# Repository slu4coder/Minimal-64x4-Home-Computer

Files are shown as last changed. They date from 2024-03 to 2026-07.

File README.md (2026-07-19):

# Minimal 64x4 Redux Home Computer

Here is my latest take on 1980's home computer magic: The most computer from the least logic or the shortest way from TTL to Space Invaders.

This is a free and non-commercial project. I am in no way associated with any activies selling the Minimal 64x4 as a product.
Any such activity represents a license violation. Individual licenses apply for hardware and software parts. Please refer to the
applicable documentations for detailed licensing information.

grafik
Introductory video: https://www.youtube.com/watch?v=L1oECH6rPvs

Online emulator: https://editor.p5js.org/slu4coder/sketches/lRq1gyYR2

Reference manual: https://docs.google.com/document/d/1-nDv_8WEG1FrlO3kEK0icoYo-Z-jlhpCMiCstxGOCjQ/edit?usp=sharing

Visit my YouTube channel: https://www.youtube.com/channel/UCXYQcMpUBT3aaQKfmAVJNow

Take a look at these repositories of fellow Minimal 64x4 enthusiasts for more games and fascinating projects:

https://github.com/hans61/Minimal-64x4-Games

https://github.com/hans61/Minimal-64x4-Expansion

https://github.com/michaelkamprath/minimal-64x4-expansion-cards

https://github.com/michaelkamprath/extended-min

https://github.com/hellboy73

FEATURES

● Only 57 74HCxx logic ICs, 2x 6C1008 SRAM, 4x 39SF0x0 FLASH, NO MICROCONTROLLER!

● Textbook 'Von-Neumann' architecture, 8-bit data bus, 16-bit address bus, 24 control signals

● 64KB RAM, 512KB FLASH SSD with file system (format, load, save, dir, delete)

● Monochrome VGA output 400 x 240 pixels, PS/2, expansion port and serial UART interface

● 8MHz CPU clockrate, 1.8Mips - that's more than 4x the commonly quoted Mips value of a 6502 running at 1MHz like in a Commodore C64 or Apple II

● 256 instructions including conditional branching, subroutines, stack, word, long and zero-page operations

● 2 data registers A & B, ALU supporting ADD, SUBTRACT, AND, OR with 3 flags (negative, carry and zero)

● Full native tool-chain: MinOS, text editor, assembler, fast Python-like interpreter 'MIN'

● Cycle-exact emulator, cross-assembler (both for Windows and Linux) and classic games (TETRIS clone, Space Invaders clone, 3D Maze)

If you like this project and want to give something back, you can do so via PayPal. Thanks!

https://paypal.me/CarstenHerting
  
Have fun!

See "CHANGE LOG" for a brief summary of the recent updates.

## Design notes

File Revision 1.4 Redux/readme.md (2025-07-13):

# Revision 1.4 Redux

I have designed the Redux just for fun to make it even more minimalistic: It uses 4 ICs less than the original, which I consider quite an achievement ;-)
It is *not* fully software-compatible (although the differences are slight) to the original Minimal 64x4 since it features an improved and more orthogonal instruction set with some small microcode tweaks. The OS and API have seen improvements, too, resulting in an overall 5% performance gain and a slightly snappier feel.
The serial interface now runs on 7 data bits and the serial OUT command features hardware waiting, which was a fun thing to implement.

The folder 'KiCAD9' contains the schematics and PCB layout files.
For the bill of materials (BOM) please refer to chapter 'Hardware' of the 'Minimal 64x4 Reference Manual'. Follow the link in the root readme.md of this repo.

The folder 'Support' contains the cross-platform assembler und the emulator (Win).
The folder 'Programs' contains native Minimal 64x4 Redux code.

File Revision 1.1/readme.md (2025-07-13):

# Revision 1.1 (Original Release)

The folder 'KiCAD' contains KiCAD 6 schematics. The folder 'KiCAD8' contains the same schematics with minor cosmetic updates, converted to KiCAD8.
For the bill of materials (BOM) please refer to chapter 'Hardware' of the 'Minimal 64x4 Reference Manual'. Follow the link in the root readme.md of this repo.

The folder 'Support' contains the cross-platform assembler und the emulator (Win).
The folder 'Programs' contains native Minimal 64x4 code.

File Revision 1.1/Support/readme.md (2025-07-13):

# Supporting Tool-Chain

o Cross-platform assembler (Windows)

o Emulator (Windows, requires SSD image file 'flash.bin')

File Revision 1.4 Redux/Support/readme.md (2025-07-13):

# Supporting Tool-Chain

o Cross-platform assembler (Windows, Linux)

o Emulator (Windows, Linux, requires SSD image file 'flash.bin')

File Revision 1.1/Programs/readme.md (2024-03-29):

# Native Software of the 'Minimal 64x4 Home Computer'

o '.asm' denotes assembly source code.

o '.min' denotes 'Min' source code.

o 'manual.txt' is displayed by the 'Minimal 64x4' upon entering 'show manual'.

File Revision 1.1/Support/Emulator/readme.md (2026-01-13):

# Cycle-exact Minimal 64x4 Emulator (C++/OpenGL)

PLEASE NOTE: The FLASH image file 'flash.bin' (see section 'Revision .../FLASH Images') needs to reside in the same directory as the emulator.

On some graphic cards, 60Hz VSYNC is not detected correctly. In that case, set the frame rate manually to 60Hz from within your graphic card's control center.

Please note that the C++/OpenGL source code of this emulator (~6000 lines of code) is intentionally not available for download.

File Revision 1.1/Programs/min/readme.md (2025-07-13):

# 'Min' Programs

'Min' is a Python-like high-level programming language running natively on the 'Minimal 64x4'.
The interpreter [min.asm](../asm/min.asm) assembly source code is located in the '../asm' section.

See Min's EBNF language definition for more information.

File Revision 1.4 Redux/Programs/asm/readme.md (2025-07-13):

# Native Software of the 'Minimal 64x4 Redux'

o '.asm' denotes assembly source code.

o '.min' denotes 'Min' source code.

o 'manual.txt' is displayed by the 'Minimal 64x4 Redux' upon entering 'show manual'.

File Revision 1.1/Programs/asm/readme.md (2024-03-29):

# Assembly Programs

Assembly code (OS, native tool-chain, games, demos) written for the 'Minimal 64x4'.

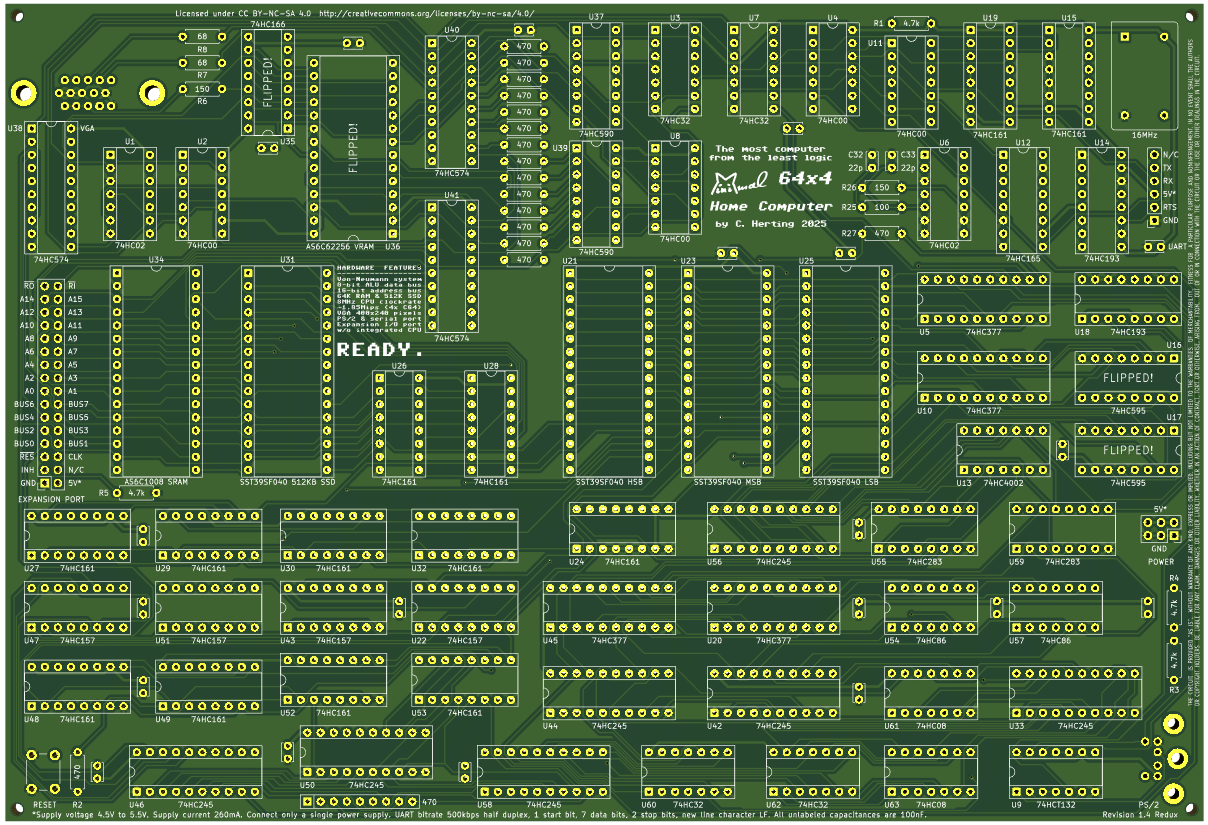
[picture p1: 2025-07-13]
Revision 1.4 Redux/Layout.png

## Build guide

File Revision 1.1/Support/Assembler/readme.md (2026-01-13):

Cross-platform assembler of the Minimal 64x4 written in C++.

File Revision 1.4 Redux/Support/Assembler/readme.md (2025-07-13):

# Cross-platform assembler

Build with: g++ asm.cpp -O2 -oasm.exe -s

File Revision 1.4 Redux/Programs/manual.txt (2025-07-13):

-------------------------------------------------
MINIMAL 64x4 1.4 Redux  COMPUTER  MANUAL  by slu4
-------------------------------------------------

Welcome to the 'MINIMAL 64x4'. This file provides
a brief introduction on how to use this computer.

1. OS COMMANDS (1/2)

The  'MinOS'  operating system loads and executes
any entered  filename as a  separate program.  So
any file can be considered an 'OS command'. MinOS
comes with the following built-in commands
(parameters in square [] brackets are optional):

'run' [<x>] starts execution at hex address <x>
            (default start address is 0x0100).

'dir'  displays the file directory of the SSD.

'del <file>'  deletes a file on the SSD.

'show <file>'  displays a text file page by page.

'format'  formats  SSD  user area (banks 3..127).

'defrag'  frees up unused  SSD storage fragments.

'memset <x> <y> <d>' fills RAM <x>..<y> with <d>.%
1. OS COMMANDS (2/2)

'mon [<x>]'  starts  a  memory  monitor [at <x>].
  ESC        exits the monitor to the  OS prompt.
  <x>        changes the  monitor address to <x>.
  k<x>       sets the bank register to <x>.
  [<x>].<y>  displays an address range.
  :<d>[ <d>] deposits  <d> at  current address++.
  #<x>       activates SSD bank <x>, 0x80 for RAM
  <x>, <y>, <d> can be a HEX value '0' to 'ffff'.

'memmove <x> <y> <z>'  moves memory area <x>..<y>
  to <z>. Source and destination may overlap.

'receive'  receives an 'Intel HEX File' you paste
  via UART terminal and writes the data into RAM.
  OS FLASH images generated by  'asm os.asm'  are
  automatically detected and written 'in situ' to
  the FLASH sectors 0..2.

'save <x> <y> <name>'  saves memory area <x>..<y>
  under the filename <name> onto the SSD.
  
After boot-up,  MinOS  searches for a  batch file
'autostart'. Any filename in 'autostart'  will be
executed as a subroutine.
To force booting without 'autostart', hold RESET,
press ESC on the PS/2 keyboard and release RESET.%
2. MEMORY MAP

0x0000..0x0fff  4KB FLASH/RAM  depending on bank:
                0x00:        OS kernel image
                0x01:        OS data
                0x02:        OS command files
                0x03..0x7f:  user SSD storage
                0x80..0xff:  RAM (FLASH disabled)

0x0000..  00ff ZERO PAGE (256 bytes):
  0080..  00ff OS variables
  00cd..  00fe OS line input buffer (50 bytes)
  00ff         system register

0x0000..0x3fff 16KB RAM:
  0100..  0fff text editor 'edit'
  1000..  1fff smart assembler 'asm'
  1000..  3fff high-level language 'min'

0x4000..0x7fff 16KB VIDEO RAM (64 x 256 bytes):
  430c         start of 400 x 240 pixels viewport

0x8000..0xefff 28KB RAM:
  f000..  fbff OS kernel & API functions
  fc00..  fdff OS commands
  fe00..  feff reserved for expansion cards

0xff00..0xffff CPU STACK (256 bytes):
  ffff         stack pointer LSB%
3. TEXT EDITOR 'edit [<file>]'

The text editor resides  in RAM at 0x0100..0x0fff
and also uses  0x3f00..0x3fff for temporary data.
Text data  is stored from address 0x8000 onwards.
Once  loaded,  the  editor  can  be  restarted by
typing 'run', preserving your text document.

CTRL q   or ESC quits the editor.
CTRL n   Starts a new document.

CTRL l   Dialog line to input a filename to load.
CTRL s   Dialog line to  save the text as a file.

CTRL a  Marks the start of a text block.
CTRL x  Marks the end of a  text blocks  and cuts
        out the  marked text block to  clipboard.
CTRL c  Marks the end of a text block  and copies
        the marked text block to clipboard.
CTRL v  Inserts  a text block  from  clipboard at
        the current cursor position.

CTRL r  Receives text via UART and  inserts it at
        the current position.  Press  ESC to end.
CTRL t  Transmits the current text file via UART.%
4. ASSEMBLER 'asm [<file>]' (1/2)

ASM  is MINIMAL's  native assembler.  To assemble
a sourcefile <file> from SSD, type  'asm <file>'.
In case  the source text  already resides  in RAM
you can simply assemble with 'asm'.  ASM uses the
RAM  area  0x1000..0x1fff.

ASM uses two pointers: a memory counter (MC)  and
a program counter (PC).  Data is  always  emitted
to MC. Labels  are  defined  with respect to  PC.
Default for MC and PC is address 0x2000.

#emit       starts data emission to MC
#mute       mutes data emission to MC, but
            keeps  updating  PC while  assembling
*           alias for  current  MC  address value
#org <addr> sets PC,  sets MC  only when emitting
#page       alligns PC (MC) to the next page

Mnemonics and HEX digits are not case-sensitive.
Separate  elements with  a space  and/or comma.%
4. ASSEMBLER 'asm [<file>]' (2/2)

label:      defines a label as the current PC
; comment   makes  the rest of the line a comment
<label      LSB operator  (at element start only)
>label      MSB operator  (at element start only)
0x0a,123    HEX and DEC byte values
0xff10      HEX word (little-endian) = 0x10, 0xff
'A'         character,  equivalent  to 65 or 0x41
'AAA',0     string,  equivalent to  65, 65, 65, 0
addr+off-1  handling of simple expressions
*           alias for the value of current MC

Example:
#org 0x2000             ; sets start address
            LDI 0xff    ; loads 0xff into A
            SDB 0x430c  ; deposits A=0xff in VRAM
            JPA 0xf003  ; jumps back to OS prompt%
5. HIGH-LEVEL LANGUAGE 'min [<file>]'

MIN is a fast high-level Python-like interpreted
programming language. 'min <file>' executes your
program from SSD. 'min' starts a program already
located at 0x1000.
MIN occupies the RAM area 0x1000..0x2dff and uses
0x2e00..0x3fff for runtime data storage.

The following list of features and commands will
get you started (for more information see the
exact language definition in EBNF):

o Python-style code block indentation (2 SPACES)
o control structure 'if-elif-else', 'while-break'
o variables with C-style static explicit typing
o data types 'char' (8-bit) and 'int' (16-bit)
o local and global variables, @ address operator
o 'def-return', C-style '&' variable references
o 'call ..' for assembly/API routine integration
o full expression handling including '+=', '-='
o bitwise/logical operators 'and/or/xor/not'
o [..|..] element access and '_' concatenation
o decimal and HEX '0xffff' numbers, ".." strings
o print(..) for text and decimal number output
o 'use "<library>"' for recursive file import
o 'std.min' library implements: pos, rnd, clear,
   line, rect, dot, str, len, strcmp, key, etc.%
6. HARDWARE SPECIFICATION

CPU system clock rate........................8MHz

Supply voltage range.................4.5V to 5.5V

Supply current.............typically 220mA @ 5.0V

UART bit rate.............................500Kbps

UART format 1 start bit, 7 data bits, 2 stop bits
            no parity bit, newline LF (0x0a)

UART transmit delay.....................10ms/line

Set the terminal emulation to 50 x 30 characters.

                    Have fun!%

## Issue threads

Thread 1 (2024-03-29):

Remove dot in opcodes

Kroc, 2024-03-29:
I observed that where a dot is included in an opcode to purely separate `A = A ? B` forms vs. `B = B ? A` forms (that is, accumulator as destination vs. accumulator as source) that these would read more naturally if the destination indicator was put first just as it is implied to be accumulator in non-dotted opcodes, e.g. `ANZ: A = A & Z` but `AN.Z` would be `ZAN: Z = Z & A`. Since the type comes first, I have observed only the following letters used currently in dotted-opcodes: B, L, R, T & Z. **Because there are no current opcodes beginning with B, T or Z, and the dotted-opcodes for L & R would not conflict when swapped in this manner, there would be no name conflicts and all 256 opcodes would fit into 3 letters!**

slu4coder, 2024-03-30:
Thanks for digging into this. Dot instructions are converted to non-dot instructions internally just as you have proposed, i. e. AN.Z is first translated into ZAN and only then assembled. You might as well (whatever you like more) use ZAN as an opcode in your sources. I personally prefer the dot notation since it exposes the general function of an instruction at the start of the mnemonic.

Closed 2024-03-30.

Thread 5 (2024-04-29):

Bootstrapping

friendlyanon, 2024-04-29:
I think this is an excellent project, however it relies on the user having a flash programmer available and some prebuilt binaries to get started. I think it would be even better if there was a way to start putting code on the device from basically nothing.

I haven't fully studied the design and timings of the hardware, but would it be possible to allow single-stepping the clock and putting bytes on the data bus using a DIP switch maybe? That would enable the user to start putting executable code on the machine manually. Think [stage0](https://github.com/oriansj/stage0).

friendlyanon, 2024-05-07:
Doesn't need to be done every time on boot, since there is flash storage to put bytes on. I have also realized in the meantime that a lot of this machine relies on said flash having the control ROM on it to be able to "push its own buttons" to quote you.

At least that gives me the motivation to design something of my own, even its sole purpose is to write the control ROM to flash storage for some other machine ;)

I find the simplicity and performance in spite of the low transistor count of M64x4 very compelling. The hypothetical scenario of being able help digital computing spring into life basically from nothing but pushing some buttons and toggling some switches is even more compelling to me.

Closed 2024-05-07.

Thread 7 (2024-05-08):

Resistor watts?

joelburton, 2024-05-08:
The BOM lists 0.6W resistors, but it's a lot easier to find 0.5W ones that fit well with the very tight spacing on the PCB. Would 0.5W work?

Thanks!

slu4coder, 2024-05-12:
That should not be a problem.

nateo87, 2024-05-24:
Follow-up question - is even 0.5w rated resistors strictly necessary? I'm using 1/4w resistors in mine (which I'm currently having keyboard issues with).

slu4coder, 2024-05-24:
Let's do the math. The resistors seeing the highest load are the 470 Ohm resistors in the VGA circuit, since they potentially have a voltage of 5V across them. Let's assume they see the full load 100% of the time (which they don't). Using Ohm's law I = U/R, it follows that the maximum current through these resistors is ~10mA. By using P = U*I we have P_max = 50mW. If you are using 1/4W rated resistors that mean your P_max is 250mW. There are smaller resistors present in the circuit but they do not see 5V. Please open a new discussion if you want to reach out for help concerning a potential keyboard issue.

Closed 2024-05-12.

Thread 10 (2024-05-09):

Assembler gives invalid expression error

bobbarnes1981, 2024-05-09:
I think there could be a bug in asm.exe

this code works

```
#org 0x2000
LDI 0x0b
```

but this code fails

```
#org 0x2000
LDI 0x0B
```
ERROR in line 2: Invalid expression.

slu4coder, 2024-05-12:
I've just confirmed this. As you point out correctly, this is only an issue in the cross-assembler asm.exe, not in the native Minimal 64x4 version. Will look into this.

slu4coder, 2024-05-12:
Thanks for pointing this out. I've found and fixed this bug and just re-uploaded asm.exe, asm.cpp and the emulator.
Cheers!

Closed 2024-05-12.

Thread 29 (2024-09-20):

Not quite understanding pixel variables

nateo87, 2024-09-20:
First off, I love this thing.

Second,  I'm just now learning assembly for myself and I'm having a lot of fun experimenting with code. Your assembler and editors make it so easy. But I'm having a bit of trouble with the subroutine _SetPixel.
It seems that setting variable 'xa' to 0 (in this case using "MIZ 00,xa") puts my dot two-thirds across the screen, while I would have expected it to go all the way to the left. Is there something I'm not understanding about how the screen gets plotted.
The variable 'ya' behaved exactly as I expected it to.
I've scoured the manual as well as os.asm to see if I could make sense of it for myself, but I'm stumped. Why is the x plot going so far up the screen?

nateo87, 2024-09-21:
Nevermind - I was storing 'xa' as a byte instead of a word *facepalm*

I suppose this is how we learn!

Closed 2024-09-21.

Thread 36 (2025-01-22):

separate

mix127, 2025-01-22:
Is possible to separate 'CPU' procesor from device motherboard?

You will be able to replace the interface in the future (a better screen , another keyboard, maybe a disk or memory) independently. Improving and optimizing the processor would not require changing external devices. Such a motherboard that includes different hardware could even be produced by others.

defdefred, 2025-01-28:
where is no CPU :-)

mix127, 2025-01-28:
ok, You are right.
I think about everything what is not interface. VGA, screen, keyboard etc. I think about separate interface, memory, keyboard to one part and other to other.

Very simple example. Many big computers have memory bank like a memory card or GPU card. Pluging directly to motherboard with interface. You project will be faster when You are put faster memory.

Manufacturing an entire computer is quite difficult. You will find many helpers and speed up the computer if you divide the computer into modules.

One module will deal with the screen and keyboard another with calculations. Then the entry threshold and improving the design, making it faster will become easier for others.

slu4coder, 2025-02-06:
Hmm, I see your point. However, IMHO this system does not lend itself very well for this kind of modularity. It is in its entirety *highly optimized* as a single piece of hardware just barely holding together what it can do. Modularity would require significant overhead. However, I will release a stripped down "UART only" version of the CPU in the future.

Closed 2025-02-06.

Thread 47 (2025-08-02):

Will the emulator be open-source?

tseemann, 2025-08-02:
```
Please note that the C++/OpenGL source code of this emulator (~6000 lines of code) is intentionally not available for download.
```

Was interested to understand your reason for this?

I am hesitant to run an unverified binary from the web.

slu4coder, 2025-08-02:
I understand your concerns. You might refrain to a virtual machine to mitigate the risk in your case.

I am about to release a new version of my Minimal UART Computer, which is a simplified version of the Minimal 64x4. The emulator for that project will be open source to show how such a system can be implemented efficiently to speeds up to 50MHz.

Closed 2025-08-02.

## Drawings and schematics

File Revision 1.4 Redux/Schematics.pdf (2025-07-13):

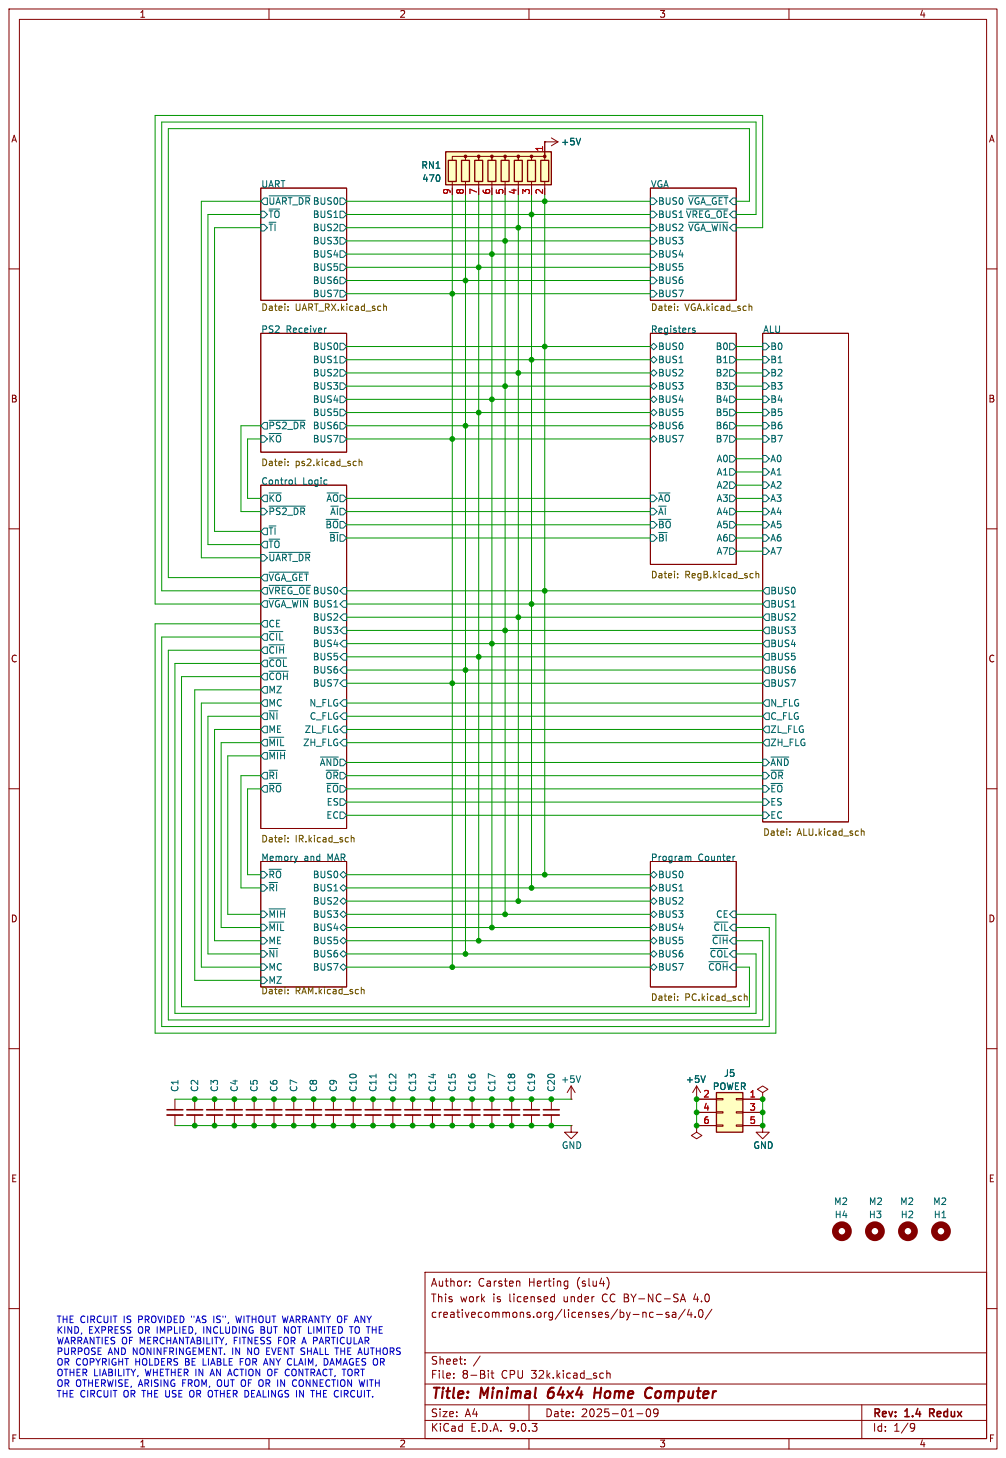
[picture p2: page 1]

~{TI} UART Datei: UART_RX.kicad_sch BUS0 BUS1 BUS2 BUS3 BUS4 BUS5 BUS6 BUS7 ~{RO} ME
~{UART_DR}

~{VGA_WIN} VGA Datei: VGA.kicad_sch BUS0 BUS1 BUS2 BUS3 BUS4 BUS5 BUS6 BUS7 ~{TO}

~{RI} MCMZ Memory and MAR

~{COL} BUS3 BUS1 BUS0 BUS2 BUS4 BUS6 BUS7 BUS5 Program Counter Datei: PC.kicad_sch

THE CIRCUIT IS PROVIDED "AS IS", WITHOUT WARRANTY OF ANY
KIND, EXPRESS OR IMPLIED, INCLUDING BUT NOT LIMITED TO THE WARRANTIES OF MERCHANTABILITY, FITNESS FOR A PARTICULAR

PURPOSE AND NONINFRINGEMENT. IN NO EVENT SHALL THE AUTHORS OR COPYRIGHT HOLDERS BE LIABLE FOR ANY CLAIM, DAMAGES OR OTHER LIABILITY, WHETHER IN AN ACTION OF CONTRACT, TORT OR OTHERWISE, ARISING FROM, OUT OF OR IN CONNECTION WITH

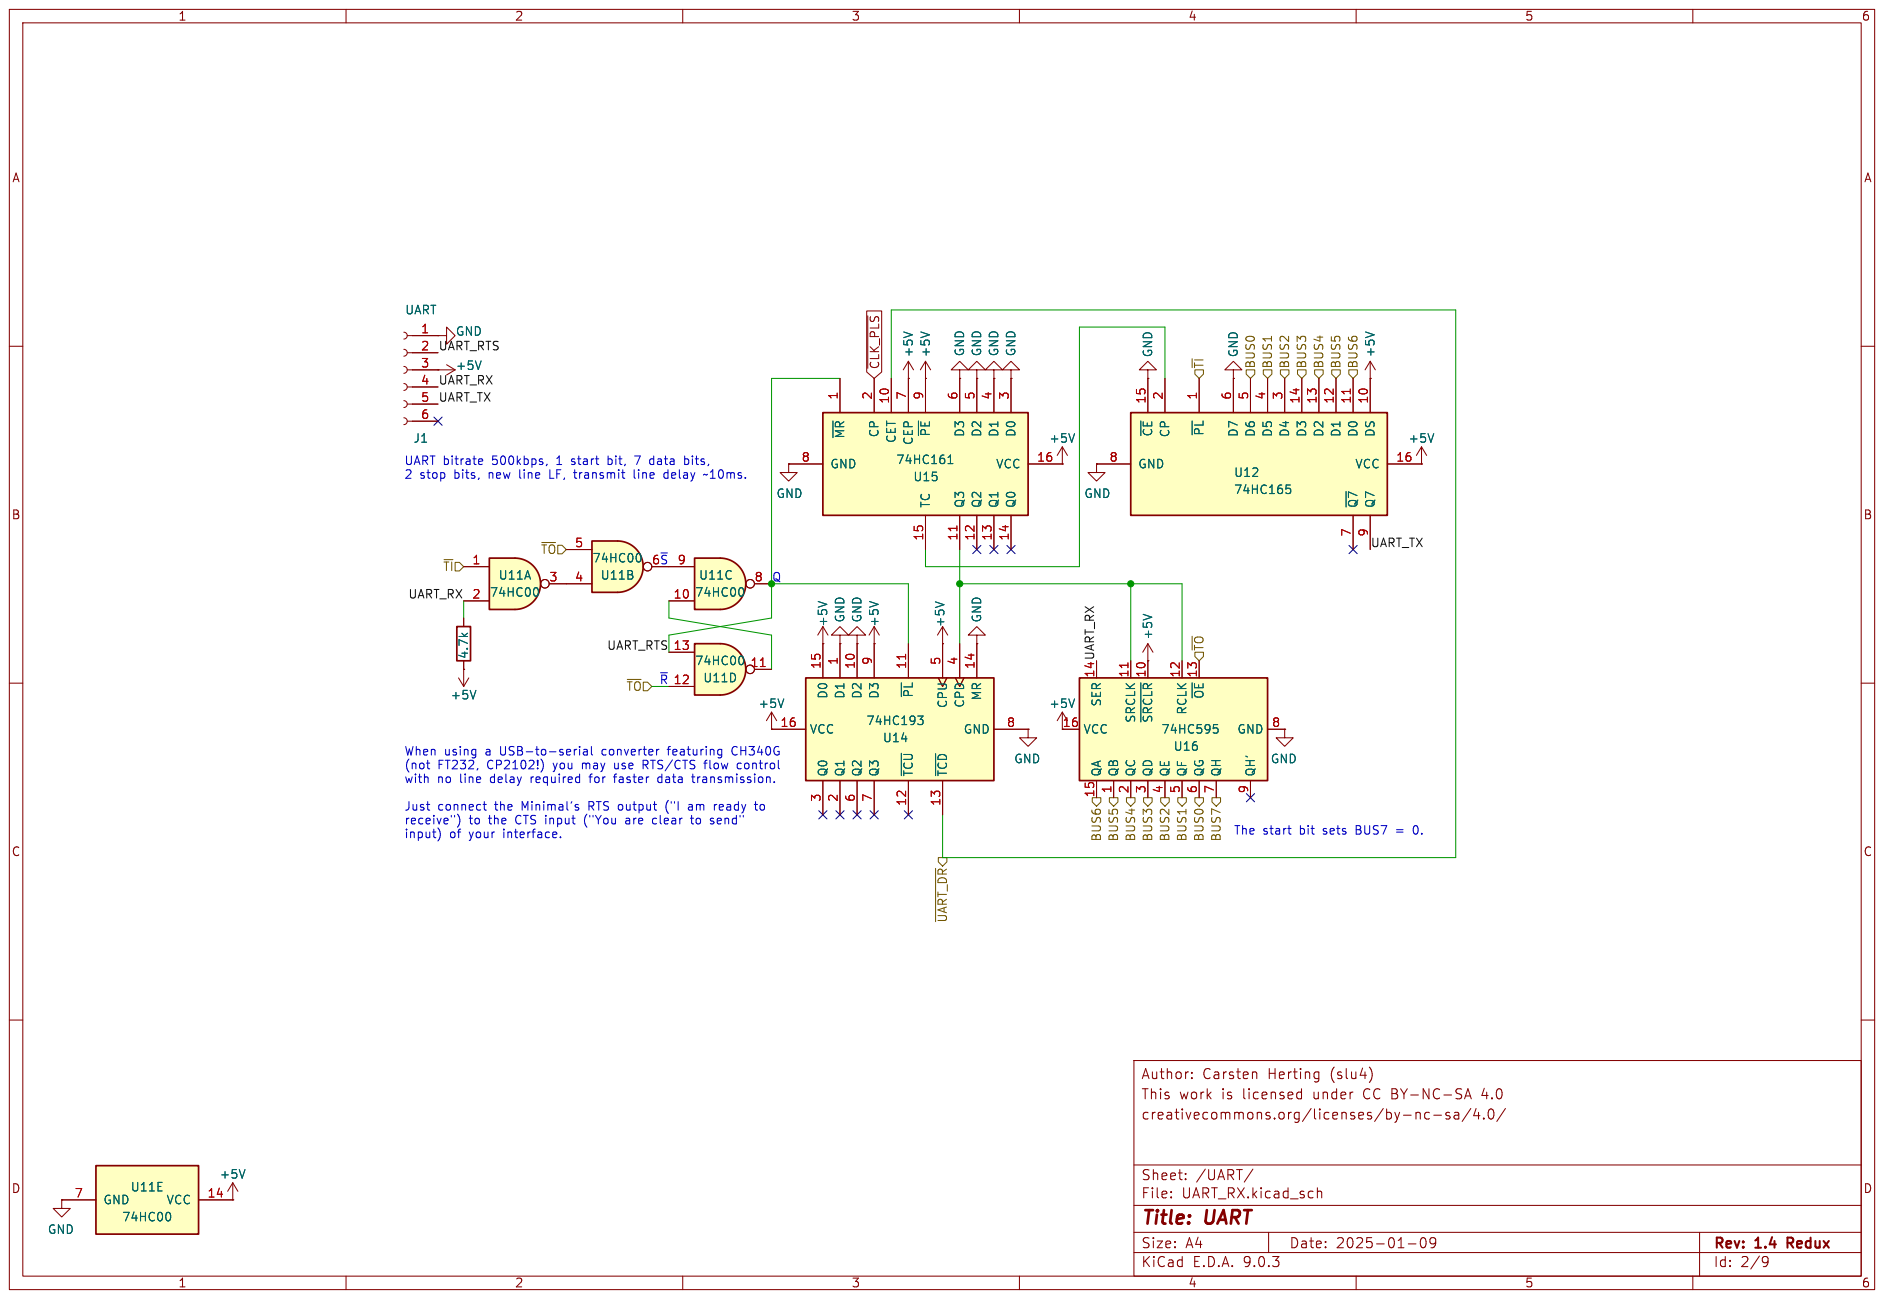
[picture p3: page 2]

2 ~{MR} 1 VCC 16 GND 8 Q0 14 Q1 13 Q2 12 Q3 11 TC 15 GND +5V +5V GND

7 QH' 9 +5V GND GND GND

2 ~{MR} 1 VCC 16 GND 8 Q0 14 Q1 13 Q2 12 Q3 11 TC 15 U15

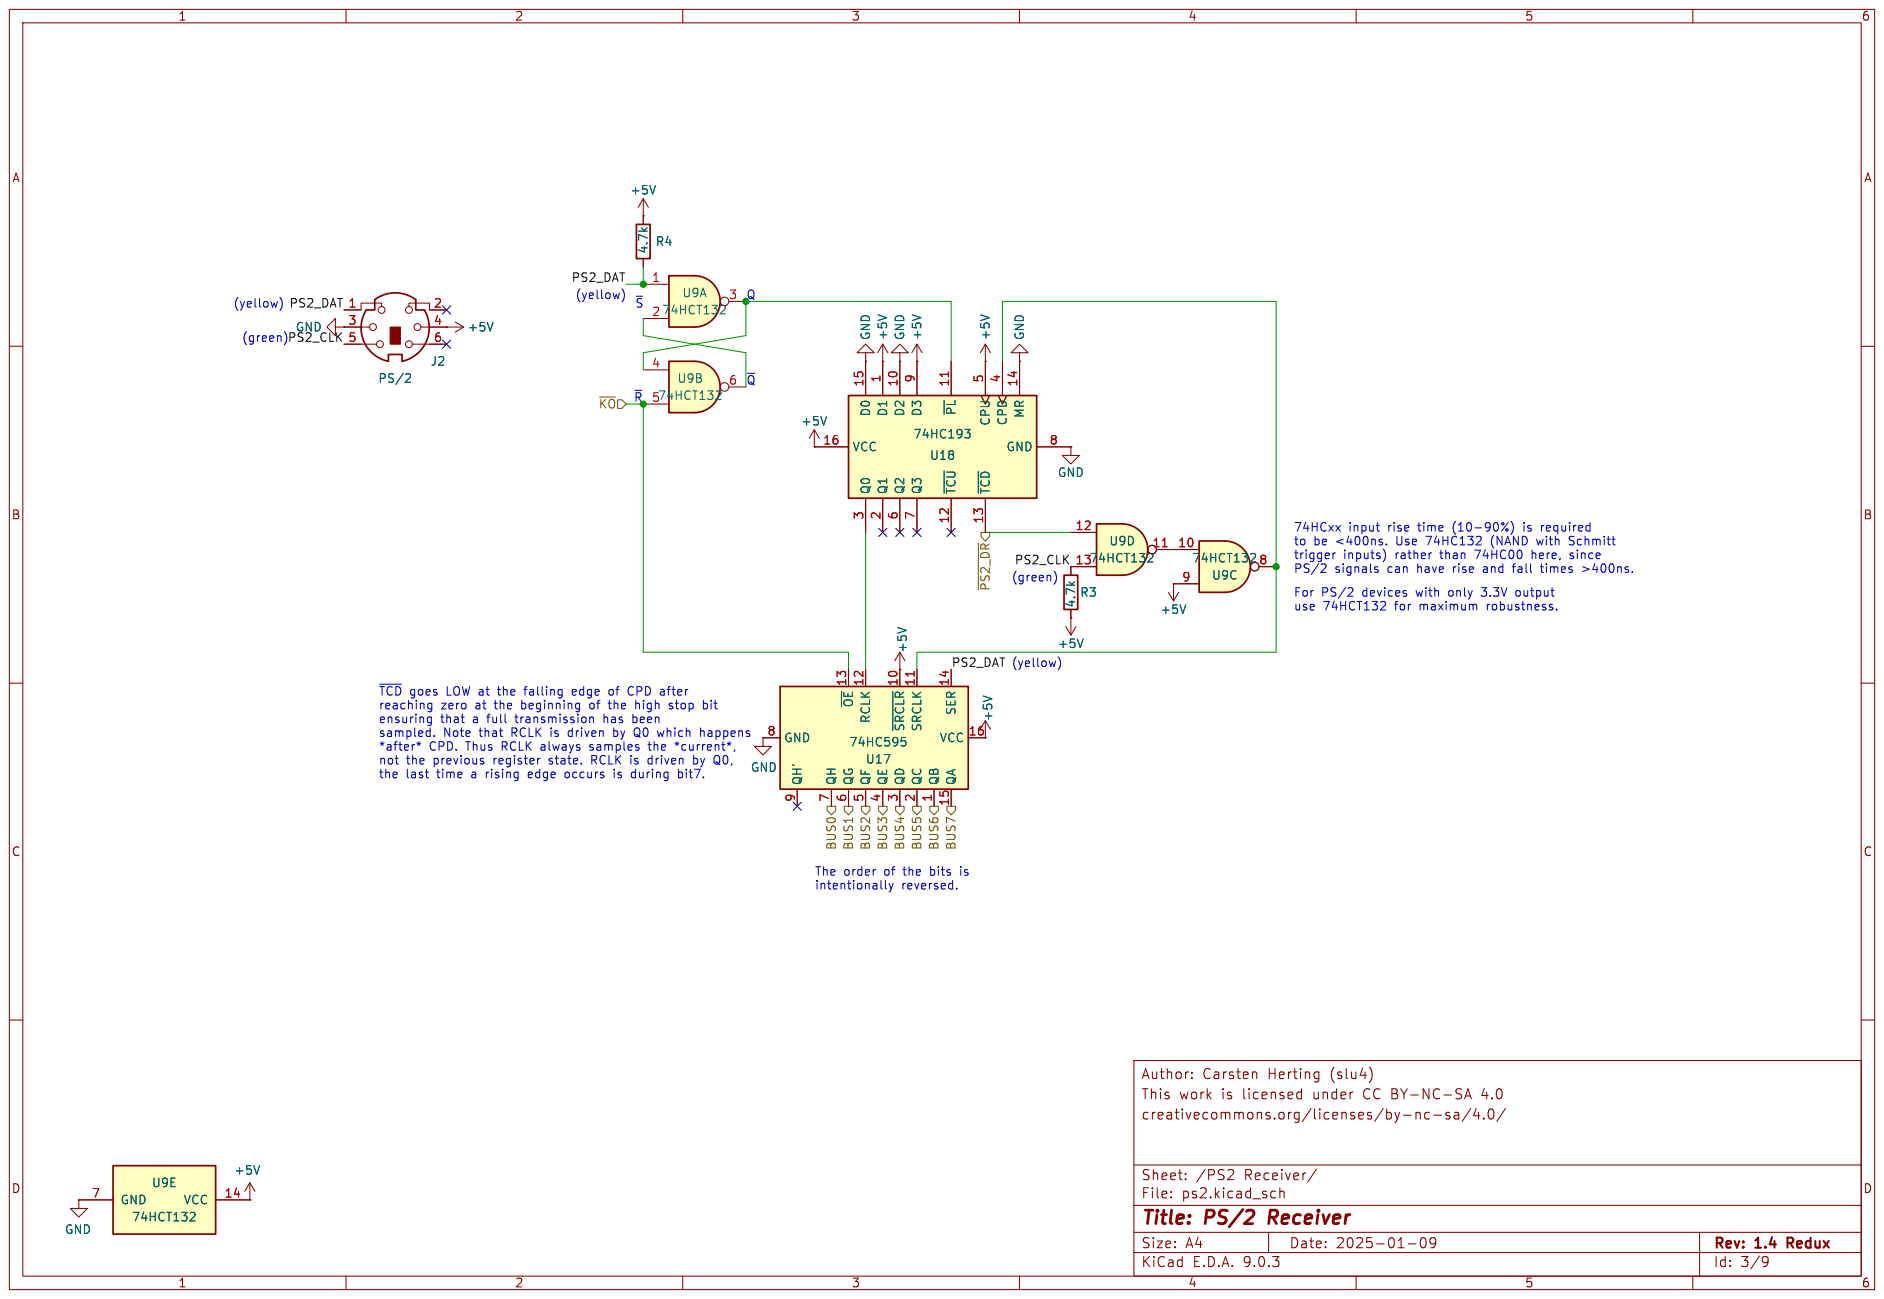
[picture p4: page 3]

7 ~{TCU} 12 ~{TCD} 13 GND +5V +5V GND

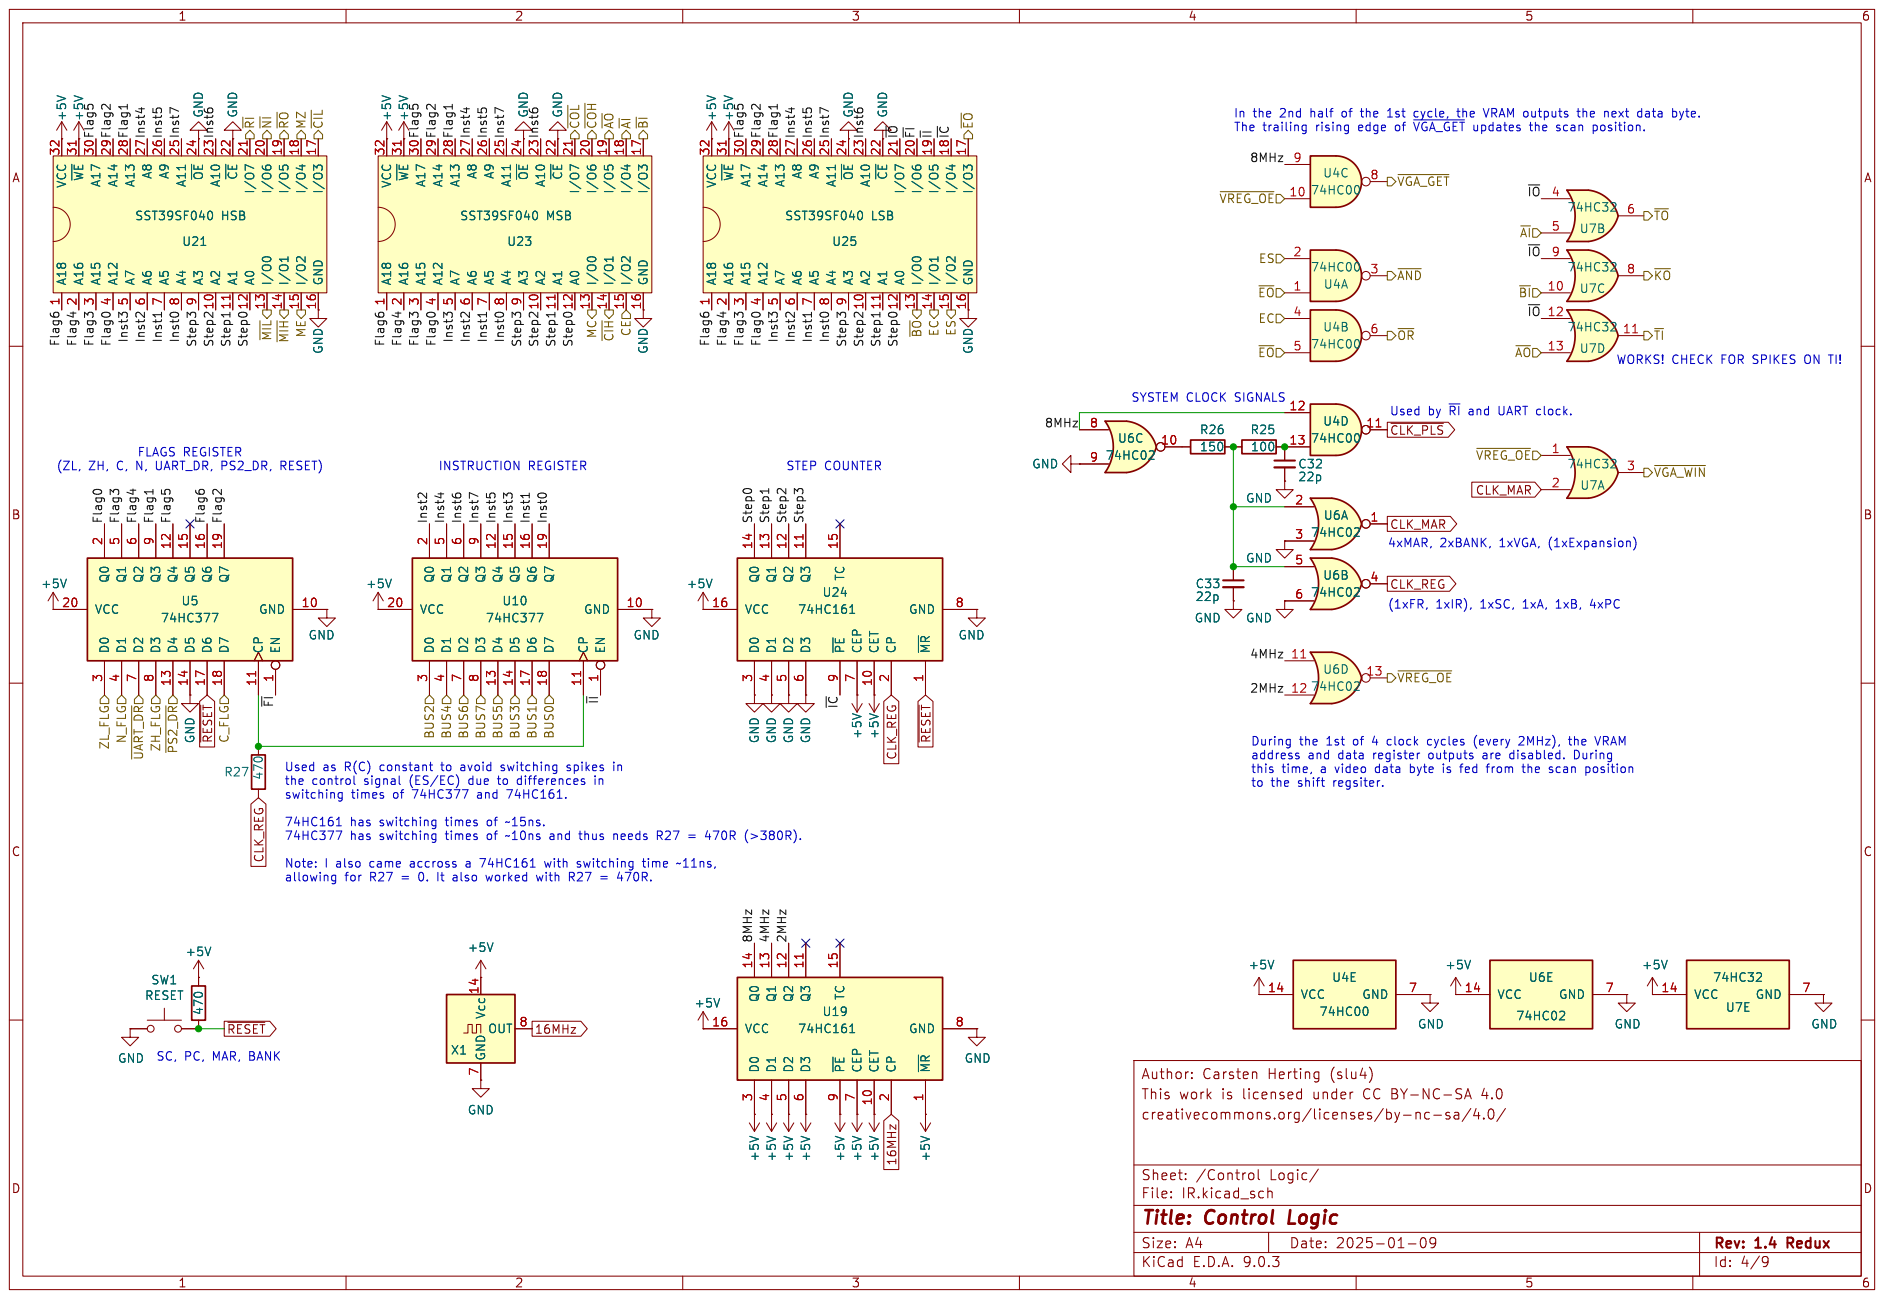
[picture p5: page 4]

9 A2 10 A1 11 A0 12 I/O0 13 I/O1 14 I/O2 15 GND 16 VCC 32 ~{WE}31 A17 30 A14 29 A13 28 A8 27 A9 26 A11 25 ~{OE}24 A10 23 ~{CE}22 I/O7 21 I/O6 20 I/O5 19 I/O4 18 I/O3 17 +5V +5V GND GND +5V +5V

9 A2 10 A1 11 A0 12 I/O0 13 I/O1 14 I/O2 15 GND 16 VCC 32 ~{WE}31 A17 30 A14 29 A13 28 A8 27 A9 26 A11 25 ~{OE}24 A10 23 ~{CE}22 I/O7 21 I/O6 20 I/O5 19 I/O4 18 I/O3 17 GND GND GND +5V U25 SST39SF040 LSB A18

9 A2 10 A1 11 A0 12 I/O0 13 I/O1 14 I/O2 15 GND 16 VCC 32 ~{WE}31 A17 30 A14 29 A13 28 A8 27 A9 26 A11 25 ~{OE}24 A10 23 ~{CE}22 I/O7 21 I/O6 20 I/O5 19 I/O4 18 I/O3 17 +5V GND GND

9 A2 10 A1 11 A0 12 I/O0 13 I/O1 14 I/O2 15 GND 16 VCC 32 ~{WE}31 A17 30 A14 29 A13 28 A8 27 A9 26 A11 25 ~{OE}24 A10 23 ~{CE}22 I/O7 21 I/O6 20 I/O5 19 I/O4 18 I/O3 17 U21 SST39SF040 HSB

9 A2 10 A1 11 A0 12 I/O0 13 I/O1 14 I/O2 15 GND 16 VCC 32 ~{WE}31 A17 30 A14 29 A13 28 A8 27 A9 26 A11 25 ~{OE}24 A10 23 ~{CE}22 I/O7 21 I/O6 20 I/O5 19 I/O4 18 I/O3 17 U23 SST39SF040 MSB GND

9 A2 10 A1 11 A0 12 I/O0 13 I/O1 14 I/O2 15 GND 16 VCC 32 ~{WE}31 A17 30 A14 29 A13 28 A8 27 A9 26 A11 25 ~{OE}24 A10 23 ~{CE}22 I/O7 21 I/O6 20 I/O5 19 I/O4 18 I/O3 17 U25 SST39SF040 LSB C33

9 Q4 12 Q5 15 Q6 16 Q7 19 GND GND GND GND

2 ~{MR} 1 VCC 16 GND 8 Q0 14 Q1 13 Q2 12 Q3 11 TC 15 U24

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

74HC02 GND GND GND GND

During the 1st of 4 clock cycles (every 2MHz), the VRAM
this time, a video data byte is fed from the scan position
to the shift regsiter.

2 ~{MR} 1 VCC 16 GND 8 Q0 14 Q1 13 Q2 12 Q3 11 TC 15 U19

2 ~{MR} 1 VCC 16 GND 8 Q0 14 Q1 13 Q2 12 Q3 11 TC 15 GND +5V +5V +5V +5V +5V +5V +5V +5V

SC, PC, MAR, BANK
GND

Id: 4/9 Title: Control Logic

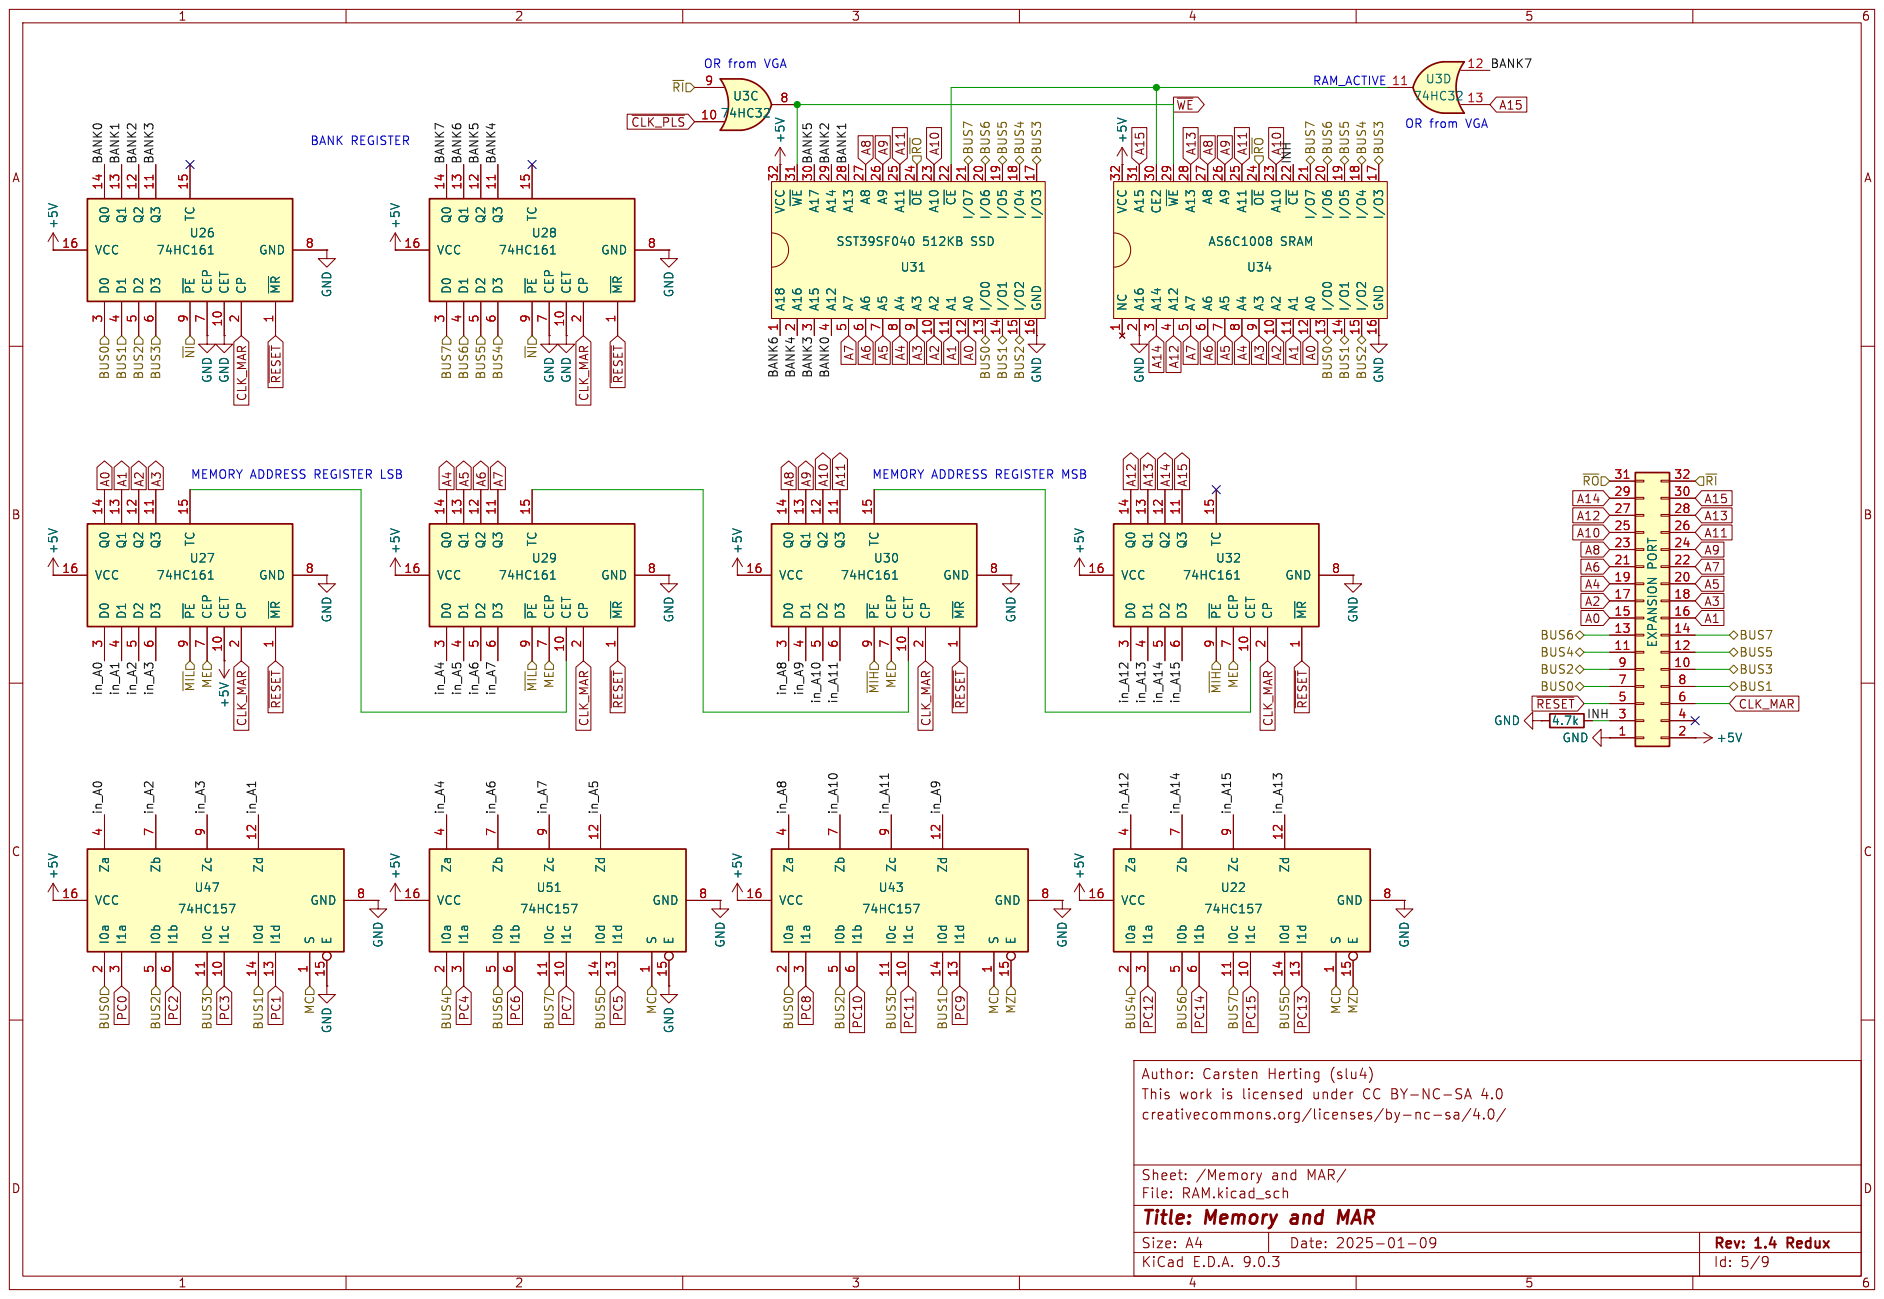
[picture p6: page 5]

2 ~{MR} 1 VCC 16 GND 8 Q0 14 Q1 13 Q2 12 Q3 11 TC 15 +5V U3C

2 ~{MR} 1 VCC 16 GND 8 Q0 14 Q1 13 Q2 12 Q3 11 TC 15 GND +5V GND GND

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

2 ~{MR} 1 VCC 16 GND 8 Q0 14 Q1 13 Q2 12 Q3 11 TC 15 +5V +5V GND +5V +5V U51

2 ~{MR} 1 VCC 16 GND 8 Q0 14 Q1 13 Q2 12 Q3 11 TC 15 U26

9 A2 10 A1 11 A0 12 I/O0 13 I/O1 14 I/O2 15 GND 16 VCC 32 ~{WE}31 A17 30 A14 29 A13 28 A8 27 A9 26 A11 25 ~{OE}24 A10 23 ~{CE}22 I/O7 21 I/O6 20 I/O5 19 I/O4 18 I/O3 17 U31 SST39SF040 512KB SSD D0

9 A2 10 A1 11 A0 12 I/O0 13 I/O1 14 I/O2 15 GND 16 VCC 32 A15 31 CE2 30 ~{WE}29 A13 28 A8 27 A9 26 A11 25 ~{OE}24 A10 23 ~{CE}22 I/O7 21 I/O6 20 I/O5 19 I/O4 18 I/O3 17 U34 AS6C1008 SRAM +5V I0a

2 ~{MR} 1 VCC 16 GND 8 Q0 14 Q1 13 Q2 12 Q3 11 TC 15 U28

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

2 ~{MR} 1 VCC 16 GND 8 Q0 14 Q1 13 Q2 12 Q3 11 TC 15 +5V GND +5V GND GND GND

2 ~{MR} 1 VCC 16 GND 8 Q0 14 Q1 13 Q2 12 Q3 11 TC 15 U27

2 ~{MR} 1 VCC 16 GND 8 Q0 14 Q1 13 Q2 12 Q3 11 TC 15 U47

2 ~{MR} 1 VCC 16 GND 8 Q0 14 Q1 13 Q2 12 Q3 11 TC 15 U29

2 ~{MR} 1 VCC 16 GND 8 Q0 14 Q1 13 Q2 12 Q3 11 TC 15 U30

2 ~{MR} 1 VCC 16 GND 8 Q0 14 Q1 13 Q2 12 Q3 11 TC 15 GND GND GND

2 ~{MR} 1 VCC 16 GND 8 Q0 14 Q1 13 Q2 12 Q3 11 TC 15 U32

7 Zc 9 Zd 12 +5V GND GND +5V U27

7 Zc 9 Zd 12 GND +5V EXPANSION PORT

7 Zc 9 Zd 12 GND +5V GND

Id: 5/9 Title: Memory and MAR

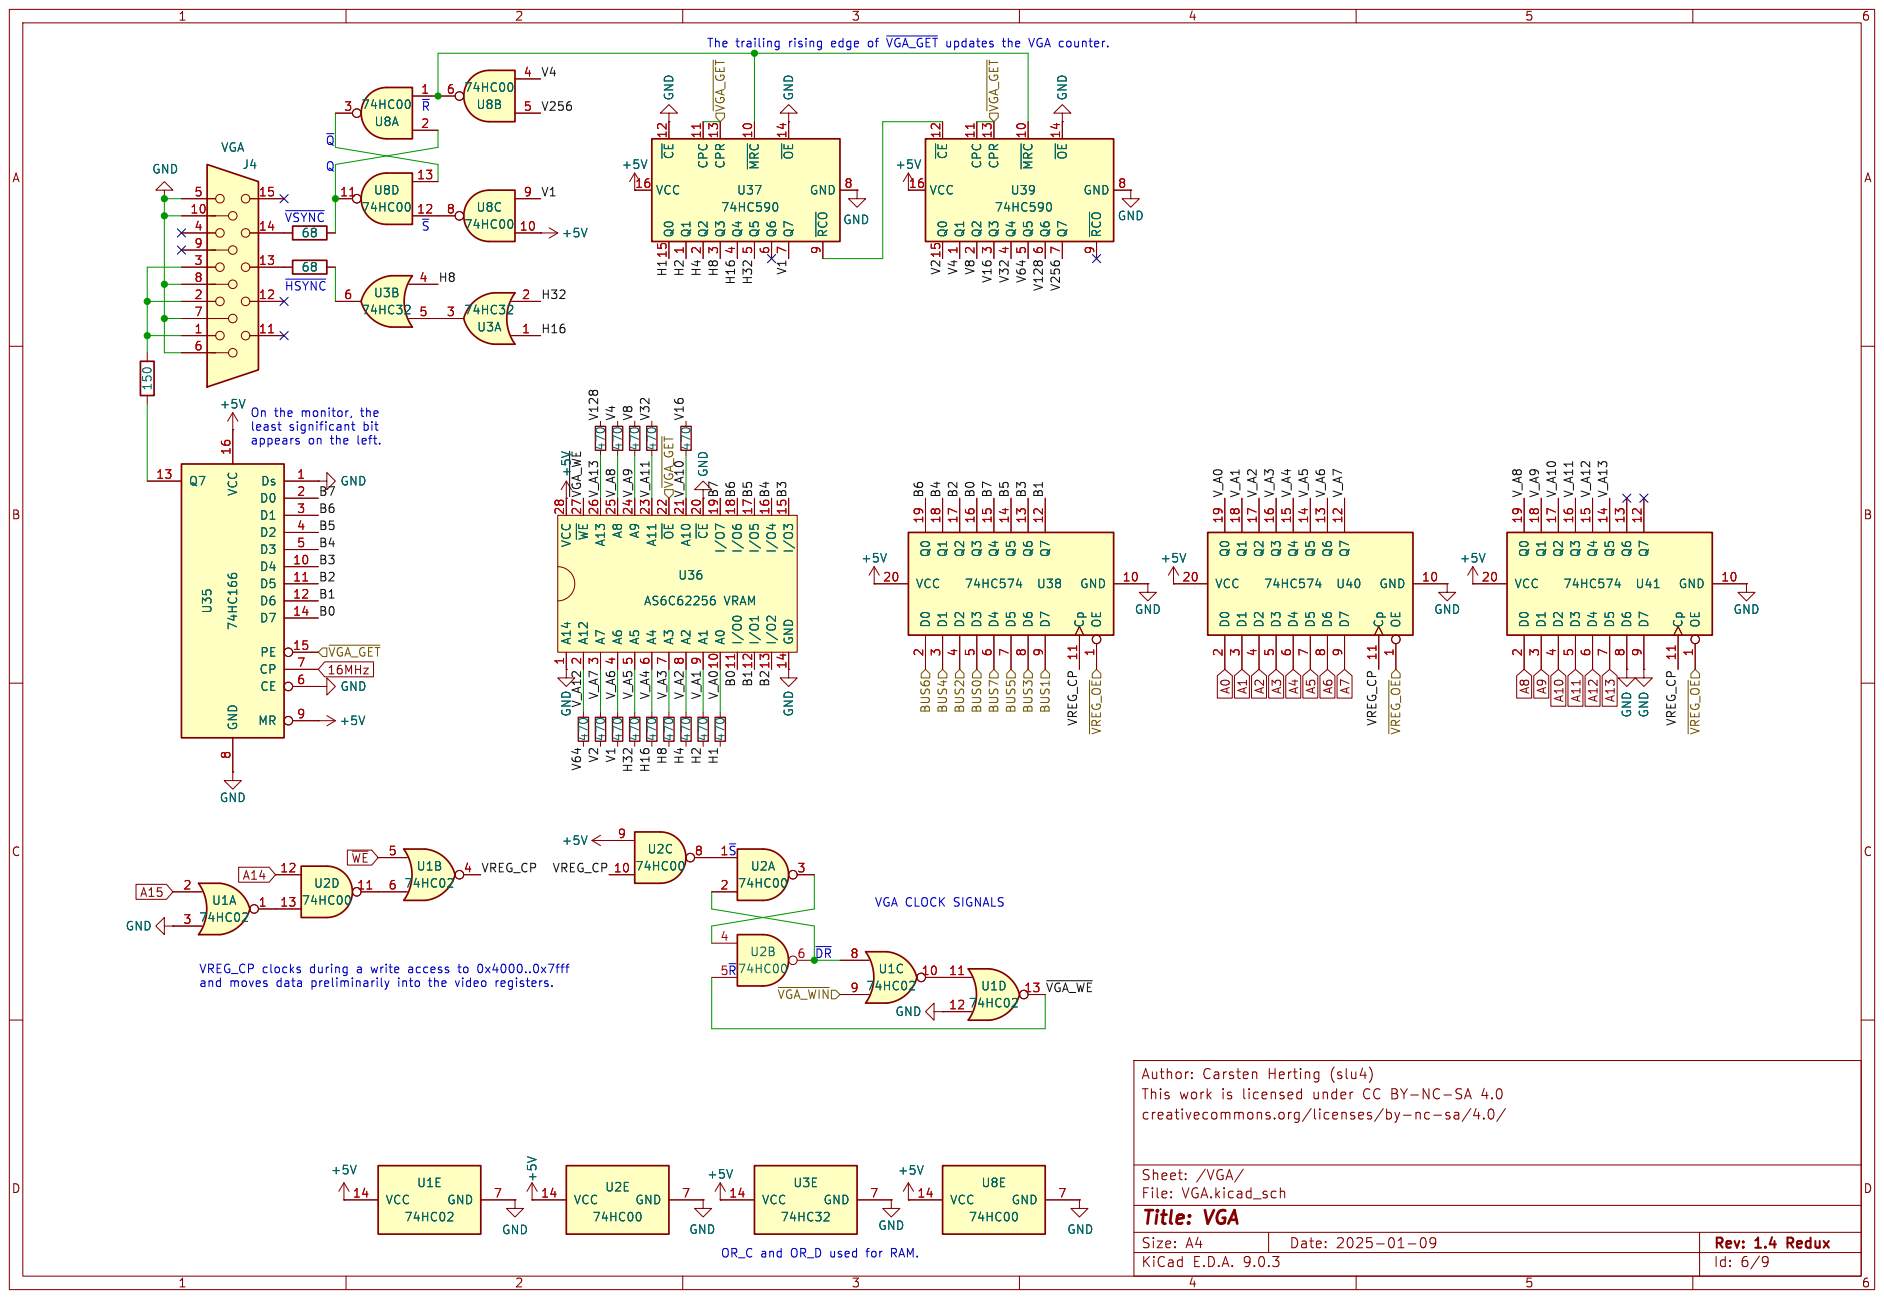
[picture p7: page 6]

1 VCC 20 GND 10 Q0 19 Q1 18 Q2 17 Q3 16 Q4 15 Q5 14 Q6 13 Q7 12 GND GND GND
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

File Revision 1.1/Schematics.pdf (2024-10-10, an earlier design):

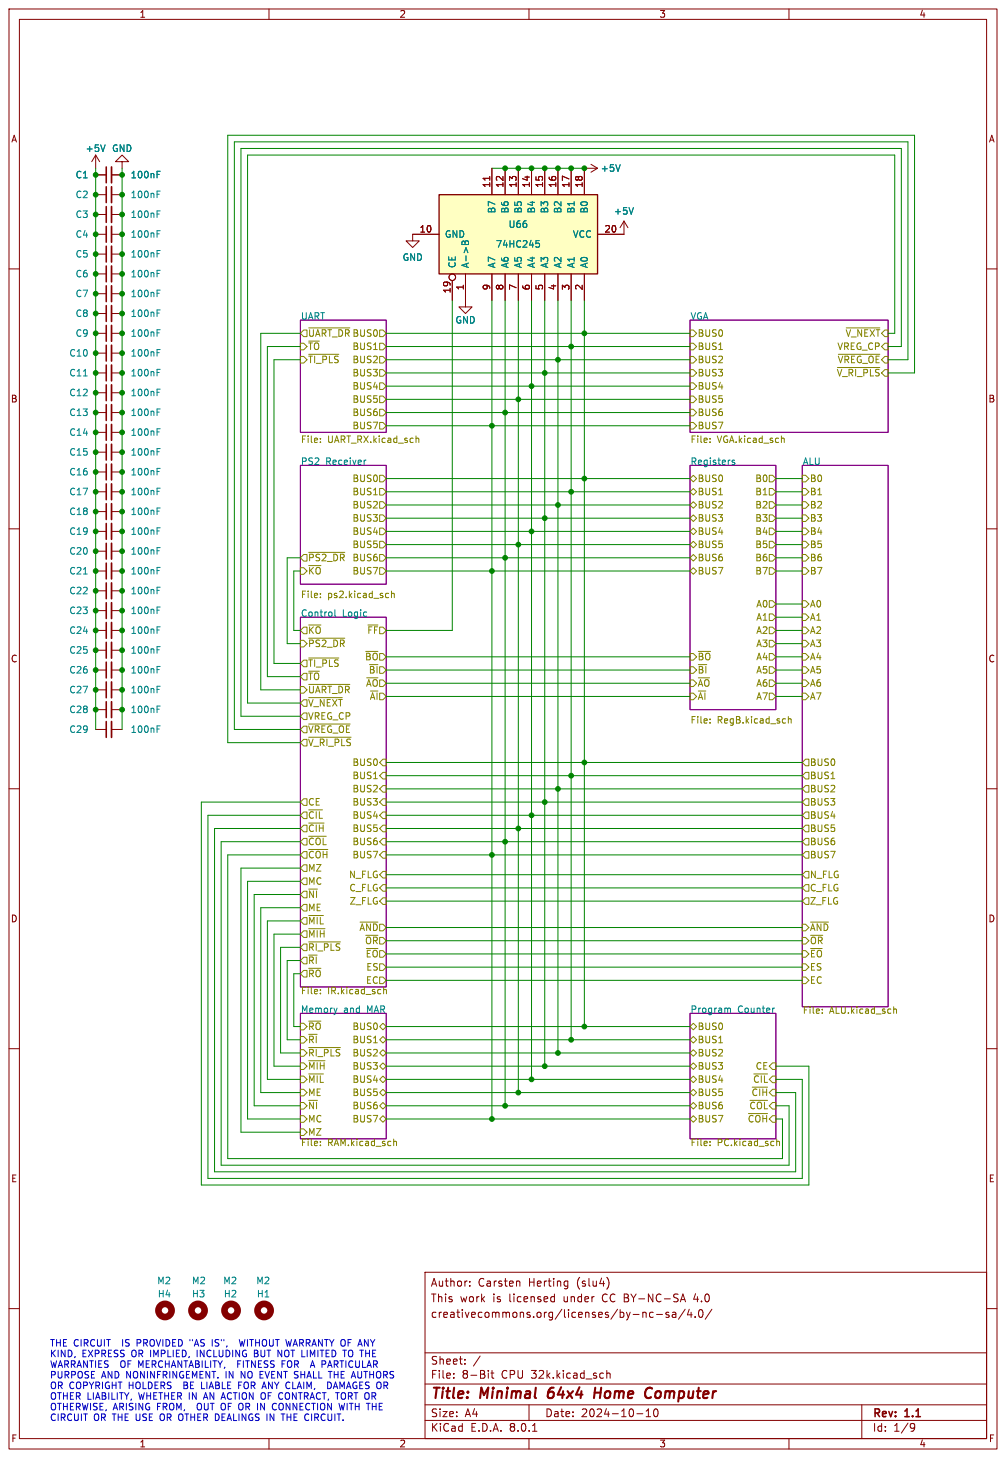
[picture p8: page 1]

~{RI} MCMZ Memory and MAR

~{COL} BUS3 BUS1 BUS0 BUS2 BUS4 BUS6 BUS7 BUS5 Program Counter File: PC.kicad_sch BUS0 BUS1 BUS2 BUS3 BUS4 BUS5 BUS6 BUS7 ~{RO} ME

KIND, EXPRESS OR IMPLIED, INCLUDING BUT NOT LIMITED TO THE WARRANTIES OF MERCHANTABILITY, FITNESS FOR A PARTICULAR

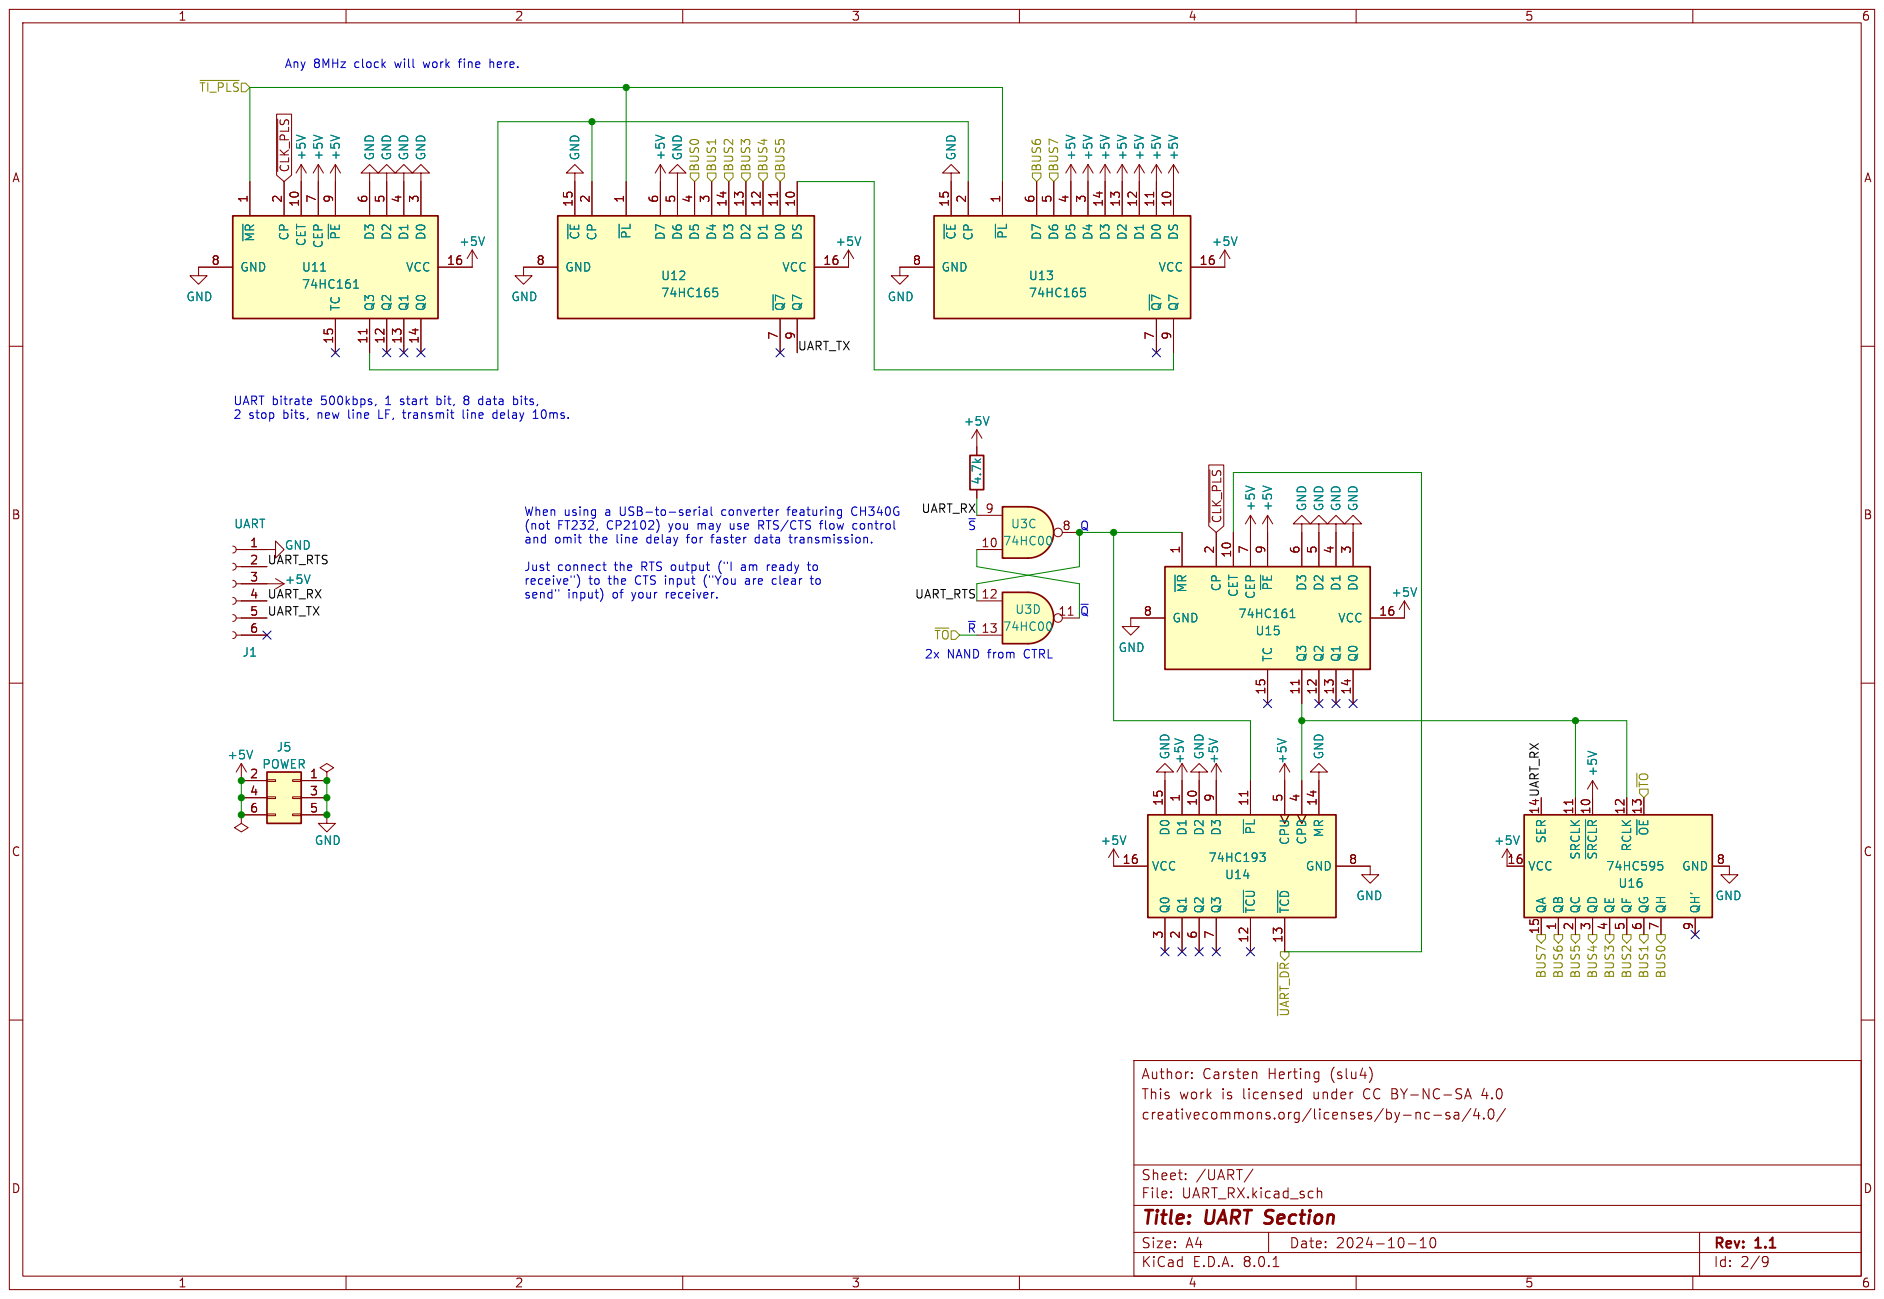
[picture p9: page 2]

7 GND 8 ~{PE} 9 +5V GND +5V GND

(not FT232, CP2102) you may use RTS/CTS flow control and omit the line delay for faster data transmission. Just connect the RTS output ("I am ready to

1 D2 10 ~{PL}11 ~{TCU} 12 ~{TCD} 13 MR 14 D0 15 VCC 16 Q1

1 ~{SRCLR} 10 SRCLK 11 RCLK 12 ~{OE} 13 SER 14 QA 15 VCC 16 QC

Id: 2/9 Title: UART Section

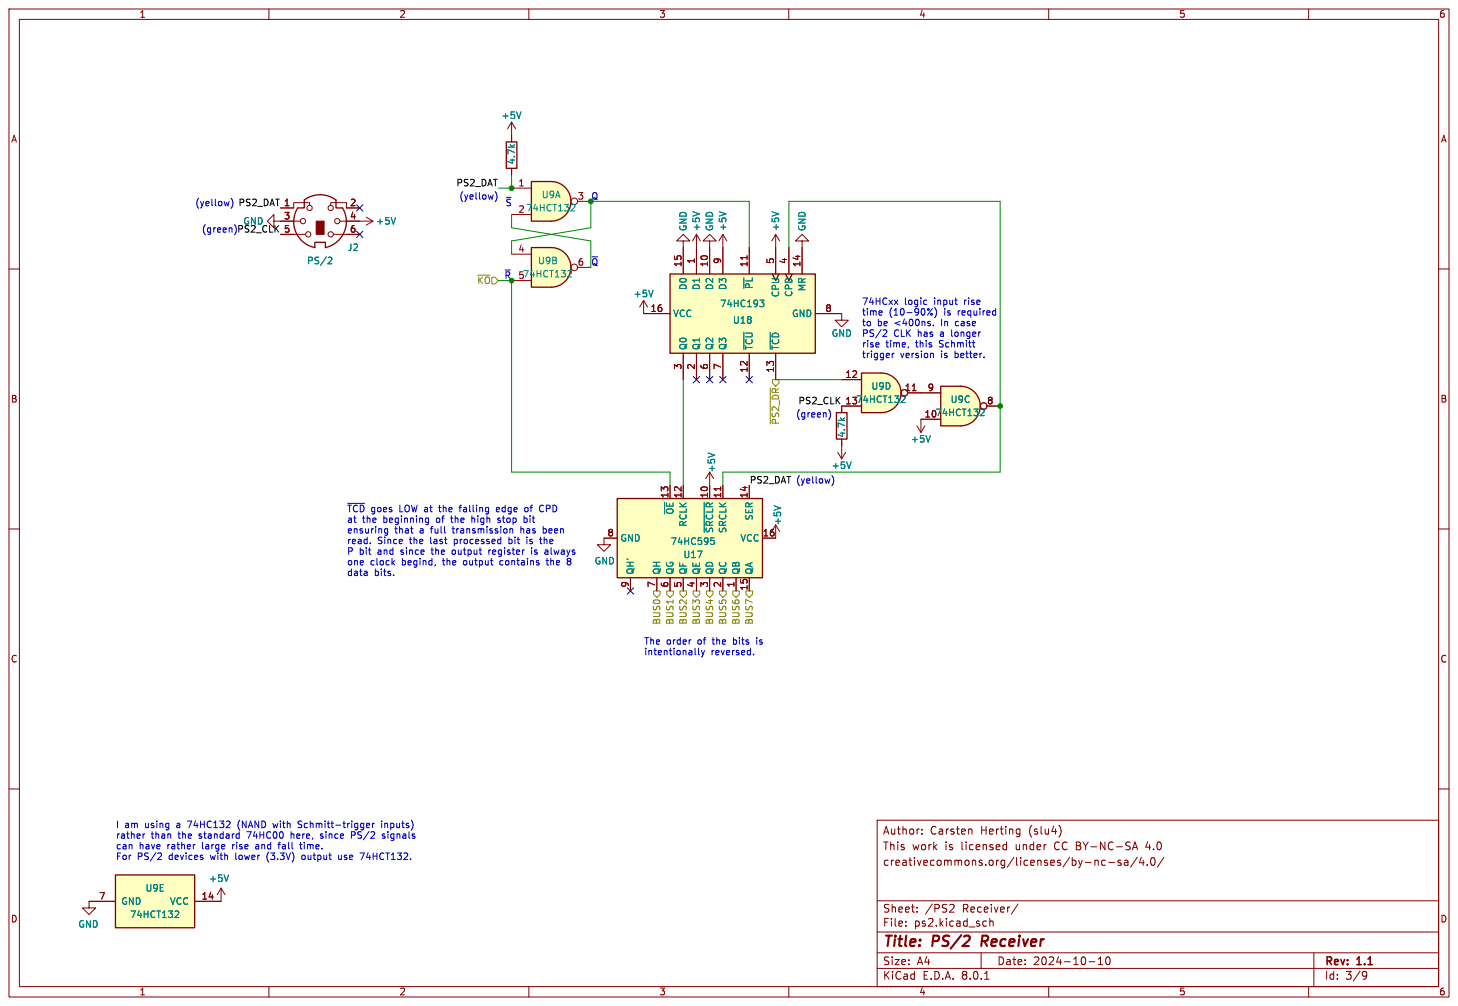
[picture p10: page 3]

1 D2 10 ~{PL}11 ~{TCU} 12 ~{TCD} 13 MR 14 D0 15 VCC 16 Q1

rise time, this Schmitt

trigger version is better. (green)

1 ~{SRCLR} 10 SRCLK 11 RCLK 12 ~{OE} 13 SER 14 QA 15 VCC 16 QC

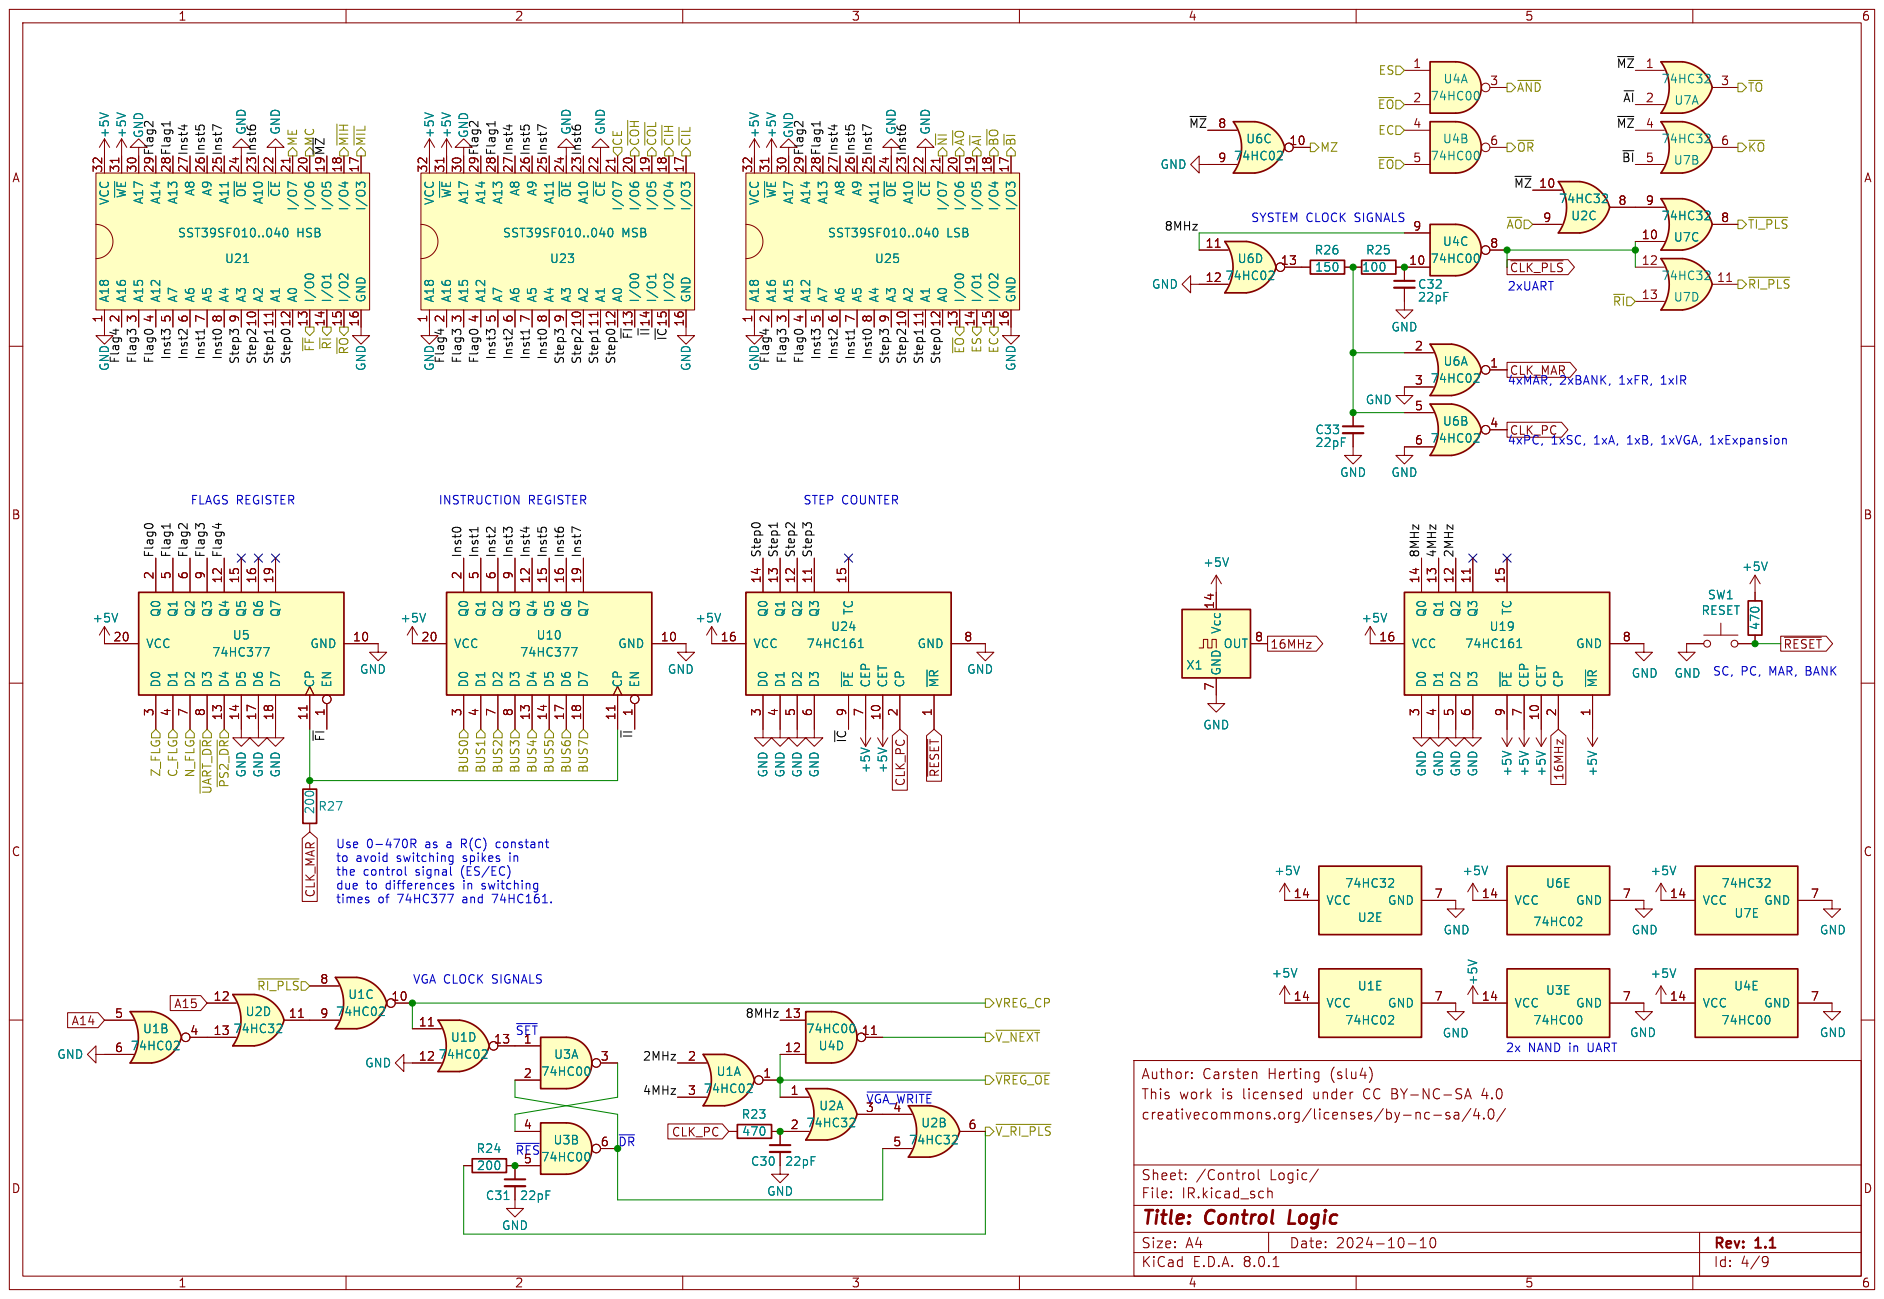
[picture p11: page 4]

9 U23 SST39SF010..040 MSB GND GND GND GND GND +5V +5V GND A18

9 GND GND GND GND GND +5V +5V GND

7 GND 8 ~{PE} 9 +5V +5V GND GND GND +5V +5V U25 SST39SF010..040 LSB A18

7 OUT 8 +5V GND GND GND

times of 74HC377 and 74HC161. ~{SET}

Id: 4/9 Title: Control Logic

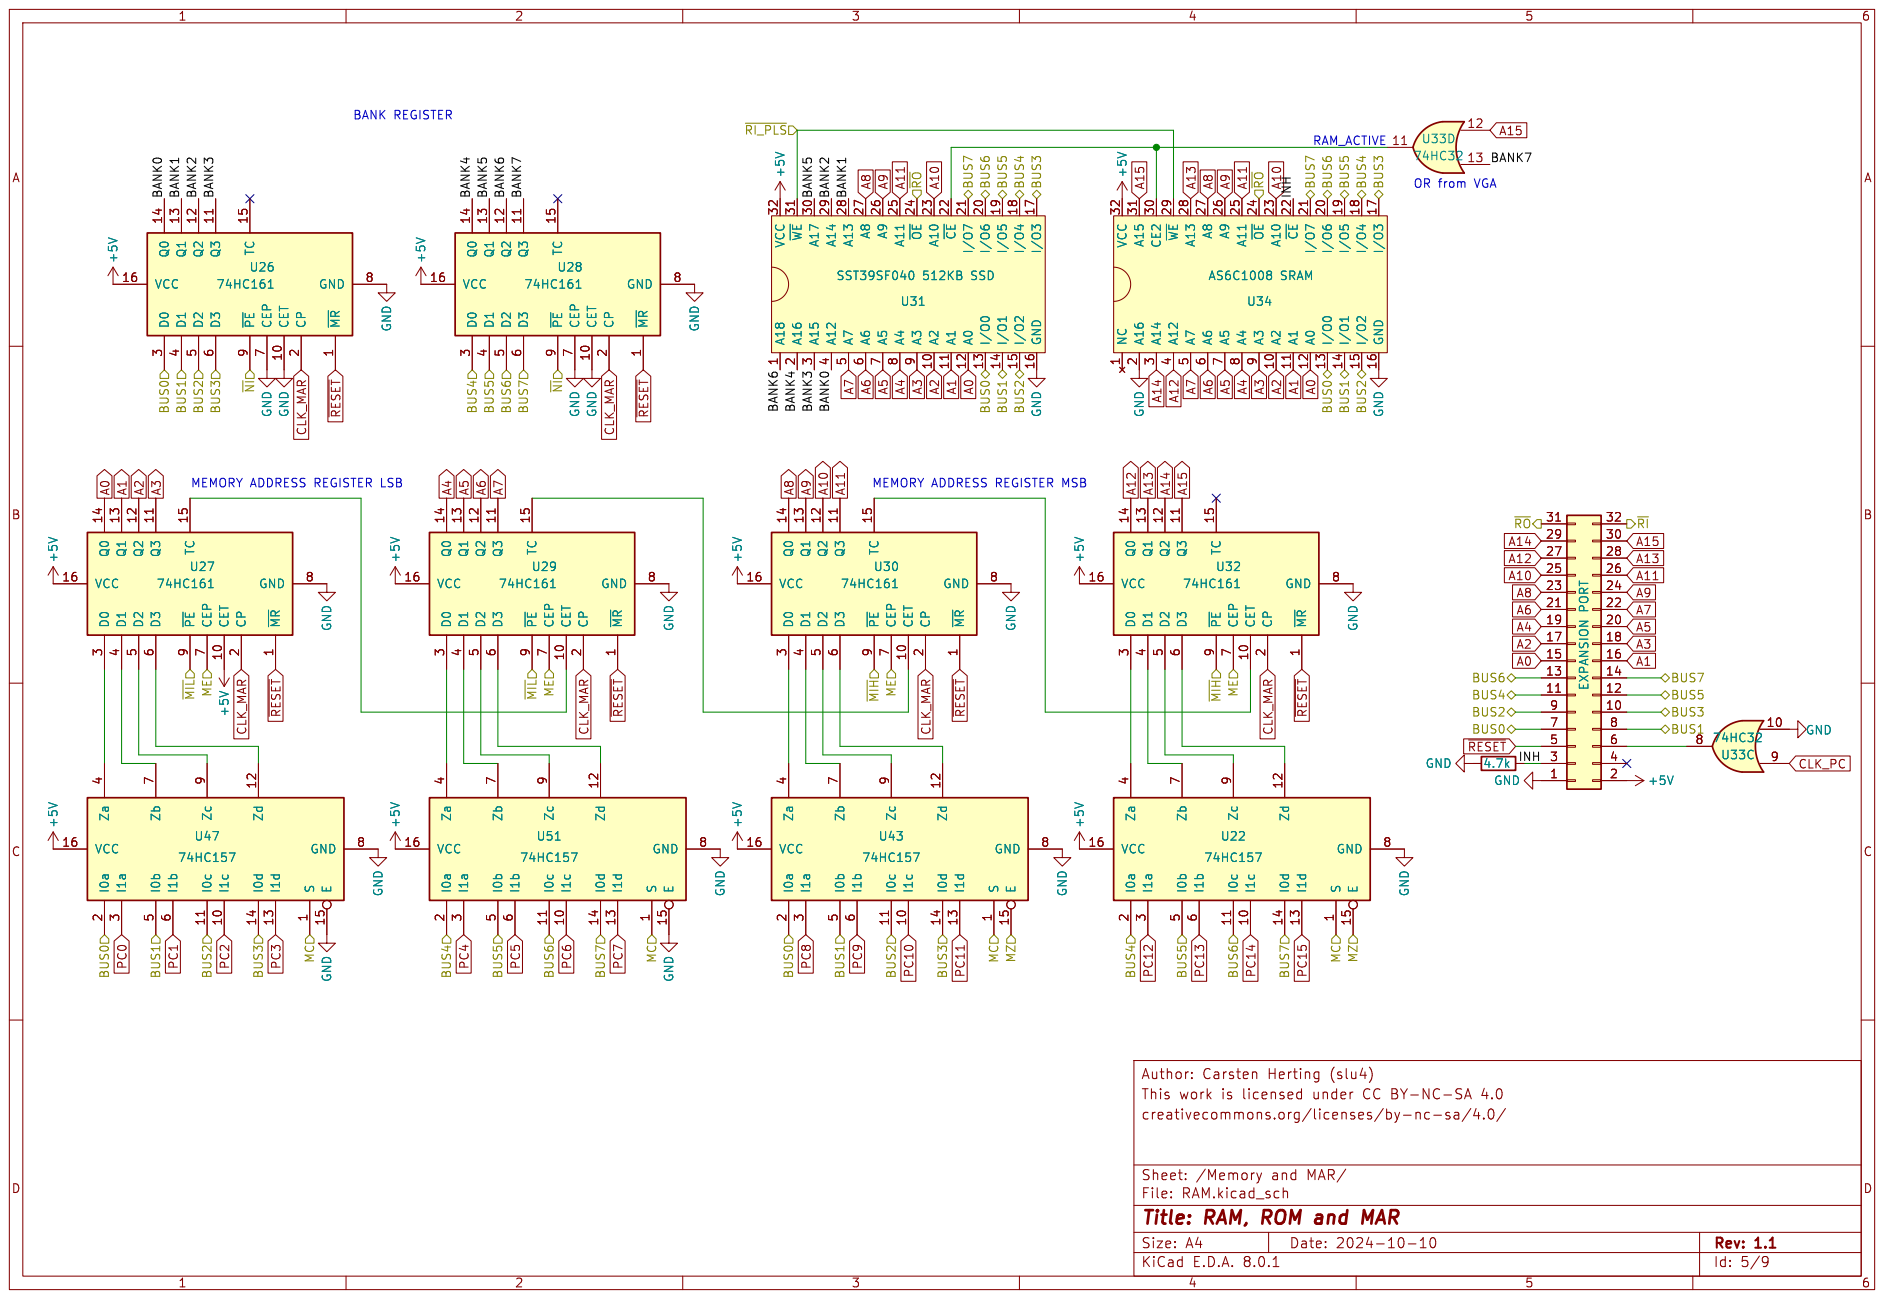
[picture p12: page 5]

7 GND 8 ~{PE} 9 +5V GND GND GND

7 GND 8 ~{PE} 9 GND GND GND

7 GND 8 Zc 9 GND GND +5V

7 GND 8 ~{PE} 9 GND +5V GND +5V U43

7 GND 8 ~{PE} 9 GND +5V GND

Id: 5/9 Title: RAM, ROM and MAR

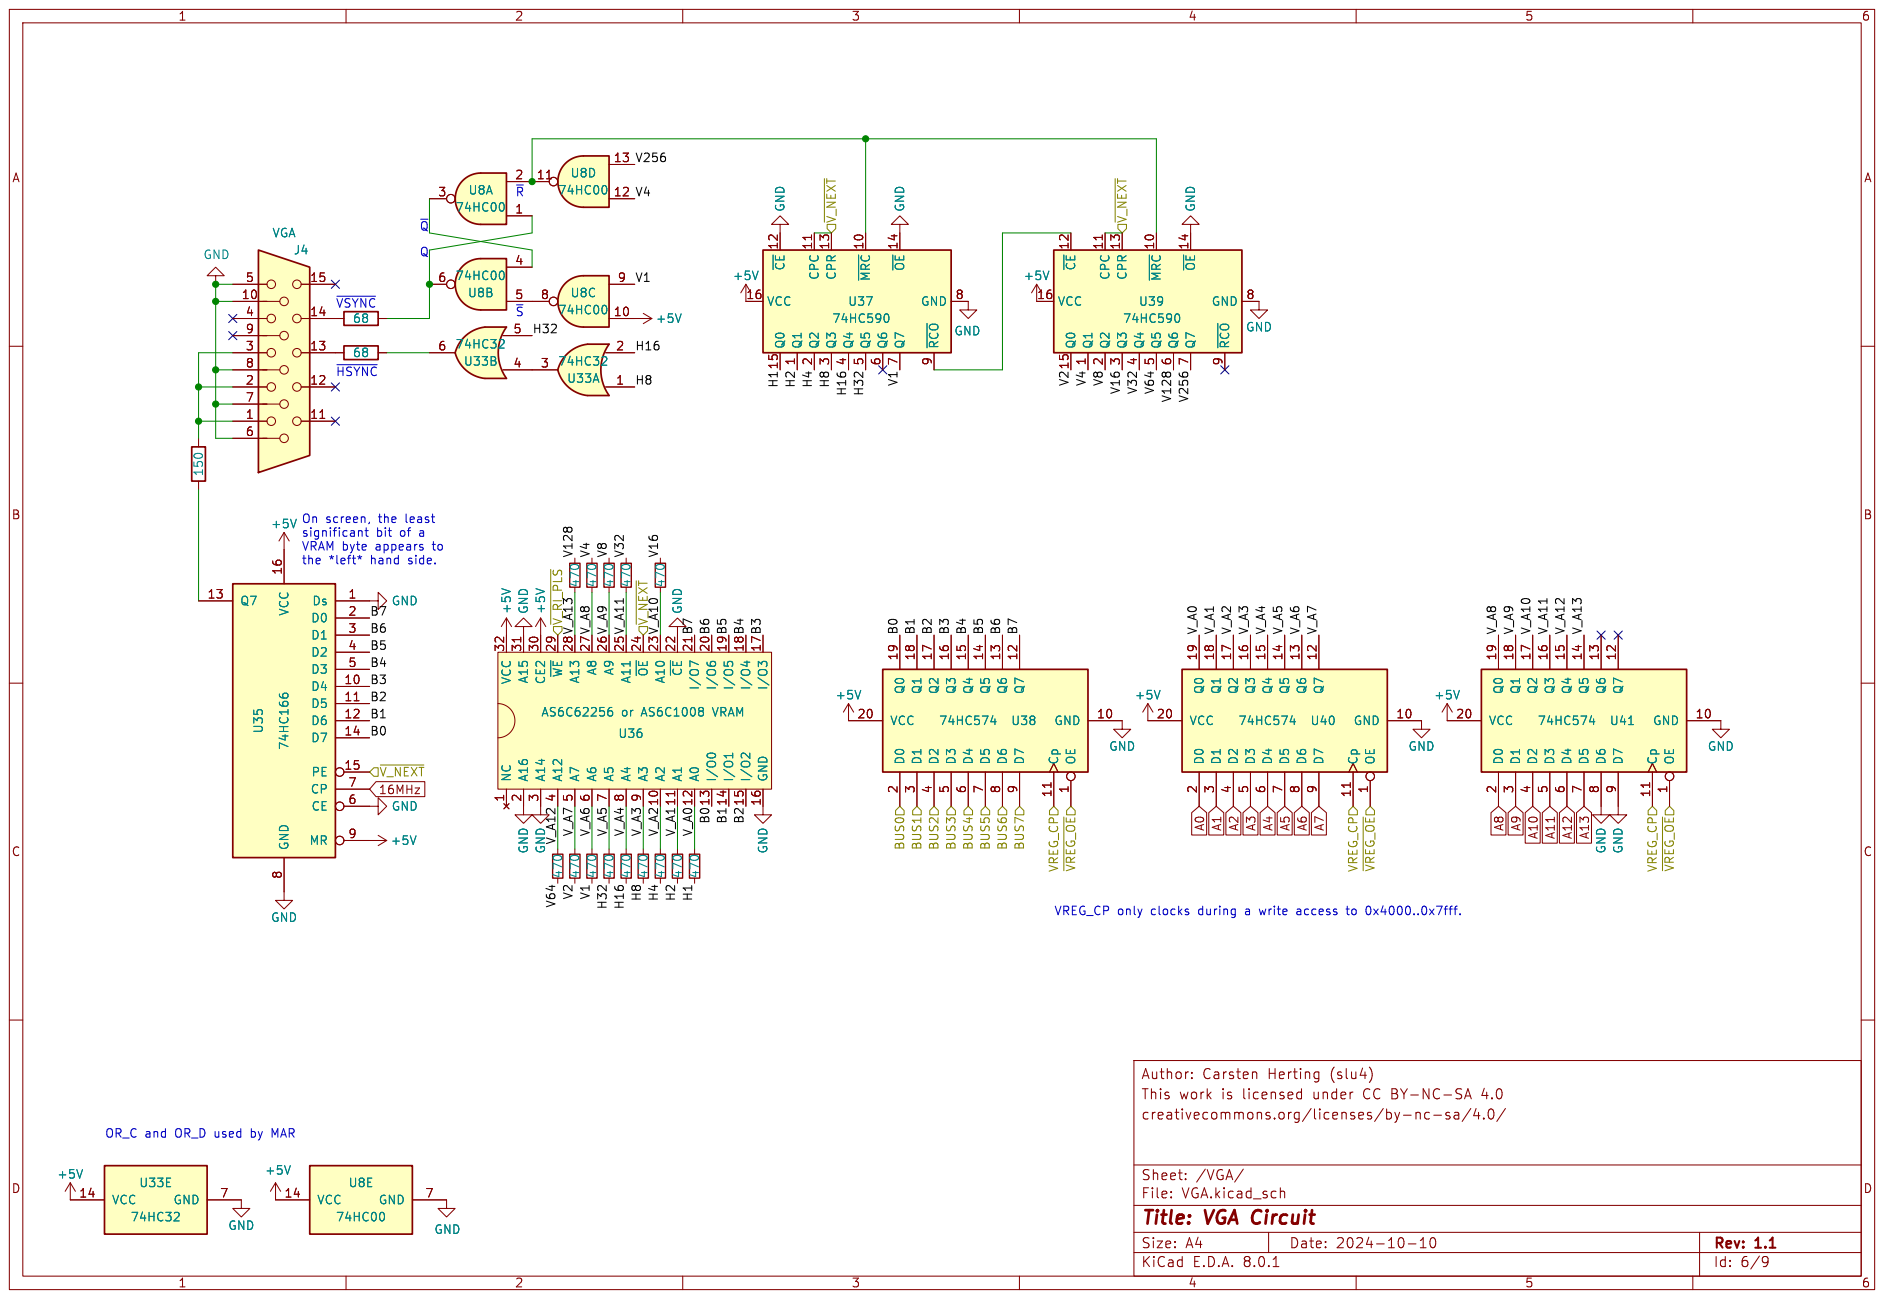
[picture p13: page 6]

7 GND 8 ~{RCO} 9 GND GND

1 ~{MRC} 10 CPC 11 ~{CE} 12 CPR 13 ~{OE} 14 Q0 15 VCC 16 Q2

9 GND GND +5V GND +5V GND GND GND


File: RegB.kicad_sch Sheet: /Registers/
Id: 7/9 Title: Registers A & B



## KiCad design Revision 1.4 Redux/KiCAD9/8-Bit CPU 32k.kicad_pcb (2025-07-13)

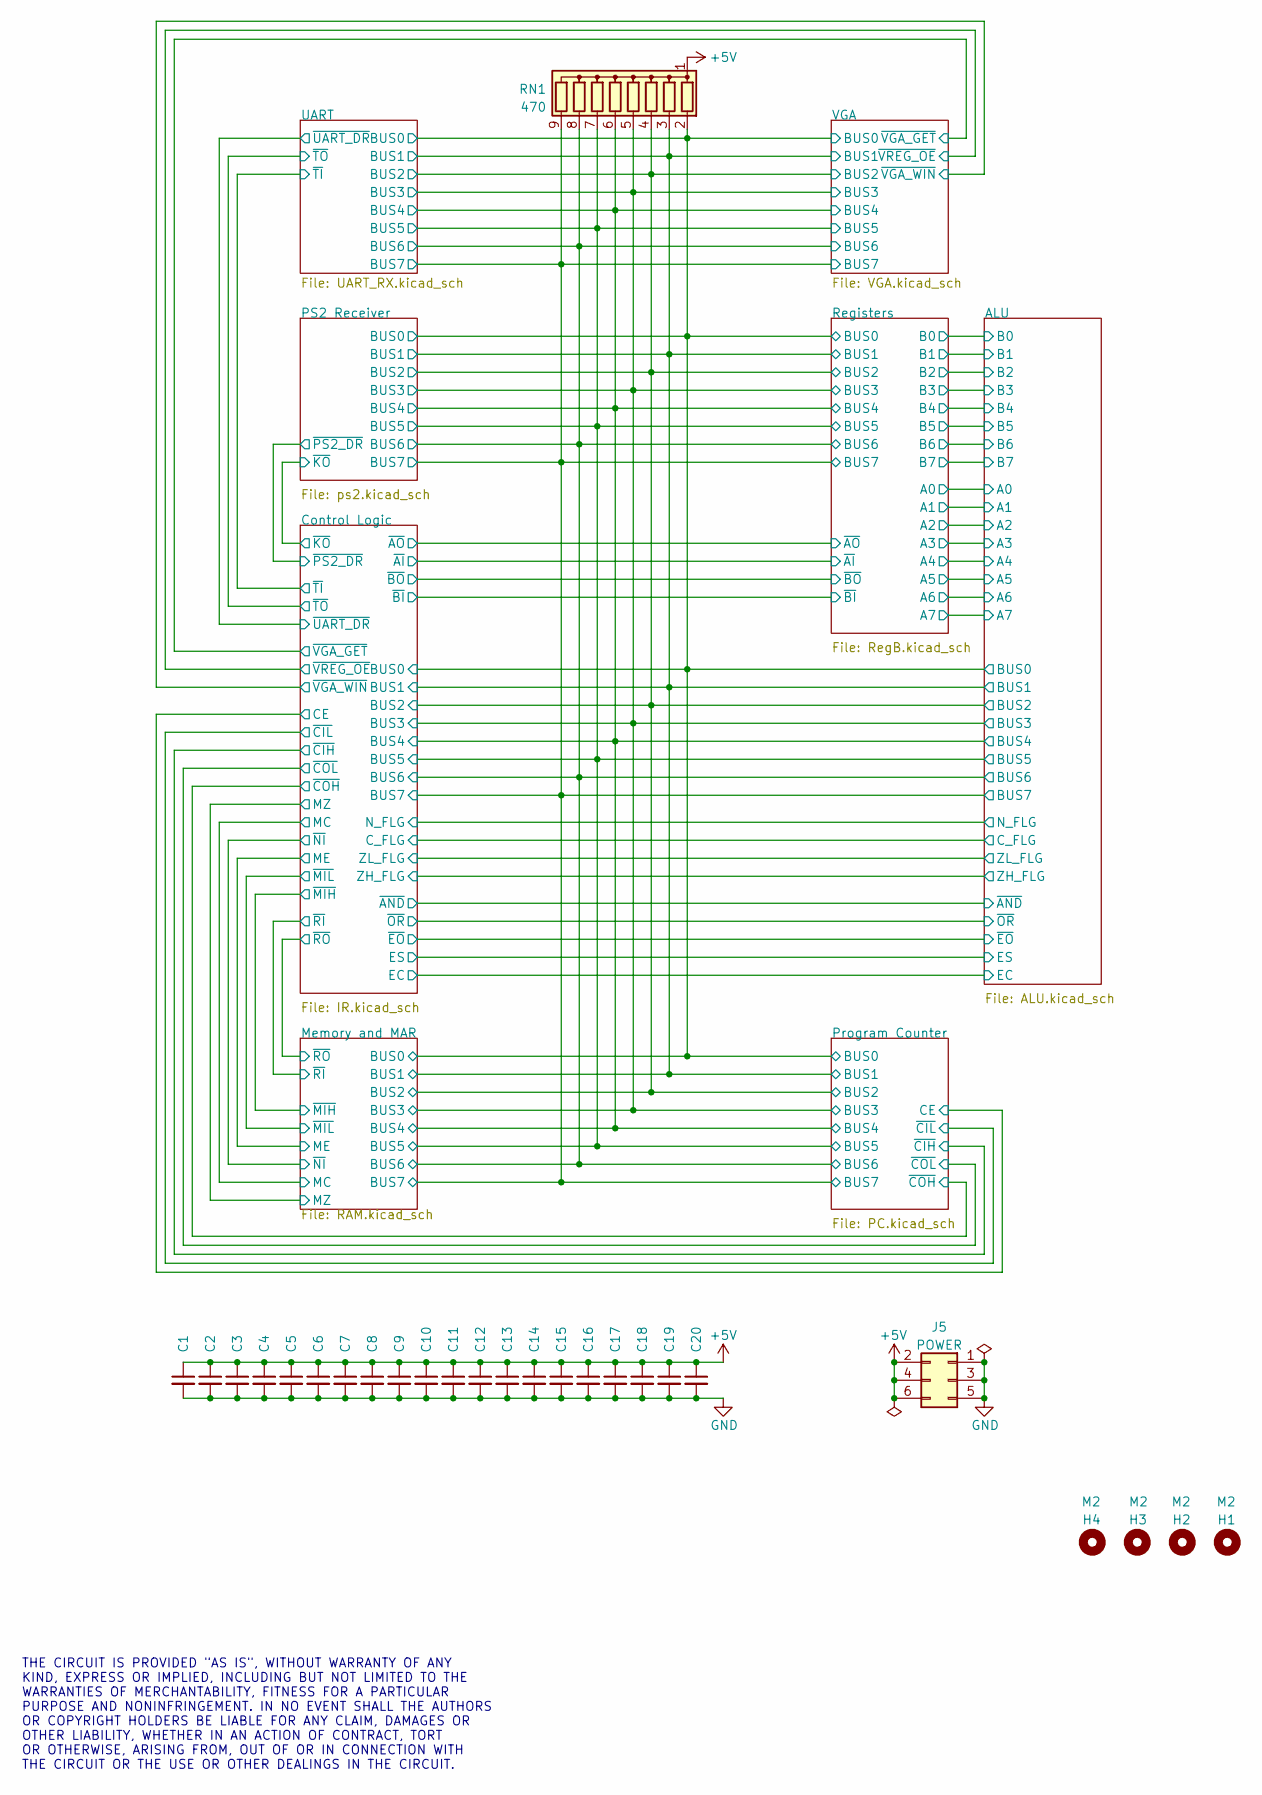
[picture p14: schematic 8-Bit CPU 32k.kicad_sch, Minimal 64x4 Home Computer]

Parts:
C1, C2, C3, C4, C5, C6, C7, C8, C9, C10, C11, C12, C13, C14, C15, C16, C17, C18, C19, C20: 100nF; C_Disc_D3.4mm_W2.1mm_P2.50mm
H1, H2, H3, H4: M2; MountingHole_2.2mm_M2
J5: POWER; PinSocket_2x03_P2.54mm_Vertical
RN1: 470; R_Array_SIP9

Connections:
+5V: C1.1, C2.1, C3.1, C4.1, C5.1, C6.1, C7.1, C8.1, C9.1, C10.1, C11.1, C12.1, C13.1, C14.1, C15.1, C16.1, C17.1, C18.1, C19.1, C20.1, J5.2, J5.4, J5.6, RN1.1 (common); also elsewhere on the board
/ALU/BUS0: RN1.2 (R1); also elsewhere on the board
/ALU/BUS1: RN1.3 (R2); also elsewhere on the board
/ALU/BUS2: RN1.4 (R3); also elsewhere on the board
/ALU/BUS3: RN1.5 (R4); also elsewhere on the board
/ALU/BUS4: RN1.6 (R5); also elsewhere on the board
/ALU/BUS5: RN1.7 (R6); also elsewhere on the board
/ALU/BUS6: RN1.8 (R7); also elsewhere on the board
/ALU/BUS7: RN1.9 (R8); also elsewhere on the board
GND: C1.2, C2.2, C3.2, C4.2, C5.2, C6.2, C7.2, C8.2, C9.2, C10.2, C11.2, C12.2, C13.2, C14.2, C15.2, C16.2, C17.2, C18.2, C19.2, C20.2, J5.1, J5.3, J5.5; also elsewhere on the board

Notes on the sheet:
THE CIRCUIT IS PROVIDED "AS IS", WITHOUT WARRANTY OF ANY KIND, EXPRESS OR IMPLIED, INCLUDING BUT NOT LIMITED TO THE WARRANTIES OF MERCHANTABILITY, FITNESS FOR A PARTICULAR PURPOSE AND NONINFRINGEMENT. IN NO EVENT SHALL THE AUTHORS OR COPYRIGHT HOLDERS BE LIABLE FOR ANY CLAIM, DAMAGES OR OTHER LIABI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

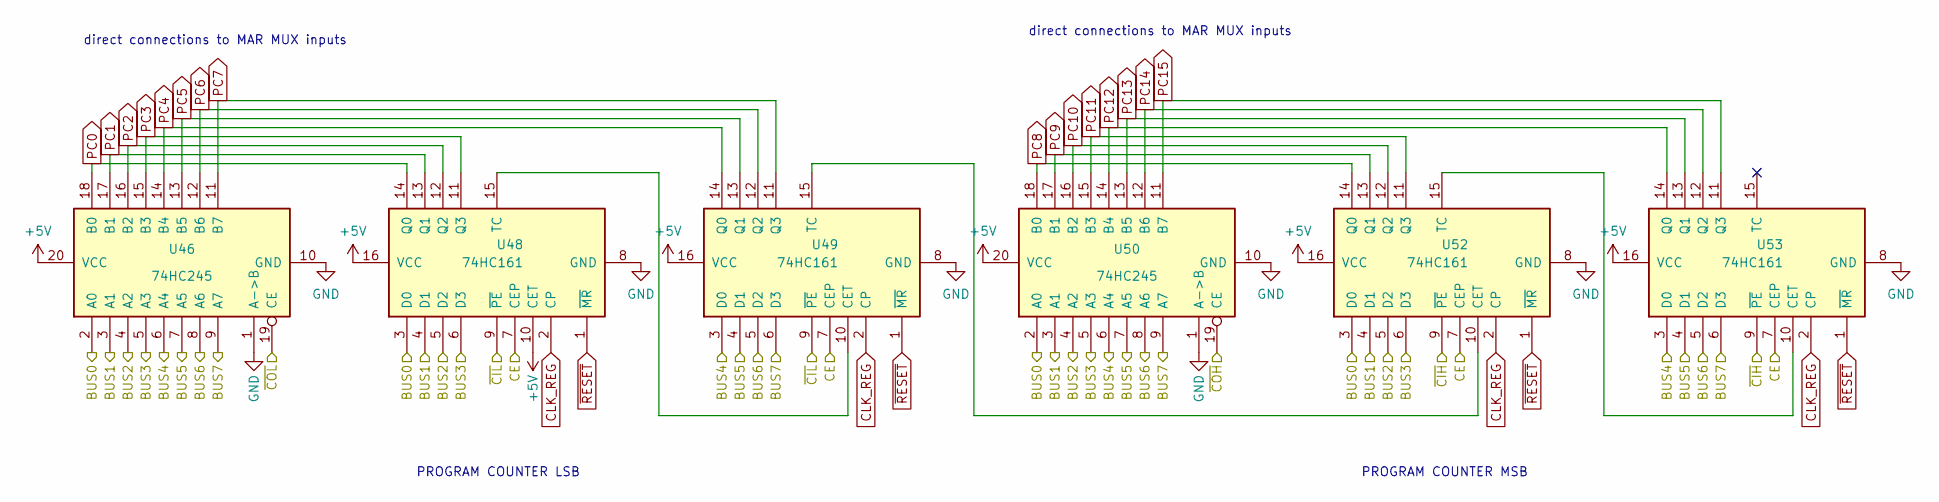
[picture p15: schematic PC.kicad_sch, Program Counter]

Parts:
U46, U50: 74HC245; DIP-20_W7.62mm_Socket
U48, U49, U52, U53: 74HC161; DIP-16_W7.62mm_Socket

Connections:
+5V: U46.20 (VCC), U48.10 (CET), U48.16 (VCC), U49.16 (VCC), U50.20 (VCC), U52.16 (VCC), U53.16 (VCC); also elsewhere on the board
/ALU/BUS0: U46.2 (A0), U48.3 (D0), U50.2 (A0), U52.3 (D0); also elsewhere on the board
/ALU/BUS1: U46.3 (A1), U48.4 (D1), U50.3 (A1), U52.4 (D1); also elsewhere on the board
/ALU/BUS2: U46.4 (A2), U48.5 (D2), U50.4 (A2), U52.5 (D2); also elsewhere on the board
/ALU/BUS3: U46.5 (A3), U48.6 (D3), U50.5 (A3), U52.6 (D3); also elsewhere on the board
/ALU/BUS4: U46.6 (A4), U49.3 (D0), U50.6 (A4), U53.3 (D0); also elsewhere on the board
/ALU/BUS5: U46.7 (A5), U49.4 (D1), U50.7 (A5), U53.4 (D1); also elsewhere on the board
/ALU/BUS6: U46.8 (A6), U49.5 (D2), U50.8 (A6), U53.5 (D2); also elsewhere on the board
/ALU/BUS7: U46.9 (A7), U49.6 (D3), U50.9 (A7), U53.6 (D3); also elsewhere on the board
/Control Logic/CE: U48.7 (CEP), U49.7 (CEP), U52.7 (CEP), U53.7 (CEP); also elsewhere on the board
/Control Logic/~CIH: U52.9 (~PE), U53.9 (~PE); also elsewhere on the board
/Control Logic/~CIL: U48.9 (~PE), U49.9 (~PE); also elsewhere on the board
/Control Logic/~COH: U50.19 (CE); also elsewhere on the board
/Control Logic/~COL: U46.19 (CE); also elsewhere on the board
CLK_REG: U48.2 (CP), U49.2 (CP), U52.2 (CP), U53.2 (CP); also elsewhere on the board
GND: U46.1 (A->B), U46.10 (GND), U48.8 (GND), U49.8 (GND), U50.1 (A->B), U50.10 (GND), U52.8 (GND), U53.8 (GND); also elsewhere on the board
unnamed: U48.15 (TC), U49.10 (CET)
unnamed: U49.15 (TC), U52.10 (CET)
unnamed: U52.15 (TC), U53.10 (CET)
PC0: U46.18 (B0), U48.14 (Q0); also elsewhere on the board
PC1: U46.17 (B1), U48.13 (Q1); also elsewhere on the board
PC2: U46.16 (B2), U48.12 (Q2); also elsewhere on the board
PC3: U46.15 (B3), U48.11 (Q3); also elsewhere on the board
PC4: U46.14 (B4), U49.14 (Q0); also elsewhere on the board
PC5: U46.13 (B5), U49.13 (Q1); also elsewhere on the board
PC6: U46.12 (B6), U49.12 (Q2); also elsewhere on the board
PC7: U46.11 (B7), U49.11 (Q3); also elsewhere on the board
PC8: U50.18 (B0), U52.14 (Q0); also elsewhere on the board
PC9: U50.17 (B1), U52.13 (Q1); also elsewhere on the board
PC10: U50.16 (B2), U52.12 (Q2); also elsewhere on the board
PC11: U50.15 (B3), U52.11 (Q3); also elsewhere on the board
PC12: U50.14 (B4), U53.14 (Q0); also elsewhere on the board
PC13: U50.13 (B5), U53.13 (Q1); also elsewhere on the board
PC14: U50.12 (B6), U53.12 (Q2); also elsewhere on the board
PC15: U50.11 (B7), U53.11 (Q3); also elsewhere on the board
~RESET: U48.1 (~MR), U49.1 (~MR), U52.1 (~MR), U53.1 (~MR); also elsewhere on the board

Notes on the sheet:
PROGRAM COUNTER MSB
PROGRAM COUNTER LSB
direct connections to MAR MUX inputs

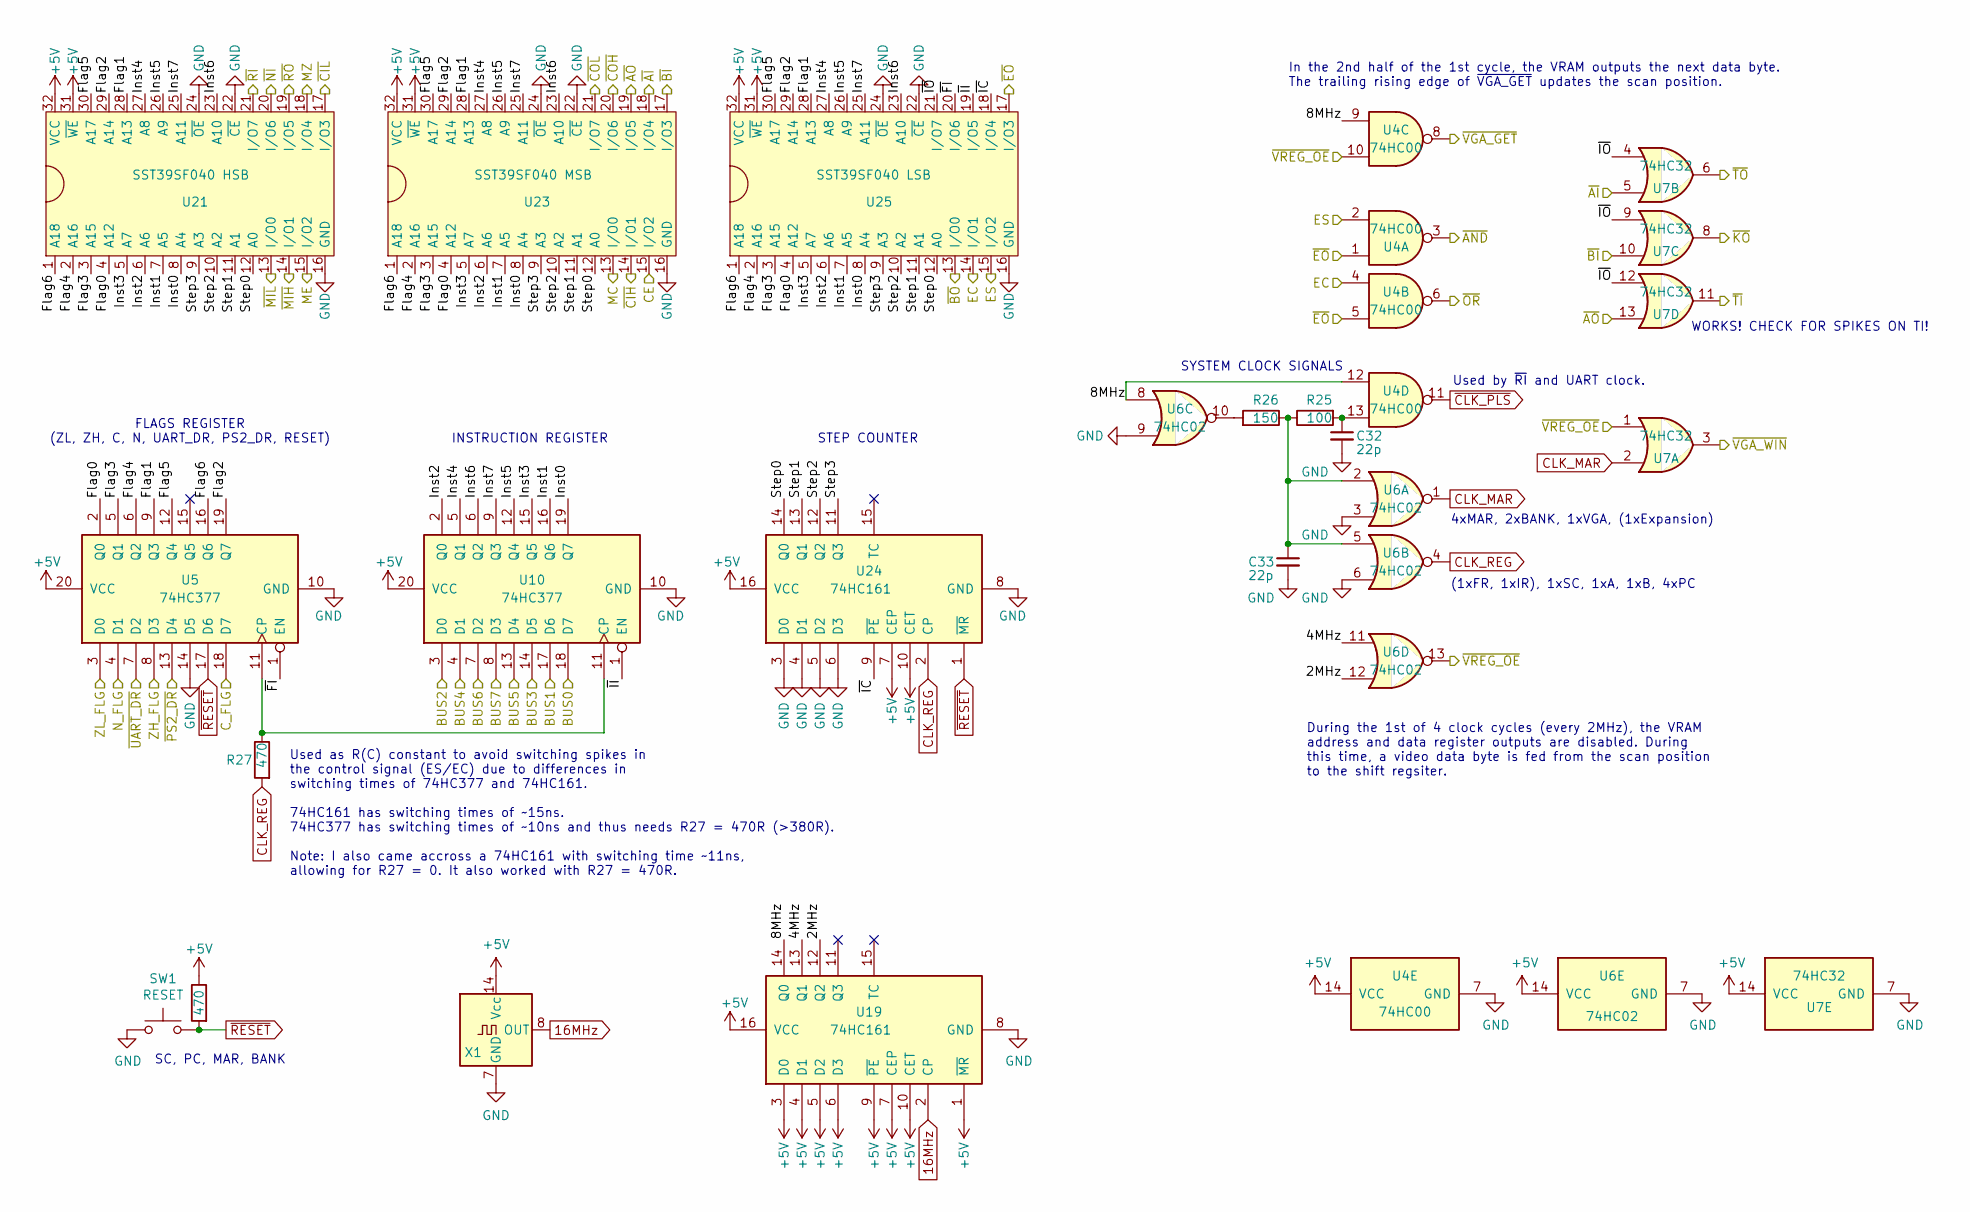
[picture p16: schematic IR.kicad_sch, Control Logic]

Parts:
C32, C33: 22p; C_Disc_D3.4mm_W2.1mm_P2.50mm
R2, R27: 470; R_Axial_DIN0207_L6.3mm_D2.5mm_P7.62mm_Horizontal
R25: 100; R_Axial_DIN0207_L6.3mm_D2.5mm_P7.62mm_Horizontal
R26: 150; R_Axial_DIN0207_L6.3mm_D2.5mm_P7.62mm_Horizontal
SW1: RESET; SW_PUSH_6mm
U4: 74HC00; DIP-14_W7.62mm_Socket
U5, U10: 74HC377; DIP-20_W7.62mm_Socket
U6: 74HC02; DIP-14_W7.62mm_Socket
U7: 74HC32; DIP-14_W7.62mm_Socket
U19, U24: 74HC161; DIP-16_W7.62mm_Socket
U21: SST39SF040 HSB; DIP-32_W15.24mm_Socket
U23: SST39SF040 MSB; DIP-32_W15.24mm_Socket
U25: SST39SF040 LSB; DIP-32_W15.24mm_Socket
X1: 16MHz; Oscillator_DIP-14

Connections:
16MHz: U19.2 (CP), X1.8 (OUT); also elsewhere on the board
+5V: R2.1, U4.14 (VCC), U5.20 (VCC), U6.14 (VCC), U7.14 (VCC), U10.20 (VCC), U19.1 (~MR), U19.3 (D0), U19.4 (D1), U19.5 (D2), U19.6 (D3), U19.7 (CEP), U19.9 (~PE), U19.10 (CET), U19.16 (VCC), U21.31 (~WE), U21.32 (VCC), U23.31 (~WE), U23.32 (VCC), U24.7 (CEP), U24.10 (CET), U24.16 (VCC), U25.31 (~WE), U25.32 (VCC), X1.14 (Vcc); also elsewhere on the board
/ALU/BUS0: U10.18 (D7); also elsewhere on the board
/ALU/BUS1: U10.17 (D6); also elsewhere on the board
/ALU/BUS2: U10.3 (D0); also elsewhere on the board
/ALU/BUS3: U10.14 (D5); also elsewhere on the board
/ALU/BUS4: U10.4 (D1); also elsewhere on the board
/ALU/BUS5: U10.13 (D4); also elsewhere on the board
/ALU/BUS6: U10.7 (D2); also elsewhere on the board
/ALU/BUS7: U10.8 (D3); also elsewhere on the board
/ALU/C_FLG: U5.18 (D7); also elsewhere on the board
/ALU/EC: U4.4, U25.14 (I/O1); also elsewhere on the board
/ALU/ES: U4.2, U25.15 (I/O2); also elsewhere on the board
/ALU/N_FLG: U5.4 (D1); also elsewhere on the board
/ALU/ZH_FLG: U5.8 (D3); also elsewhere on the board
/ALU/ZL_FLG: U5.3 (D0); also elsewhere on the board
/ALU/~AND: U4.3; also elsewhere on the board
/ALU/~EO: U4.1, U4.5, U25.17 (I/O3); also elsewhere on the board
/ALU/~OR: U4.6; also elsewhere on the board
/Control Logic/2MHz: U6.12, U19.12 (Q2)
/Control Logic/4MHz: U6.11, U19.13 (Q1)
/Control Logic/8MHz: U4.9, U4.12, U6.8, U19.14 (Q0)
/Control Logic/CE: U23.15 (I/O2); also elsewhere on the board
/Control Logic/Flag0: U5.2 (Q0), U21.4 (A12), U23.4 (A12), U25.4 (A12)
/Control Logic/Flag1: U5.9 (Q3), U21.28 (A13), U23.28 (A13), U25.28 (A13)
/Control Logic/Flag2: U5.19 (Q7), U21.29 (A14), U23.29 (A14), U25.29 (A14)
/Control Logic/Flag3: U5.5 (Q1), U21.3 (A15), U23.3 (A15), U25.3 (A15)
/Control Logic/Flag4: U5.6 (Q2), U21.2 (A16), U23.2 (A16), U25.2 (A16)
/Control Logic/Flag5: U5.12 (Q4), U21.30 (A17), U23.30 (A17), U25.30 (A17)
/Control Logic/Flag6: U5.16 (Q6), U21.1 (A18), U23.1 (A18), U25.1 (A18)
/Control Logic/Inst0: U10.19 (Q7), U21.8 (A4), U23.8 (A4), U25.8 (A4)
/Control Logic/Inst1: U10.16 (Q6), U21.7 (A5), U23.7 (A5), U25.7 (A5)
/Control Logic/Inst2: U10.2 (Q0), U21.6 (A6), U23.6 (A6), U25.6 (A6)
/Control Logic/Inst3: U10.15 (Q5), U21.5 (A7), U23.5 (A7), U25.5 (A7)
/Control Logic/Inst4: U10.5 (Q1), U21.27 (A8), U23.27 (A8), U25.27 (A8)
/Control Logic/Inst5: U10.12 (Q4), U21.26 (A9), U23.26 (A9), U25.26 (A9)
/Control Logic/Inst6: U10.6 (Q2), U21.23 (A10), U23.23 (A10), U25.23 (A10)
/Control Logic/Inst7: U10.9 (Q3), U21.25 (A11), U23.25 (A11), U25.25 (A11)
/Control Logic/MC: U23.13 (I/O0); also elsewhere on the board
/Control Logic/ME: U21.15 (I/O2); also elsewhere on the board
/Control Logic/MZ: U21.18 (I/O4); also elsewhere on the board
/Control Logic/Step0: U21.12 (A0), U23.12 (A0), U24.14 (Q0), U25.12 (A0)
/Control Logic/Step1: U21.11 (A1), U23.11 (A1), U24.13 (Q1), U25.11 (A1)
/Control Logic/Step2: U21.10 (A2), U23.10 (A2), U24.12 (Q2), U25.10 (A2)
/Control Logic/Step3: U21.9 (A3), U23.9 (A3), U24.11 (Q3), U25.9 (A3)
/Control Logic/~AI: U7.5, U23.18 (I/O4); also elsewhere on the board
/Control Logic/~AO: U7.13, U23.19 (I/O5); also elsewhere on the board
/Control Logic/~BI: U7.10, U23.17 (I/O3); also elsewhere on the board
/Control Logic/~BO: U25.13 (I/O0); also elsewhere on the board
/Control Logic/~CIH: U23.14 (I/O1); also elsewhere on the board
/Control Logic/~CIL: U21.17 (I/O3); also elsewhere on the board
/Control Logic/~COH: U23.20 (I/O6); also elsewhere on the board
/Control Logic/~COL: U23.21 (I/O7); also elsewhere on the board
/Control Logic/~FI: U5.1 (EN), U25.20 (I/O6)
/Control Logic/~IC: U24.9 (~PE), U25.18 (I/O4)
/Control Logic/~II: U10.1 (EN), U25.19 (I/O5)
/Control Logic/~IO: U7.4, U7.9, U7.12, U25.21 (I/O7)
/Control Logic/~KO: U7.8; also elsewhere on the board
/Control Logic/~MIH: U21.14 (I/O1); also elsewhere on the board
/Control Logic/~MIL: U21.13 (I/O0); also elsewhere on the board
/Control Logic/~NI: U21.20 (I/O6); also elsewhere on the board
/Control Logic/~PS2_DR: U5.13 (D4); also elsewhere on the board
/Control Logic/~RI: U21.21 (I/O7); also elsewhere on the board
/Control Logic/~RO: U21.19 (I/O5); also elsewhere on the board
/Control Logic/~TI: U7.11; also elsewhere on the board
/Control Logic/~TO: U7.6; also elsewhere on the board
/Control Logic/~UART_DR: U5.7 (D2); also elsewhere on the board
/Control Logic/~VGA_GET: U4.8; also elsewhere on the board
/Control Logic/~VGA_TRY: U7.3; also elsewhere on the board
/Control Logic/~VREG_OE: U4.10, U6.13, U7.1; also elsewhere on the board
CLK_MAR: U6.1, U7.2; also elsewhere on the board
CLK_REG: R27.2, U6.4, U24.2 (CP); also elsewhere on the board
GND: C32.2, C33.2, SW1.2, U4.7 (GND), U5.10 (GND), U5.14 (D5), U6.3, U6.6, U6.7 (GND), U6.9, U7.7 (GND), U10.10 (GND), U19.8 (GND), U21.16 (GND), U21.22 (~CE), U21.24 (~OE), U23.16 (GND), U23.22 (~CE), U23.24 (~OE), U24.3 (D0), U24.4 (D1), U24.5 (D2), U24.6 (D3), U24.8 (GND), U25.16 (GND), U25.22 (~CE), U25.24 (~OE), X1.7 (GND); also elsewhere on the board
unnamed: C32.1, R25.2, U4.13
unnamed: C33.1, R25.1, R26.1, U6.2, U6.5
unnamed: R26.2, U6.10
unnamed: R27.1, U5.11 (CP), U10.11 (CP)
~CLK_PLS: U4.11; also elsewhere on the board
~RESET: R2.2, SW1.1, U5.17 (D6), U24.1 (~MR); also elsewhere on the board

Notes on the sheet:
SYSTEM CLOCK SIGNALS
During the 1st of 4 clock cycles (every 2MHz), the VRAM address and data register outputs are disabled. During this time, a video data byte is fed from the scan position to the shift regsiter.
In the 2nd half of the 1st cycle, the VRAM outputs the next data byte. The trailing rising edge of ~{VGA_GET} updates the scan position.
SC, PC, MAR, BANK
Used by ~{RI} and UART clock.
INSTRUCTION REGISTER
4xMAR, 2xBANK, 1xVGA, (1xExpansion)
(1xFR, 1xIR), 1xSC, 1xA, 1xB, 4xPC
STEP COUNTER
Used as R(C) constant to avoid switching spikes in the control signal (ES/EC) due to differences in switching times of 74HC377 and 74HC161. 74HC161 has switching times of ~15ns. 74HC377 has switching times of ~10ns and thus needs R27 = 470R (>380R). Note: I also came accross a 74HC161 with switchin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
FLAGS REGISTER (ZL, ZH, C, N, UART_DR, PS2_DR, RESET)
WORKS! CHECK FOR SPIKES ON TI!

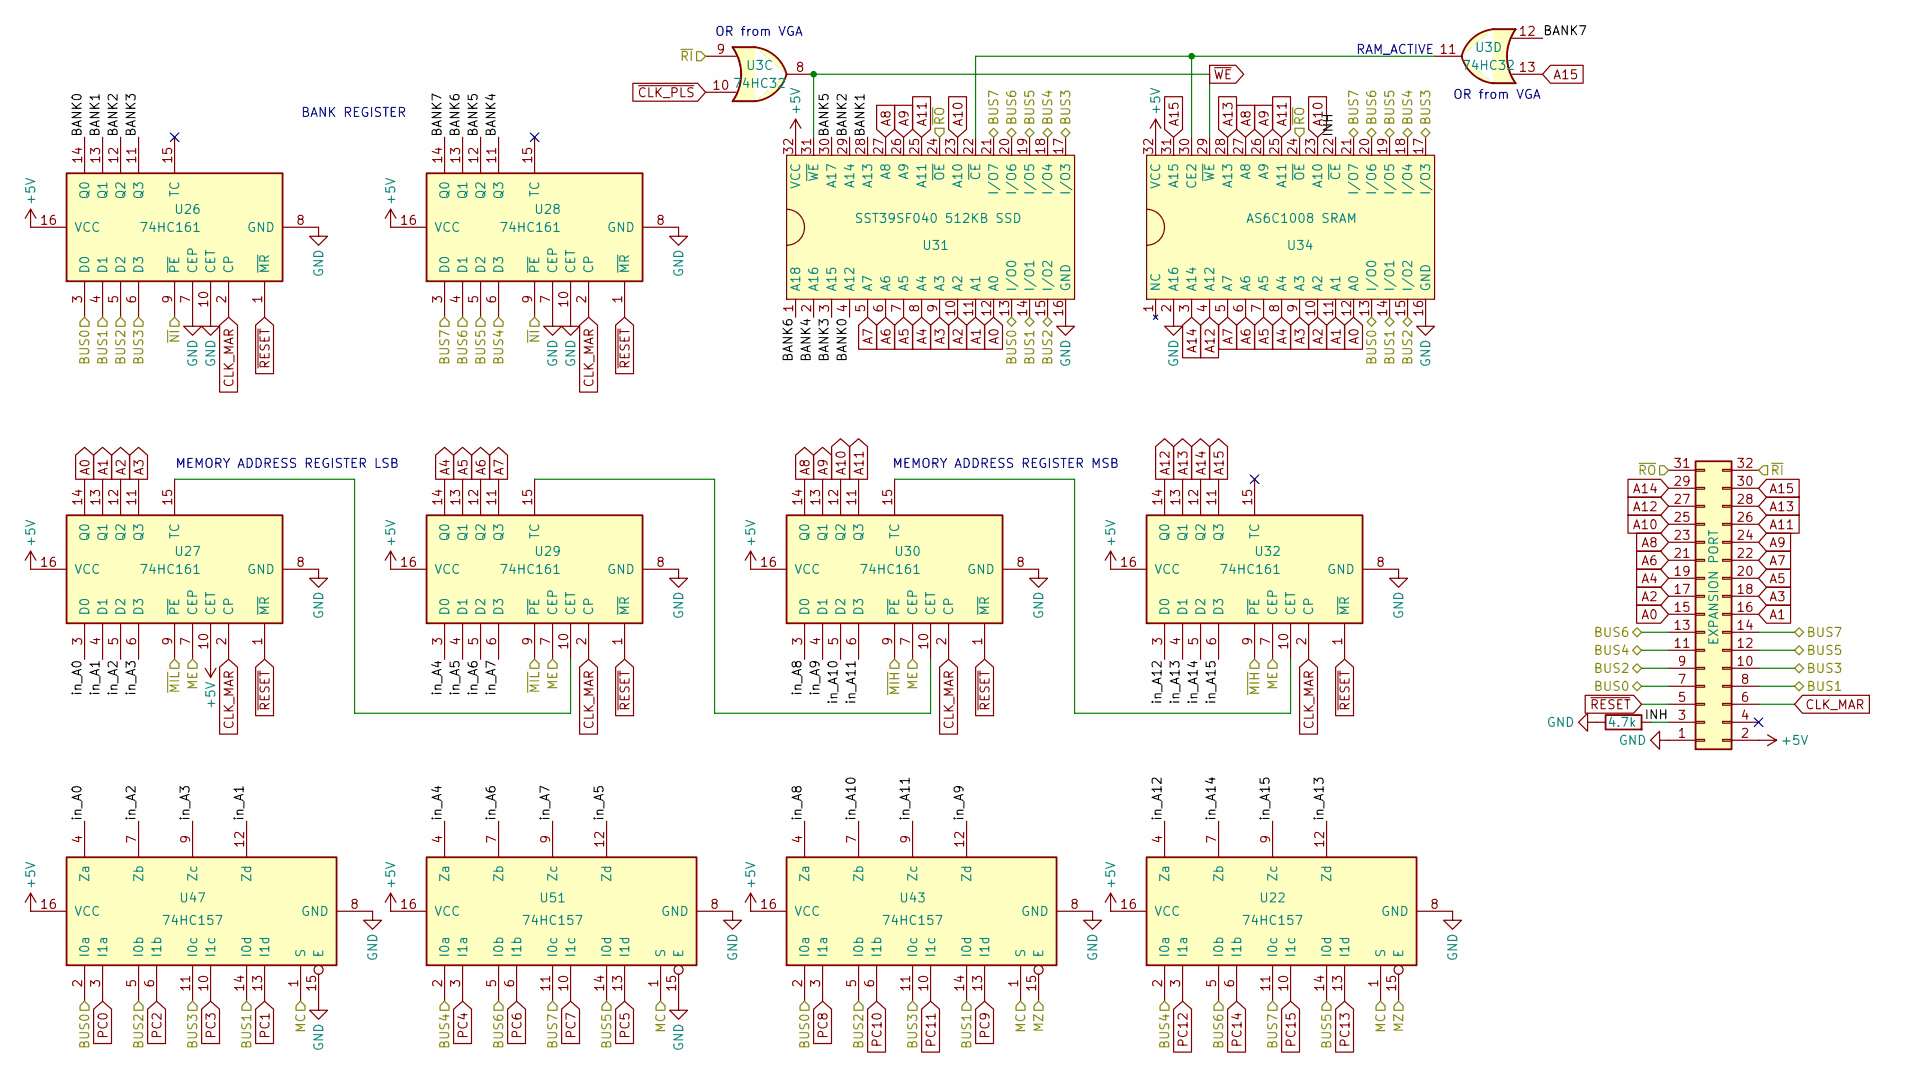
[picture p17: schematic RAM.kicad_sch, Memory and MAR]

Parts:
J3: EXPANSION PORT; PinSocket_2x16_P2.54mm_Vertical
R5: 4.7k; R_Axial_DIN0207_L6.3mm_D2.5mm_P7.62mm_Horizontal
U3: 74HC32; DIP-14_W7.62mm_Socket
U22, U43, U47, U51: 74HC157; DIP-16_W7.62mm_Socket
U26, U27, U28, U29, U30, U32: 74HC161; DIP-16_W7.62mm_Socket
U31: SST39SF040 512KB SSD; DIP-32_W15.24mm_Socket
U34: AS6C1008 SRAM; DIP-32_W15.24mm_Socket

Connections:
+5V: J3.2, U22.16 (VCC), U26.16 (VCC), U27.10 (CET), U27.16 (VCC), U28.16 (VCC), U29.16 (VCC), U30.16 (VCC), U31.32 (VCC), U32.16 (VCC), U34.32 (VCC), U43.16 (VCC), U47.16 (VCC), U51.16 (VCC); also elsewhere on the board
/ALU/BUS0: J3.7, U26.3 (D0), U31.13 (I/O0), U34.13 (I/O0), U43.2 (I0a), U47.2 (I0a); also elsewhere on the board
/ALU/BUS1: J3.8, U26.4 (D1), U31.14 (I/O1), U34.14 (I/O1), U43.14 (I0d), U47.14 (I0d); also elsewhere on the board
/ALU/BUS2: J3.9, U26.5 (D2), U31.15 (I/O2), U34.15 (I/O2), U43.5 (I0b), U47.5 (I0b); also elsewhere on the board
/ALU/BUS3: J3.10, U26.6 (D3), U31.17 (I/O3), U34.17 (I/O3), U43.11 (I0c), U47.11 (I0c); also elsewhere on the board
/ALU/BUS4: J3.11, U22.2 (I0a), U28.6 (D3), U31.18 (I/O4), U34.18 (I/O4), U51.2 (I0a); also elsewhere on the board
/ALU/BUS5: J3.12, U22.14 (I0d), U28.5 (D2), U31.19 (I/O5), U34.19 (I/O5), U51.14 (I0d); also elsewhere on the board
/ALU/BUS6: J3.13, U22.5 (I0b), U28.4 (D1), U31.20 (I/O6), U34.20 (I/O6), U51.5 (I0b); also elsewhere on the board
/ALU/BUS7: J3.14, U22.11 (I0c), U28.3 (D0), U31.21 (I/O7), U34.21 (I/O7), U51.11 (I0c); also elsewhere on the board
/Control Logic/MC: U22.1 (S), U43.1 (S), U47.1 (S), U51.1 (S); also elsewhere on the board
/Control Logic/ME: U27.7 (CEP), U29.7 (CEP), U30.7 (CEP), U32.7 (CEP); also elsewhere on the board
/Control Logic/MZ: U22.15 (E), U43.15 (E); also elsewhere on the board
/Control Logic/~MIH: U30.9 (~PE), U32.9 (~PE); also elsewhere on the board
/Control Logic/~MIL: U27.9 (~PE), U29.9 (~PE); also elsewhere on the board
/Control Logic/~NI: U26.9 (~PE), U28.9 (~PE); also elsewhere on the board
/Control Logic/~RI: J3.32, U3.9; also elsewhere on the board
/Control Logic/~RO: J3.31, U31.24 (~OE), U34.24 (~OE); also elsewhere on the board
/Memory and MAR/BANK0: U26.14 (Q0), U31.4 (A12)
/Memory and MAR/BANK1: U26.13 (Q1), U31.28 (A13)
/Memory and MAR/BANK2: U26.12 (Q2), U31.29 (A14)
/Memory and MAR/BANK3: U26.11 (Q3), U31.3 (A15)
/Memory and MAR/BANK4: U28.11 (Q3), U31.2 (A16)
/Memory and MAR/BANK5: U28.12 (Q2), U31.30 (A17)
/Memory and MAR/BANK6: U28.13 (Q1), U31.1 (A18)
/Memory and MAR/BANK7: U3.12, U28.14 (Q0)
/Memory and MAR/INH: J3.3, R5.2, U34.22 (~CE)
/Memory and MAR/in_A0: U27.3 (D0), U47.4 (Za)
/Memory and MAR/in_A1: U27.4 (D1), U47.12 (Zd)
/Memory and MAR/in_A2: U27.5 (D2), U47.7 (Zb)
/Memory and MAR/in_A3: U27.6 (D3), U47.9 (Zc)
/Memory and MAR/in_A4: U29.3 (D0), U51.4 (Za)
/Memory and MAR/in_A5: U29.4 (D1), U51.12 (Zd)
/Memory and MAR/in_A6: U29.5 (D2), U51.7 (Zb)
/Memory and MAR/in_A7: U29.6 (D3), U51.9 (Zc)
/Memory and MAR/in_A8: U30.3 (D0), U43.4 (Za)
/Memory and MAR/in_A9: U30.4 (D1), U43.12 (Zd)
/Memory and MAR/in_A10: U30.5 (D2), U43.7 (Zb)
/Memory and MAR/in_A11: U30.6 (D3), U43.9 (Zc)
/Memory and MAR/in_A12: U22.4 (Za), U32.3 (D0)
/Memory and MAR/in_A13: U22.12 (Zd), U32.4 (D1)
/Memory and MAR/in_A14: U22.7 (Zb), U32.5 (D2)
/Memory and MAR/in_A15: U22.9 (Zc), U32.6 (D3)
A0: J3.15, U27.14 (Q0), U31.12 (A0), U34.12 (A0); also elsewhere on the board
A1: J3.16, U27.13 (Q1), U31.11 (A1), U34.11 (A1); also elsewhere on the board
A2: J3.17, U27.12 (Q2), U31.10 (A2), U34.10 (A2); also elsewhere on the board
A3: J3.18, U27.11 (Q3), U31.9 (A3), U34.9 (A3); also elsewhere on the board
A4: J3.19, U29.14 (Q0), U31.8 (A4), U34.8 (A4); also elsewhere on the board
A5: J3.20, U29.13 (Q1), U31.7 (A5), U34.7 (A5); also elsewhere on the board
A6: J3.21, U29.12 (Q2), U31.6 (A6), U34.6 (A6); also elsewhere on the board
A7: J3.22, U29.11 (Q3), U31.5 (A7), U34.5 (A7); also elsewhere on the board
A8: J3.23, U30.14 (Q0), U31.27 (A8), U34.27 (A8); also elsewhere on the board
A9: J3.24, U30.13 (Q1), U31.26 (A9), U34.26 (A9); also elsewhere on the board
A10: J3.25, U30.12 (Q2), U31.23 (A10), U34.23 (A10); also elsewhere on the board
A11: J3.26, U30.11 (Q3), U31.25 (A11), U34.25 (A11); also elsewhere on the board
A12: J3.27, U32.14 (Q0), U34.4 (A12); also elsewhere on the board
A13: J3.28, U32.13 (Q1), U34.28 (A13); also elsewhere on the board
A14: J3.29, U32.12 (Q2), U34.3 (A14); also elsewhere on the board
A15: J3.30, U3.13, U32.11 (Q3), U34.31 (A15); also elsewhere on the board
CLK_MAR: J3.6, U26.2 (CP), U27.2 (CP), U28.2 (CP), U29.2 (CP), U30.2 (CP), U32.2 (CP); also elsewhere on the board
GND: J3.1, R5.1, U22.8 (GND), U26.7 (CEP), U26.8 (GND), U26.10 (CET), U27.8 (GND), U28.7 (CEP), U28.8 (GND), U28.10 (CET), U29.8 (GND), U30.8 (GND), U31.16 (GND), U32.8 (GND), U34.2 (A16), U34.16 (GND), U43.8 (GND), U47.8 (GND), U47.15 (E), U51.8 (GND), U51.15 (E); also elsewhere on the board
unnamed: U27.15 (TC), U29.10 (CET)
unnamed: U29.15 (TC), U30.10 (CET)
unnamed: U30.15 (TC), U32.10 (CET)
unnamed: U3.11, U31.22 (~CE), U34.30 (CE2)
PC0: U47.3 (I1a); also elsewhere on the board
PC1: U47.13 (I1d); also elsewhere on the board
PC2: U47.6 (I1b); also elsewhere on the board
PC3: U47.10 (I1c); also elsewhere on the board
PC4: U51.3 (I1a); also elsewhere on the board
PC5: U51.13 (I1d); also elsewhere on the board
PC6: U51.6 (I1b); also elsewhere on the board
PC7: U51.10 (I1c); also elsewhere on the board
PC8: U43.3 (I1a); also elsewhere on the board
PC9: U43.13 (I1d); also elsewhere on the board
PC10: U43.6 (I1b); also elsewhere on the board
PC11: U43.10 (I1c); also elsewhere on the board
PC12: U22.3 (I1a); also elsewhere on the board
PC13: U22.13 (I1d); also elsewhere on the board
PC14: U22.6 (I1b); also elsewhere on the board
PC15: U22.10 (I1c); also elsewhere on the board
~CLK_PLS: U3.10; also elsewhere on the board
~RESET: J3.5, U26.1 (~MR), U27.1 (~MR), U28.1 (~MR), U29.1 (~MR), U30.1 (~MR), U32.1 (~MR); also elsewhere on the board
~WE: U3.8, U31.31 (~WE), U34.29 (~WE); also elsewhere on the board

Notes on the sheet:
MEMORY ADDRESS REGISTER MSB
OR from VGA
MEMORY ADDRESS REGISTER LSB
RAM_ACTIVE
BANK REGISTER

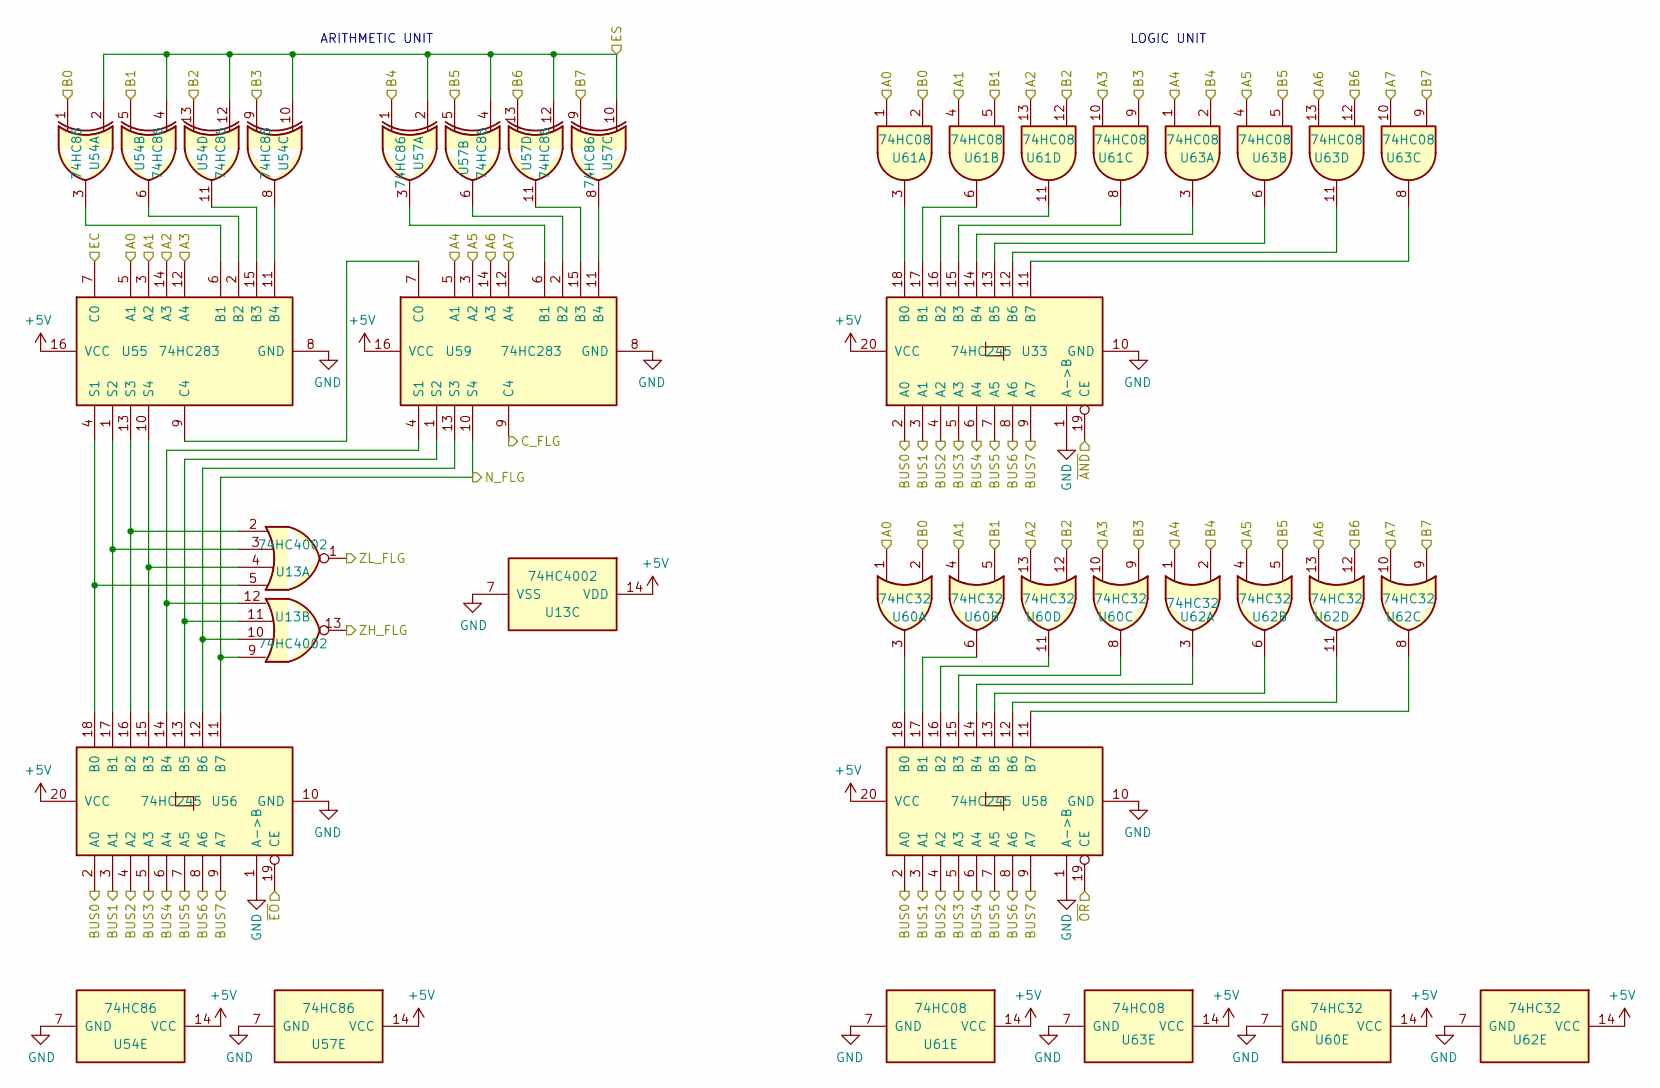
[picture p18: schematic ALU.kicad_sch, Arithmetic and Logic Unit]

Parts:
U13: 74HC4002; DIP-14_W7.62mm_Socket
U33, U56, U58: 74HC245; DIP-20_W7.62mm_Socket
U54, U57: 74HC86; DIP-14_W7.62mm_Socket
U55, U59: 74HC283; DIP-16_W7.62mm_Socket
U60, U62: 74HC32; DIP-14_W7.62mm_Socket
U61, U63: 74HC08; DIP-14_W7.62mm_Socket

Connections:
+5V: U13.14 (VDD), U33.20 (VCC), U54.14 (VCC), U55.16 (VCC), U56.20 (VCC), U57.14 (VCC), U58.20 (VCC), U59.16 (VCC), U60.14 (VCC), U61.14 (VCC), U62.14 (VCC), U63.14 (VCC); also elsewhere on the board
/ALU/A0: U55.5 (A1), U60.1, U61.1; also elsewhere on the board
/ALU/A1: U55.3 (A2), U60.4, U61.4; also elsewhere on the board
/ALU/A2: U55.14 (A3), U60.13, U61.13; also elsewhere on the board
/ALU/A3: U55.12 (A4), U60.10, U61.10; also elsewhere on the board
/ALU/A4: U59.5 (A1), U62.1, U63.1; also elsewhere on the board
/ALU/A5: U59.3 (A2), U62.4, U63.4; also elsewhere on the board
/ALU/A6: U59.14 (A3), U62.13, U63.13; also elsewhere on the board
/ALU/A7: U59.12 (A4), U62.10, U63.10; also elsewhere on the board
/ALU/B0: U54.1, U60.2, U61.2; also elsewhere on the board
/ALU/B1: U54.5, U60.5, U61.5; also elsewhere on the board
/ALU/B2: U54.13, U60.12, U61.12; also elsewhere on the board
/ALU/B3: U54.9, U60.9, U61.9; also elsewhere on the board
/ALU/B4: U57.1, U62.2, U63.2; also elsewhere on the board
/ALU/B5: U57.5, U62.5, U63.5; also elsewhere on the board
/ALU/B6: U57.13, U62.12, U63.12; also elsewhere on the board
/ALU/B7: U57.9, U62.9, U63.9; also elsewhere on the board
/ALU/BUS0: U33.2 (A0), U56.2 (A0), U58.2 (A0); also elsewhere on the board
/ALU/BUS1: U33.3 (A1), U56.3 (A1), U58.3 (A1); also elsewhere on the board
/ALU/BUS2: U33.4 (A2), U56.4 (A2), U58.4 (A2); also elsewhere on the board
/ALU/BUS3: U33.5 (A3), U56.5 (A3), U58.5 (A3); also elsewhere on the board
/ALU/BUS4: U33.6 (A4), U56.6 (A4), U58.6 (A4); also elsewhere on the board
/ALU/BUS5: U33.7 (A5), U56.7 (A5), U58.7 (A5); also elsewhere on the board
/ALU/BUS6: U33.8 (A6), U56.8 (A6), U58.8 (A6); also elsewhere on the board
/ALU/BUS7: U33.9 (A7), U56.9 (A7), U58.9 (A7); also elsewhere on the board
/ALU/C_FLG: U59.9 (C4); also elsewhere on the board
/ALU/EC: U55.7 (C0); also elsewhere on the board
/ALU/ES: U54.2, U54.4, U54.10, U54.12, U57.2, U57.4, U57.10, U57.12; also elsewhere on the board
/ALU/N_FLG: U13.9, U56.11 (B7), U59.10 (S4); also elsewhere on the board
/ALU/ZH_FLG: U13.13; also elsewhere on the board
/ALU/ZL_FLG: U13.1; also elsewhere on the board
/ALU/~AND: U33.19 (CE); also elsewhere on the board
/ALU/~EO: U56.19 (CE); also elsewhere on the board
/ALU/~OR: U58.19 (CE); also elsewhere on the board
GND: U13.7 (VSS), U33.1 (A->B), U33.10 (GND), U54.7 (GND), U55.8 (GND), U56.1 (A->B), U56.10 (GND), U57.7 (GND), U58.1 (A->B), U58.10 (GND), U59.8 (GND), U60.7 (GND), U61.7 (GND), U62.7 (GND), U63.7 (GND); also elsewhere on the board
unnamed: U33.18 (B0), U61.3
unnamed: U33.17 (B1), U61.6
unnamed: U33.16 (B2), U61.11
unnamed: U33.15 (B3), U61.8
unnamed: U33.14 (B4), U63.3
unnamed: U33.13 (B5), U63.6
unnamed: U33.12 (B6), U63.11
unnamed: U33.11 (B7), U63.8
unnamed: U54.3, U55.6 (B1)
unnamed: U54.6, U55.2 (B2)
unnamed: U54.11, U55.15 (B3)
unnamed: U54.8, U55.11 (B4)
unnamed: U55.9 (C4), U59.7 (C0)
unnamed: U13.5, U55.4 (S1), U56.18 (B0)
unnamed: U13.3, U55.1 (S2), U56.17 (B1)
unnamed: U13.2, U55.13 (S3), U56.16 (B2)
unnamed: U13.4, U55.10 (S4), U56.15 (B3)
unnamed: U13.12, U56.14 (B4), U59.4 (S1)
unnamed: U13.11, U56.13 (B5), U59.1 (S2)
unnamed: U13.10, U56.12 (B6), U59.13 (S3)
unnamed: U58.18 (B0), U60.3
unnamed: U58.17 (B1), U60.6
unnamed: U58.16 (B2), U60.11
unnamed: U58.15 (B3), U60.8
unnamed: U58.14 (B4), U62.3
unnamed: U58.13 (B5), U62.6
unnamed: U58.12 (B6), U62.11
unnamed: U58.11 (B7), U62.8
unnamed: U57.3, U59.6 (B1)
unnamed: U57.6, U59.2 (B2)
unnamed: U57.11, U59.15 (B3)
unnamed: U57.8, U59.11 (B4)

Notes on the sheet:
ARITHMETIC UNIT
LOGIC UNIT

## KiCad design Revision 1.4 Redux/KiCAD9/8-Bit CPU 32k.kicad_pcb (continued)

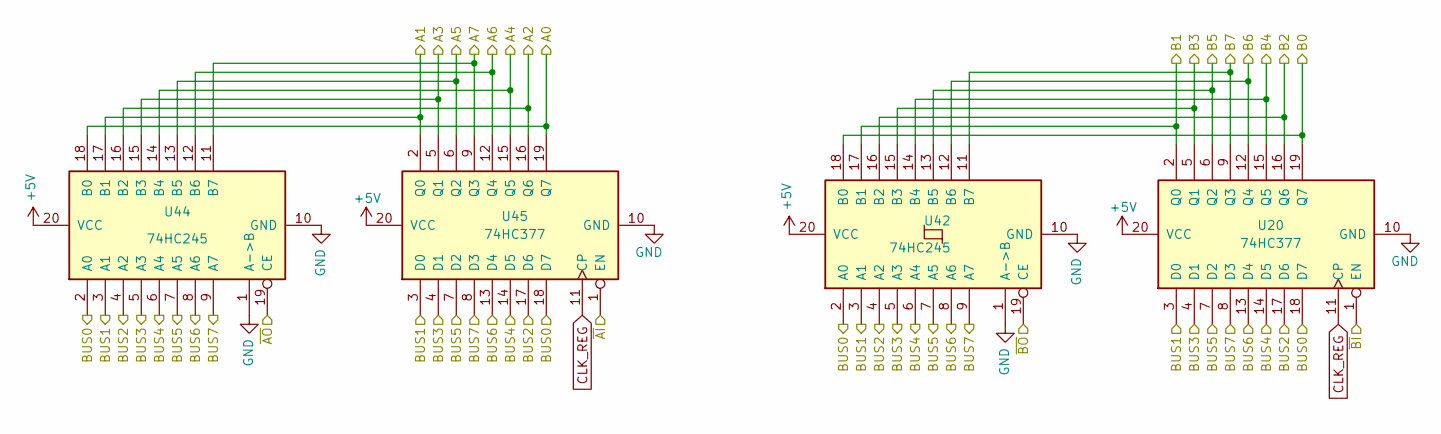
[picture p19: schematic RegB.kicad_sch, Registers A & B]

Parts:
U20, U45: 74HC377; DIP-20_W7.62mm_Socket
U42, U44: 74HC245; DIP-20_W7.62mm_Socket

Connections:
+5V: U20.20 (VCC), U42.20 (VCC), U44.20 (VCC), U45.20 (VCC); also elsewhere on the board
/ALU/A0: U44.18 (B0), U45.19 (Q7); also elsewhere on the board
/ALU/A1: U44.17 (B1), U45.2 (Q0); also elsewhere on the board
/ALU/A2: U44.16 (B2), U45.16 (Q6); also elsewhere on the board
/ALU/A3: U44.15 (B3), U45.5 (Q1); also elsewhere on the board
/ALU/A4: U44.14 (B4), U45.15 (Q5); also elsewhere on the board
/ALU/A5: U44.13 (B5), U45.6 (Q2); also elsewhere on the board
/ALU/A6: U44.12 (B6), U45.12 (Q4); also elsewhere on the board
/ALU/A7: U44.11 (B7), U45.9 (Q3); also elsewhere on the board
/ALU/B0: U20.19 (Q7), U42.18 (B0); also elsewhere on the board
/ALU/B1: U20.2 (Q0), U42.17 (B1); also elsewhere on the board
/ALU/B2: U20.16 (Q6), U42.16 (B2); also elsewhere on the board
/ALU/B3: U20.5 (Q1), U42.15 (B3); also elsewhere on the board
/ALU/B4: U20.15 (Q5), U42.14 (B4); also elsewhere on the board
/ALU/B5: U20.6 (Q2), U42.13 (B5); also elsewhere on the board
/ALU/B6: U20.12 (Q4), U42.12 (B6); also elsewhere on the board
/ALU/B7: U20.9 (Q3), U42.11 (B7); also elsewhere on the board
/ALU/BUS0: U20.18 (D7), U42.2 (A0), U44.2 (A0), U45.18 (D7); also elsewhere on the board
/ALU/BUS1: U20.3 (D0), U42.3 (A1), U44.3 (A1), U45.3 (D0); also elsewhere on the board
/ALU/BUS2: U20.17 (D6), U42.4 (A2), U44.4 (A2), U45.17 (D6); also elsewhere on the board
/ALU/BUS3: U20.4 (D1), U42.5 (A3), U44.5 (A3), U45.4 (D1); also elsewhere on the board
/ALU/BUS4: U20.14 (D5), U42.6 (A4), U44.6 (A4), U45.14 (D5); also elsewhere on the board
/ALU/BUS5: U20.7 (D2), U42.7 (A5), U44.7 (A5), U45.7 (D2); also elsewhere on the board
/ALU/BUS6: U20.13 (D4), U42.8 (A6), U44.8 (A6), U45.13 (D4); also elsewhere on the board
/ALU/BUS7: U20.8 (D3), U42.9 (A7), U44.9 (A7), U45.8 (D3); also elsewhere on the board
/Control Logic/~AI: U45.1 (EN); also elsewhere on the board
/Control Logic/~AO: U44.19 (CE); also elsewhere on the board
/Control Logic/~BI: U20.1 (EN); also elsewhere on the board
/Control Logic/~BO: U42.19 (CE); also elsewhere on the board
CLK_REG: U20.11 (CP), U45.11 (CP); also elsewhere on the board
GND: U20.10 (GND), U42.1 (A->B), U42.10 (GND), U44.1 (A->B), U44.10 (GND), U45.10 (GND); also elsewhere on the board

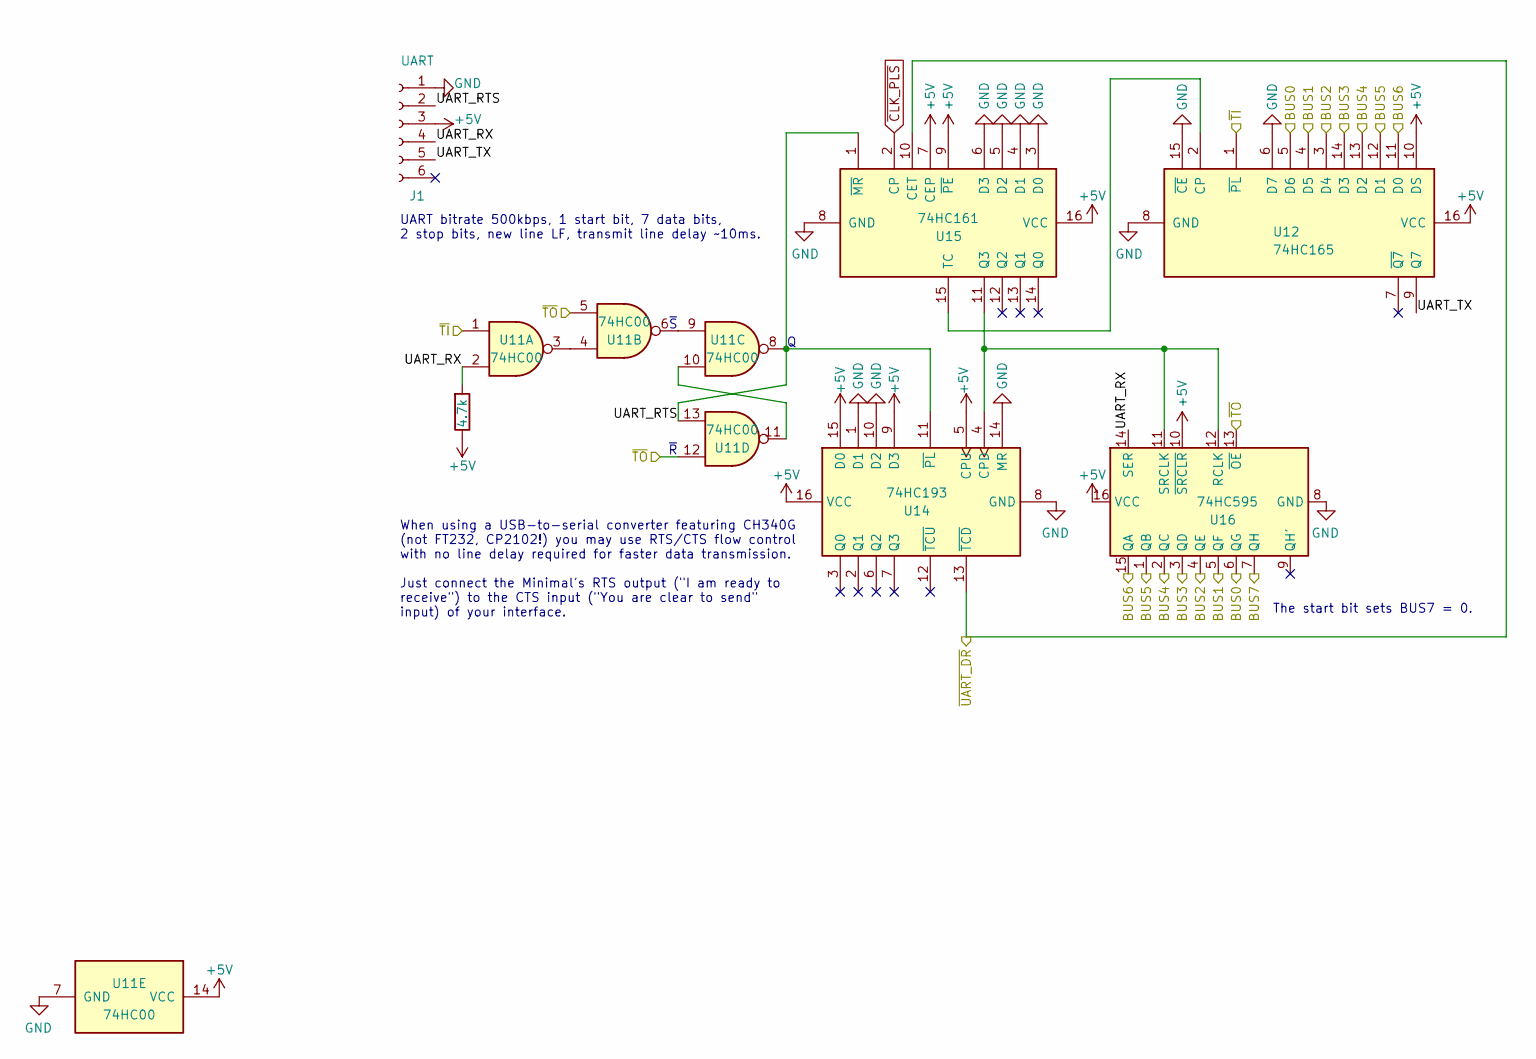
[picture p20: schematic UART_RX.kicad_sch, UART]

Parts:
J1: UART; PinSocket_1x06_P2.54mm_Vertical
R1: 4.7k; R_Axial_DIN0207_L6.3mm_D2.5mm_P7.62mm_Horizontal
U11: 74HC00; DIP-14_W7.62mm_Socket
U12: 74HC165; DIP-16_W7.62mm_Socket
U14: 74HC193; DIP-16_W7.62mm_Socket
U15: 74HC161; DIP-16_W7.62mm_Socket
U16: 74HC595; DIP-16_W7.62mm_Socket

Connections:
+5V: J1.3, R1.1, U11.14 (VCC), U12.10 (DS), U12.16 (VCC), U14.5 (CPU), U14.9 (D3), U14.15 (D0), U14.16 (VCC), U15.7 (CEP), U15.9 (~PE), U15.16 (VCC), U16.10 (~SRCLR), U16.16 (VCC); also elsewhere on the board
/ALU/BUS0: U12.5 (D6), U16.6 (QG); also elsewhere on the board
/ALU/BUS1: U12.4 (D5), U16.5 (QF); also elsewhere on the board
/ALU/BUS2: U12.3 (D4), U16.4 (QE); also elsewhere on the board
/ALU/BUS3: U12.14 (D3), U16.3 (QD); also elsewhere on the board
/ALU/BUS4: U12.13 (D2), U16.2 (QC); also elsewhere on the board
/ALU/BUS5: U12.12 (D1), U16.1 (QB); also elsewhere on the board
/ALU/BUS6: U12.11 (D0), U16.15 (QA); also elsewhere on the board
/ALU/BUS7: U16.7 (QH); also elsewhere on the board
/Control Logic/~TI: U11.1, U12.1 (~PL); also elsewhere on the board
/Control Logic/~TO: U11.5, U11.12, U16.13 (~OE); also elsewhere on the board
/Control Logic/~UART_DR: U14.13 (~TCD), U15.10 (CET); also elsewhere on the board
/UART/UART_RTS: J1.2, U11.8, U11.13, U14.11 (~PL), U15.1 (~MR)
/UART/UART_RX: J1.4, R1.2, U11.2, U16.14 (SER)
/UART/UART_TX: J1.5, U12.9 (Q7)
GND: J1.1, U11.7 (GND), U12.6 (D7), U12.8 (GND), U12.15 (~CE), U14.1 (D1), U14.8 (GND), U14.10 (D2), U14.14 (MR), U15.3 (D0), U15.4 (D1), U15.5 (D2), U15.6 (D3), U15.8 (GND), U16.8 (GND); also elsewhere on the board
unnamed: U11.3, U11.4
unnamed: U11.6, U11.9
unnamed: U11.10, U11.11
unnamed: U12.2 (CP), U15.15 (TC)
unnamed: U14.4 (CPD), U15.11 (Q3), U16.11 (SRCLK), U16.12 (RCLK)
~CLK_PLS: U15.2 (CP); also elsewhere on the board

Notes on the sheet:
~{S}
UART bitrate 500kbps, 1 start bit, 7 data bits, 2 stop bits, new line LF, transmit line delay ~10ms.
~{R}
The start bit sets BUS7 = 0.
When using a USB-to-serial converter featuring CH340G (not FT232, CP2102!) you may use RTS/CTS flow control with no line delay required for faster data transmission. Just connect the Minimal's RTS output ("I am ready to receive") to the CTS input ("You are clear to send" input) of your interface.

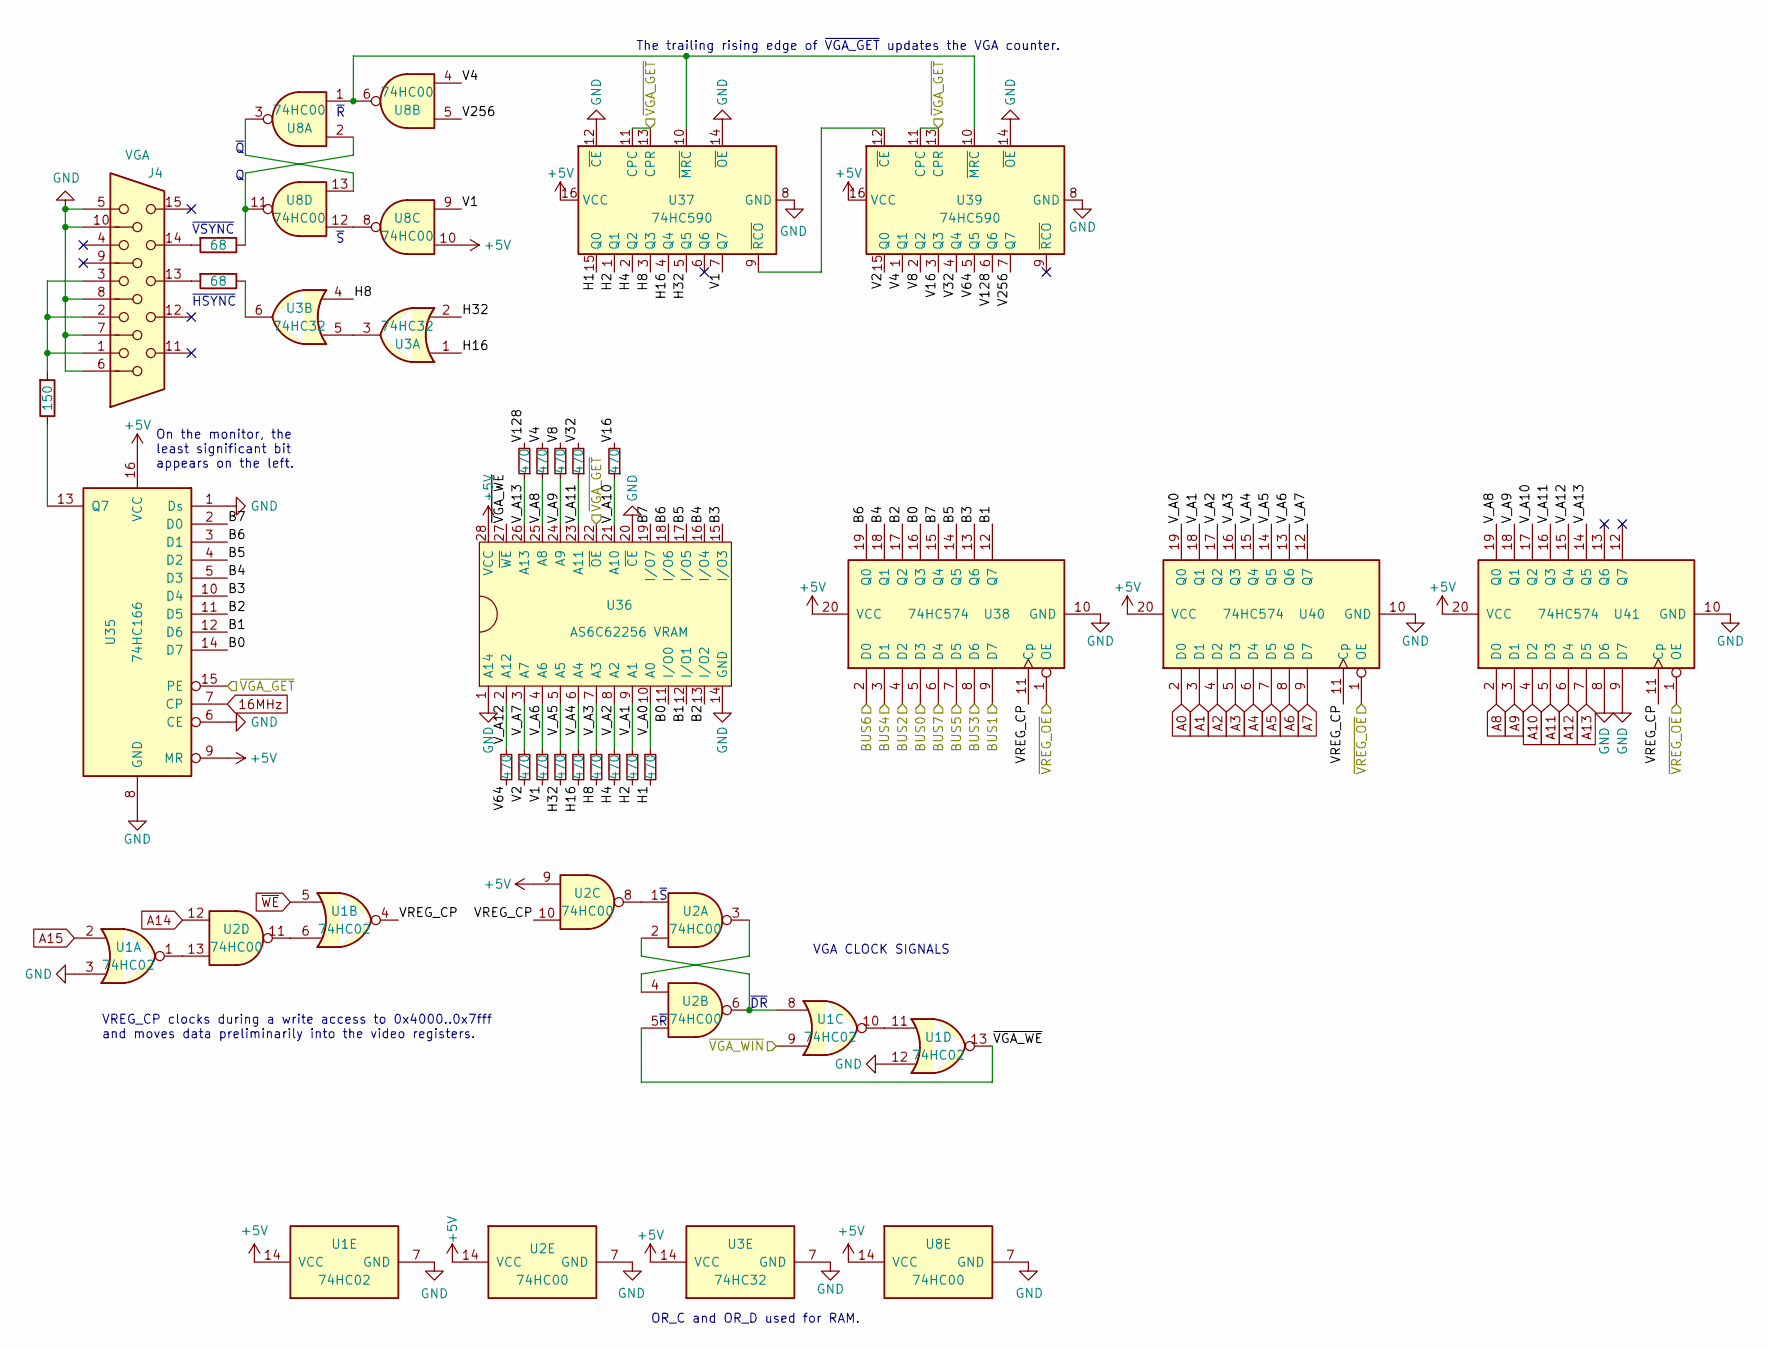
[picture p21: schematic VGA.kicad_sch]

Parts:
J4: VGA; VGA DSUB15HD_female
R6: 150; R_Axial_DIN0207_L6.3mm_D2.5mm_P7.62mm_Horizontal
R7, R8: 68; R_Axial_DIN0207_L6.3mm_D2.5mm_P7.62mm_Horizontal
R9, R10, R11, R12, R13, R14, R15, R16, R17, R18, R19, R20, R21, R22: 470; R_Axial_DIN0207_L6.3mm_D2.5mm_P7.62mm_Horizontal
U1: 74HC02; DIP-14_W7.62mm_Socket
U2, U8: 74HC00; DIP-14_W7.62mm_Socket
U3: 74HC32; DIP-14_W7.62mm_Socket
U35: 74HC166; DIP-16_W7.62mm_Socket
U36: AS6C62256 VRAM; DIP-28_W15.24mm_Socket
U37, U39: 74HC590; DIP-16_W7.62mm_Socket
U38, U40, U41: 74HC574; DIP-20_W7.62mm_Socket

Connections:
16MHz: U35.7 (CP); also elsewhere on the board
+5V: U1.14 (VCC), U2.9, U2.14 (VCC), U3.14 (VCC), U8.10, U8.14 (VCC), U35.9 (MR), U35.16 (VCC), U36.28 (VCC), U37.16 (VCC), U38.20 (VCC), U39.16 (VCC), U40.20 (VCC), U41.20 (VCC); also elsewhere on the board
/ALU/BUS0: U38.5 (D3); also elsewhere on the board
/ALU/BUS1: U38.9 (D7); also elsewhere on the board
/ALU/BUS2: U38.4 (D2); also elsewhere on the board
/ALU/BUS3: U38.8 (D6); also elsewhere on the board
/ALU/BUS4: U38.3 (D1); also elsewhere on the board
/ALU/BUS5: U38.7 (D5); also elsewhere on the board
/ALU/BUS6: U38.2 (D0); also elsewhere on the board
/ALU/BUS7: U38.6 (D4); also elsewhere on the board
/Control Logic/~VGA_GET: U35.15 (PE), U36.22 (~OE), U37.11 (CPC), U37.13 (CPR), U39.11 (CPC), U39.13 (CPR); also elsewhere on the board
/Control Logic/~VGA_TRY: U1.9; also elsewhere on the board
/Control Logic/~VREG_OE: U38.1 (OE), U40.1 (OE), U41.1 (OE); also elsewhere on the board
/VGA/B0: U35.14 (D7), U36.11 (I/O0), U38.16 (Q3)
/VGA/B1: U35.12 (D6), U36.12 (I/O1), U38.12 (Q7)
/VGA/B2: U35.11 (D5), U36.13 (I/O2), U38.17 (Q2)
/VGA/B3: U35.10 (D4), U36.15 (I/O3), U38.13 (Q6)
/VGA/B4: U35.5 (D3), U36.16 (I/O4), U38.18 (Q1)
/VGA/B5: U35.4 (D2), U36.17 (I/O5), U38.14 (Q5)
/VGA/B6: U35.3 (D1), U36.18 (I/O6), U38.19 (Q0)
/VGA/B7: U35.2 (D0), U36.19 (I/O7), U38.15 (Q4)
/VGA/H1: R9.2, U37.15 (Q0)
/VGA/H2: R10.2, U37.1 (Q1)
/VGA/H4: R11.2, U37.2 (Q2)
/VGA/H8: R12.2, U3.4, U37.3 (Q3)
/VGA/H16: R13.2, U3.1, U37.4 (Q4)
/VGA/H32: R14.2, U3.2, U37.5 (Q5)
/VGA/V1: R15.2, U8.9, U37.7 (Q7)
/VGA/V2: R16.2, U39.15 (Q0)
/VGA/V4: R17.2, U8.4, U39.1 (Q1)
/VGA/V8: R18.2, U39.2 (Q2)
/VGA/V16: R19.2, U39.3 (Q3)
/VGA/V32: R20.2, U39.4 (Q4)
/VGA/V64: R21.2, U39.5 (Q5)
/VGA/V128: R22.2, U39.6 (Q6)
/VGA/V256: U8.5, U39.7 (Q7)
/VGA/VREG_CP: U1.4, U2.10, U38.11 (Cp), U40.11 (Cp), U41.11 (Cp)
/VGA/V_A0: R9.1, U36.10 (A0), U40.19 (Q0)
/VGA/V_A1: R10.1, U36.9 (A1), U40.18 (Q1)
/VGA/V_A2: R11.1, U36.8 (A2), U40.17 (Q2)
/VGA/V_A3: R12.1, U36.7 (A3), U40.16 (Q3)
/VGA/V_A4: R13.1, U36.6 (A4), U40.15 (Q4)
/VGA/V_A5: R14.1, U36.5 (A5), U40.14 (Q5)
/VGA/V_A6: R15.1, U36.4 (A6), U40.13 (Q6)
/VGA/V_A7: R16.1, U36.3 (A7), U40.12 (Q7)
/VGA/V_A8: R17.1, U36.25 (A8), U41.19 (Q0)
/VGA/V_A9: R18.1, U36.24 (A9), U41.18 (Q1)
/VGA/V_A10: R19.1, U36.21 (A10), U41.17 (Q2)
/VGA/V_A11: R20.1, U36.23 (A11), U41.16 (Q3)
/VGA/V_A12: R21.1, U36.2 (A12), U41.15 (Q4)
/VGA/V_A13: R22.1, U36.26 (A13), U41.14 (Q5)
/VGA/~VGA_WE: U1.13, U2.5, U36.27 (~WE)
A0: U40.2 (D0); also elsewhere on the board
A1: U40.3 (D1); also elsewhere on the board
A2: U40.4 (D2); also elsewhere on the board
A3: U40.5 (D3); also elsewhere on the board
A4: U40.6 (D4); also elsewhere on the board
A5: U40.7 (D5); also elsewhere on the board
A6: U40.8 (D6); also elsewhere on the board
A7: U40.9 (D7); also elsewhere on the board
A8: U41.2 (D0); also elsewhere on the board
A9: U41.3 (D1); also elsewhere on the board
A10: U41.4 (D2); also elsewhere on the board
A11: U41.5 (D3); also elsewhere on the board
A12: U41.6 (D4); also elsewhere on the board
A13: U41.7 (D5); also elsewhere on the board
A14: U2.12; also elsewhere on the board
A15: U1.2; also elsewhere on the board
GND: J4.5, J4.6, J4.7, J4.8, J4.10, U1.3, U1.7 (GND), U1.12, U2.7 (GND), U3.7 (GND), U8.7 (GND), U35.1 (Ds), U35.6 (CE), U35.8 (GND), U36.1 (A14), U36.14 (GND), U36.20 (~CE), U37.8 (GND), U37.12 (~CE), U37.14 (~OE), U38.10 (GND), U39.8 (GND), U39.14 (~OE), U40.10 (GND), U41.8 (D6), U41.9 (D7), U41.10 (GND); also elsewhere on the board
unnamed: J4.1, J4.2, J4.3, R6.2
unnamed: J4.13, R8.2
unnamed: J4.14, R7.2
unnamed: R7.1, U8.2, U8.11
unnamed: R8.1, U3.6
unnamed: U1.1, U2.13
unnamed: U1.6, U2.11
unnamed: U1.8, U2.2, U2.6
unnamed: U1.10, U1.11
unnamed: U2.1, U2.8
unnamed: U2.3, U2.4
unnamed: U3.3, U3.5
unnamed: U8.8, U8.12
unnamed: U8.3, U8.13
unnamed: R6.1, U35.13 (Q7)
unnamed: U8.1, U8.6, U37.10 (~MRC), U39.10 (~MRC)
unnamed: U37.9 (~RCO), U39.12 (~CE)
~WE: U1.5; also elsewhere on the board

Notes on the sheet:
~{S}
VREG_CP clocks during a write access to 0x4000..0x7fff and moves data preliminarily into the video registers.
~{DR}
~{R}
On the monitor, the least significant bit appears on the left.
~{Q}
~{HSYNC}
OR_C and OR_D used for RAM.
~{VSYNC}
The trailing rising edge of ~{VGA_GET} updates the VGA counter.
VGA CLOCK SIGNALS

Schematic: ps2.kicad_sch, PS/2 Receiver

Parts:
J2: PS/2; FP_MINI_DIN_6_PS2
R3, R4: 4.7k; R_Axial_DIN0207_L6.3mm_D2.5mm_P7.62mm_Horizontal
U9: 74HCT132; DIP-14_W7.62mm_Socket
U17: 74HC595; DIP-16_W7.62mm_Socket
U18: 74HC193; DIP-16_W7.62mm_Socket

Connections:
+5V: J2.4, R3.1, R4.1, U9.9, U9.14 (VCC), U17.10 (~SRCLR), U17.16 (VCC), U18.1 (D1), U18.5 (CPU), U18.9 (D3), U18.16 (VCC); also elsewhere on the board
/ALU/BUS0: U17.7 (QH); also elsewhere on the board
/ALU/BUS1: U17.6 (QG); also elsewhere on the board
/ALU/BUS2: U17.5 (QF); also elsewhere on the board
/ALU/BUS3: U17.4 (QE); also elsewhere on the board
/ALU/BUS4: U17.3 (QD); also elsewhere on the board
/ALU/BUS5: U17.2 (QC); also elsewhere on the board
/ALU/BUS6: U17.1 (QB); also elsewhere on the board
/ALU/BUS7: U17.15 (QA); also elsewhere on the board
/Control Logic/~KO: U9.5, U17.13 (~OE); also elsewhere on the board
/Control Logic/~PS2_DR: U9.12, U18.13 (~TCD); also elsewhere on the board
/PS2 Receiver/PS2_CLK: J2.5, R3.2, U9.13
/PS2 Receiver/PS2_DAT: J2.1, R4.2, U9.1, U17.14 (SER)
GND: J2.3, U9.7 (GND), U17.8 (GND), U18.8 (GND), U18.10 (D2), U18.14 (MR), U18.15 (D0); also elsewhere on the board
unnamed: U9.2, U9.6
unnamed: U9.10, U9.11
unnamed: U17.12 (RCLK), U18.3 (Q0)
unnamed: U9.8, U17.11 (SRCLK), U18.4 (CPD)
unnamed: U9.3, U9.4, U18.11 (~PL)

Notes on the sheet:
(green)
(yellow)
~{Q}
The order of the bits is intentionally reversed.
~{TCD} goes LOW at the falling edge of CPD after reaching zero at the beginning of the high stop bit ensuring that a full transmission has been sampled. Note that RCLK is driven by Q0 which happens *after* CPD. Thus RCLK always samples the *current*, not the previous register state. RCLK is driven 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
For PS/2 devices with only 3.3V output use 74HCT132 for maximum robustness.
~{R}
~{S}
74HCxx input rise time (10-90%) is required to be <400ns. Use 74HC132 (NAND with Schmitt trigger inputs) rather than 74HC00 here, since PS/2 signals can have rise and fall times >400ns.

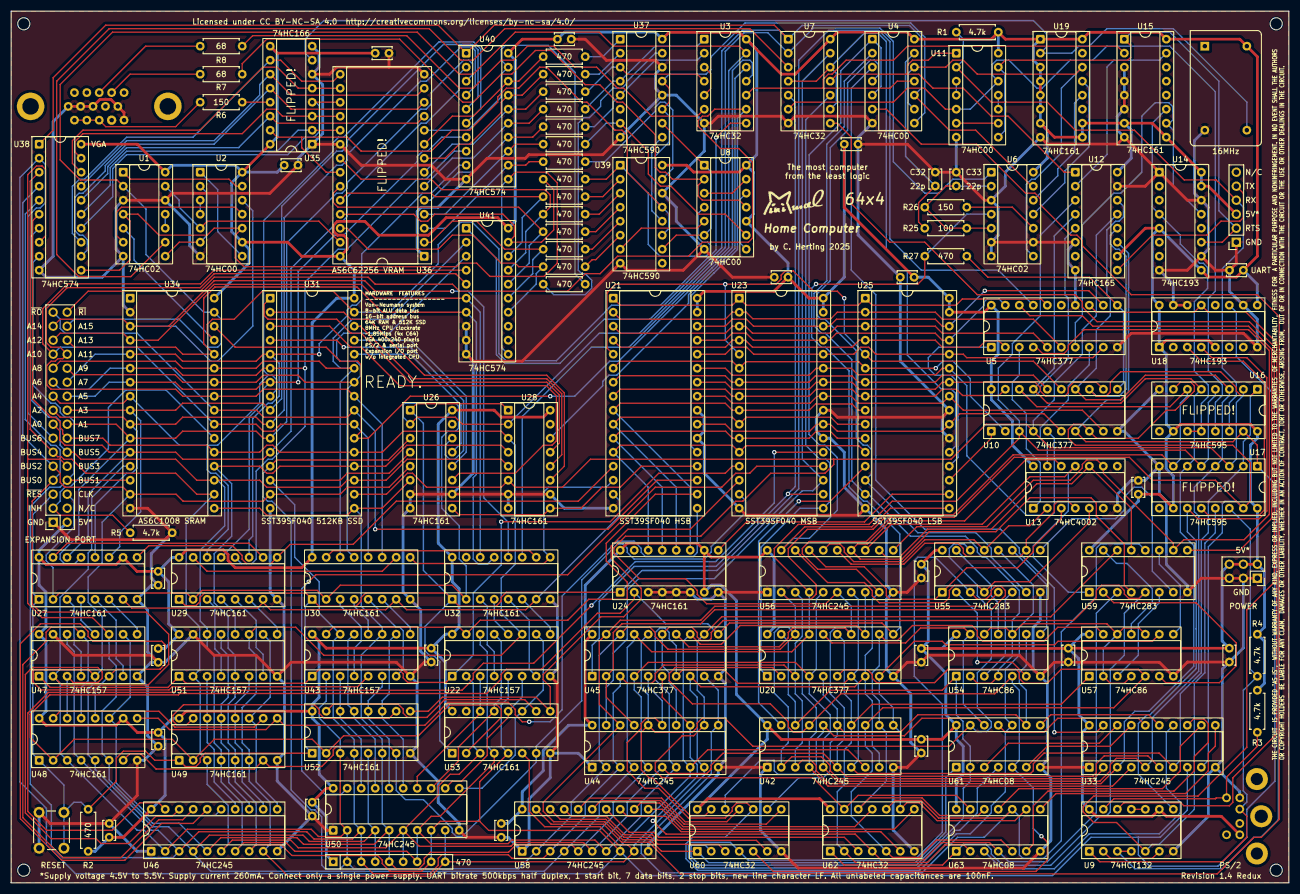
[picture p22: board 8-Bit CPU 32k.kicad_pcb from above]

Board: 2 copper layers, 231.8 x 158.1 mm, 122 parts (0 on the bottom side), 263 nets.

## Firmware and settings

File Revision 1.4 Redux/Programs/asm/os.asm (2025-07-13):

; ******************************************************************
; *****                                                        *****
; *****       MinOS 2 for the Minimal 64x4 Home Computer       *****
; *****                                                        *****
; ***** written by Carsten Herting - last update Feb 15th 2025 *****
; *****                                                        *****
; ******************************************************************

; CHANGE LOG
; REVISION 1.1 (Initial Release):
; 08.02.2024: Updating the keyboard handler timing to Minimal 64x4 speed.
; 09.02.2024: Cosmetic updates, changing quotation from ' to ".
; 10.02.2024: Rewriting 'mon' with cleaner code, now makes use of _ReadHex.
; 15.02.2024: Adding _ClearPixel function, renaming _Pixel to _SetPixel.
; 17.05.2024: Added support for 'autostart' batch file (Idea by Hans Jacob).
; REVISION 1.4 (Redux):
; 03.02.2025: CLV, CLQ is 1 cycle faster, now setting A=0 (CLZ, CLB still conserve A, which can be useful)
; 03.02.2025: XOR instructions are faster due to: xor(a,b) = and(or(a,b), not(and(a,b))) = or(a,b) - and(a,b)
; 03.02.2025: OUT is now waiting 160 cycles for UART transmission (no more waiting needed)
; 04.02.2025: New instructions ('M..' now covers all address modes, no mixing between abs and ZP addressing)
; 05.02.2025: New instruction CL5: much(!) faster _Clear, _ClearVRAM, faster _SetPixel, _ClearPixel
; 07.02.2025: _FlashA replaces _WaitUART in jump table. _FlashA is useful to move over data from _FindFile.
; 07.02.2025: 4% speed gain in OS_Line, 12% speed gain in OS_Rect, faster scrolling and ClearRow (for edit.asm)
; 08.02.2025: Improved _Print and _SerialPrint
; 09.02.2025: Improved _PrintChar (line breaks and page breaks are handled better)
; 09.02.2025: Updated some games (slowed down Invaders)
; 10.02.2025: Change microcode of CIZ, CIB, CIT, CIR, CZZ, CZT to "A holds target" instead of "A holds result"
;             This is more intuitive. The user may append CPIs. A "compare" should not store an actual result!
; 11.02.2025: Deleted instructions the "long" instructions AIL, SIL, ADL, SUL, NOL, NEL, INL, DEL
; 11.02.2025: Renamed store instructions from "STZ, STB, STT, STR" to "SDZ, SDB, SDT, SDR" ("store data register to")
; 11.02.2025: Added add/sub/compare instructions ATZ, STZ, CTZ, ATT, STT, CTT for better instruction set orthogonality
; 11.02.2025: Added CLD (clear data register A) and CVV (compare ZP word zo ZP word)
; 11.02.2025: Replaced "LD.\s\S+\sSD." with the more compact "MTT ..,.." in codebase
; 12.02.2025: Rename STS to SDS ("store data on stack").
; 14.02.2025: Replaced CLC, SEC with CIV, CIW (CLC is equivalent to "ADI 0", SEC is equivalent to "SBI 0").
; 14.02.2025: Improved min.asm with ZP addressing.
; 05.07.2025: Updated 'mon' UI

; HOW TO USE THIS CODE
; This is the sourcecode of the operating system MinOS 2 of the MINIMAL 64x4. A HEX file of the OS
; code can be produced by typing 'asm os.asm'. This HEX file can be burned into the first 3 banks of the
; 512KB FLASH SSD ROM of the MINIMAL 64x4. In case you already have a version of MinOS installed, the OS
; can also be updated 'in situ': Upload the HEX file into RAM by typing 'receive ENTER' and pasting the
; HEX file into a terminal to the MINIMAL 64x4 via the UART interface. The image will be written to the
; FLASH banks 0-2. Upon pressing RESET, the new OS boots. Your file data remains unchanged on the SSD.

; GENERAL INFORMATION
; o After boot-up, the Minimal 64x4 deactivates FLASH (sets BANK = 0xff), exposing all 64KB of contiguous RAM.
; o Outside the boot process, FLASH access is provided by the instructions R.. and W.. (see manual for details).
; o _<label> provide API access to kernel functions & data via a jump table.
; o 0xcc and 0xcccc denote "code subject to change" during runtime, i.e. self-modifying code.

; LICENSING INFORMATION
; This file is free software: you can redistribute it and/or modify it under the terms of the
; GNU General Public License as published by the Free Software Foundation, either
; version 3 of the License, or (at your option) any later version.
; This file is distributed in the hope that it will be useful, but WITHOUT ANY WARRANTY; without even the
; implied warranty of MERCHANMBBILITY or FITNESS FOR A PARTICULAR PURPOSE. See the GNU General Public
; License for more details. You should have received a copy of the GNU General Public License along
; with this program. If not, see https://www.gnu.org/licenses/.

; -----------------------------------------------------------------------------------
; Entry point after pressing RESET: BANK = 0x00, PC = MAR = 0x0000
; Please note that FLASH is active here. The zero-page must not be used by this code.
; -----------------------------------------------------------------------------------
#org 0x0000     MIW OS_Image_Start,0xfffc                     ; OS source address to 0xfffc/d
                MIW _Start,0xfffe                             ; OS target address to 0xfffe/f
  imcopyloop:   MRR 0xfffc,0xfffe                             ; copy the OS image from FLASH to RAM
                INW 0xfffc INW 0xfffe
                CIB <OS_Image_End,0xfffe FNE imcopyloop       ; target address beyond OS kernel?
                  CIB >OS_Image_End,0xffff FCC imcopyloop

OS_Image_Start: #mute #org 0xf000 #emit                       ; change OS target address but emit OS image here

  _Start:       JPA OS_Start                                  ; OS JUMP TABLE (will jump to OS_Start from here)
  _Prompt:      JPA OS_Prompt
  _MemMove:     JPA OS_MemMove
  _Random:      JPA OS_Random
  _ScanPS2:     JPA OS_ScanPS2
  _ResetPS2:    JPA OS_ResetPS2
  _ReadInput:   JPA OS_ReadInput
  _WaitInput:   JPA OS_WaitInput
  _ReadLine:    JPA OS_ReadLine
  _SkipSpace:   JPA OS_SkipSpace
  _ReadHex:     JPA OS_ReadHex
  _FlashA:      JPA OS_FlashA
  _SerialPrint: JPA OS_SerialPrint
  _FindFile:    JPA OS_FindFile
  _LoadFile:    JPA OS_LoadFile
  _SaveFile:    JPA OS_SaveFile
  _ClearVRAM:   JPA OS_ClearVRAM
  _Clear:       JPA OS_Clear
  _ClearRow:    JPA OS_ClearRow
  _ScrollUp:    JPA OS_ScrollUp
  _ScrollDn:    JPA OS_ScrollDn
  _Char:        JPA OS_Char
  _PrintChar:   JPA OS_PrintChar
  _Print:       JPA OS_Print
  _PrintPtr:    JPA OS_PrintPtr
  _PrintHex:    JPA OS_PrintHex
  _SetPixel:    JPA OS_SetPixel
  _Line:        JPA OS_Line
  _Rect:        JPA OS_Rect
  _ClearPixel:  JPA OS_ClearPixel
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

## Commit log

2024-04-05 I've used KiCAD 6.
2024-04-27 INQ/DEQ/INL/DEL bugfix
    [microcode_def.csv]
2024-05-12 Bugfix in parsing upper-case hex numbers.
2024-08-09 added clear cmd and fixed comments
    [os.asm]
2024-10-10 Cosmetic updates
    [8-Bit CPU 32k.dsn, 8-Bit CPU 32k.kicad_pcb, 8-Bit CPU 32k.kicad_sch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]
2025-02-06 Fixed bug in 'format' command
    [os.asm]

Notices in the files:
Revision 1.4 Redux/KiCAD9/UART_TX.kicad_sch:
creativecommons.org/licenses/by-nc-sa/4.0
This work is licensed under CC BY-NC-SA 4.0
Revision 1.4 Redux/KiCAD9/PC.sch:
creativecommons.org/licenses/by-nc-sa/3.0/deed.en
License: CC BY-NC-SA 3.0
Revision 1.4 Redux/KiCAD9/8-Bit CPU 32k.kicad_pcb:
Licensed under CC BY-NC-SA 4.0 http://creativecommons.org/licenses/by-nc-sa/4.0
